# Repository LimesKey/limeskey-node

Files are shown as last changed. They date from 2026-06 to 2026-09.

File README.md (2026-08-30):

# parsnip-node
A battery-powered, portable Meshtastic/Meshcore node built around a Seeed XIAO ESP32-C6, an Ebyte E22P-915M30S LoRa front end, and a u-blox NEO-M9N GNSS receiver. Designed in KiCad, it targets 915 MHz operation in Canada under ISED RSS-247.

## Overview

The goal is a self-contained LoRa node that pairs one of the longest range, best value LoRa modules, with an accurate GNSS reciever, running off a single 18650 cell, to connect to other people on the LoRa mesh network community.

<table>
  <tr>
    <td align="center" width="33%">
      Assembled parsnip-node board on the bench
      <br><sub><b>Assembled board</b></sub>
    </td>
    <td align="center" width="33%">
      parsnip-node during outdoor testing, front
      <br><sub><b>Outdoor testing</b></sub>
    </td>
    <td align="center" width="33%">
      parsnip-node during outdoor testing, back
      <br><sub><b>Outdoor testing, back</b></sub>
    </td>
  </tr>
</table>

## Hardware
 
| Function | Part | Notes |
| --- | --- | --- |
| MCU / radio host | Seeed XIAO ESP32-C6 | Used as an SMD/castellated module for easy soldering|
| LoRa | Ebyte E22P-915M30S | SX1262 + external PA, up to 30 dBm |
| GNSS | u-blox NEO-M9N | GPS / GLONASS / Galileo / BeiDou |
| Boost | TI TPS61033 |  |
| Power mux | TI TPS2116 | USB / battery source selection |
| Battery protection | TI BQ29700 | Single-cell protection |
| Reverse polarity | AO3401A P-channel MOSFET | Input protection |
| Cell | 18650 3500mAh Li-ion | Single cell |
 
### Board
 
- 4-layer, 55 x 100 mm
- JLCPCB `JLC04161H-7628` stackup, 1 oz copper
- L1-L2 prepreg 0.2104 mm, Dk 4.4
- RF: 0.36mm trace width for ~50 Ω CPWG on this stackup, ground rails stitched with 0.3 mm / 0.6 mm vias at roughly 1.5 to 2 mm pitch
  
### SX1262 to ESP32-C6 pin map
 
| Signal | GPIO |
| --- | --- |
| NSS | 21 |
| SCK | 19 |
| MISO | 20 |
| MOSI | 18 |
| DIO1 | 1 |
| BUSY | 7 |
| NRST | 16 |
| EN | 17 |
 
The E22P `EN` (module pin 6) is held high for both RX and TX. The T/R switch (pin 7) is driven automatically from the SX1262 DIO2 line, so the firmware sets `setDio2AsRfSwitch(true)`.
 
## Firmware
 
Firmware is a Meshtastic fork tracked as the `firmware` submodule ([LimesKey/firmware](https://github.com/LimesKey/firmware)). Development uses VS Code with the pioarduino extension, which Meshtastic pins for ESP32-C6 / Arduino-ESP32 3.x support. A device variant declares the pin map above and the PA control lines so TX actually keys up. Unfortunately there are some extensive changes to the Meshtastic firmware in order to incorporate a SPI GNSS module, as this is not natively supported by Meshtastic.
 
```bash
git clone --recurse-submodules https://github.com/LimesKey/parsnip-node.git
```

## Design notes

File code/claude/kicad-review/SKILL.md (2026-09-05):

---
name: kicad-review
description: Query and review KiCad netlists (.net), schematics (.kicad_sch), board placement (.kicad_pcb) and datasheets, and draw schematics: knet.py, kpcb.py, ksch.py, kdoc.py. Use for any question touching a KiCad schematic, netlist, ERC, BOM, footprint, pin, net, connectivity, decoupling or power rail ("what does U2 pin 9 connect to"), and for board layout, placement, floorplan, footprint position, courtyard, edge clearance, mounting hole or keepout ("is U8 too close to the antenna"). `kpcb.py FILE ic U13` also RECOMMENDS where a regulator's caps, inductor and feedback divider go, with a diagram: use it for "where do these go", "lay out this buck/LDO", "minimise the switching loop". Never answer connectivity or geometry from memory or by eyeballing a schematic or board image; exports go stale within a session. Use it too for ANY request to draw or show a circuit, even one not on the board yet: ksch.py draws real symbols from a text spec and hand-written SVG is never right.
---

# KiCad netlist review, placement review and schematic drawing

Four stdlib-only tools in this skill's `scripts/`. Nothing to install.

```bash
K=<skill>/scripts/knet.py   P=<skill>/scripts/kpcb.py
D=<skill>/scripts/kdoc.py   S=<skill>/scripts/ksch.py
```

| question | file | tool | reference |
| --- | --- | --- | --- |
| what is wired to what, values, BOM | `.net` | `knet.py` | [knet](references/knet.md) |
| where is it, does it fit, does it clash, where do the passives go | `.kicad_pcb` | `kpcb.py` | [kpcb](references/kpcb.md) |
| does it pass DRC/ERC, real clearance/rule violations | `.kicad_pcb` + roots | `kdrc.py` | [kdrc](references/kdrc.md) |
| what does the part's datasheet say | PDFs | `kdoc.py` | [kdoc](references/kdoc.md) |
| show me the circuit | - | `ksch.py` | [ksch](references/ksch.md) |

`knet check` and `kpcb check` are heuristics on the netlist and placement;
`kdrc.py` runs **KiCad's own** DRC (honouring `parsnip.kicad_dru`) and ERC, the
authoritative rules check. `kpcb.py FILE zones` reports pour-fill coverage.

`kpcb.py` needs `knet.py` beside it (shared parser) but does **not** need the
`.net` - pads carry their own net names and pin functions. Find the `.net` first:
usually beside the board, else `/mnt/project/*.net` or `/mnt/user-data/uploads/*.net`.
If `*.kicad_sch` files sit beside the `.net`, knet parses them as a sidecar
(no_connect flags, text notes, symbol positions).

## Order of operations

1. **Connectivity, values, footprints, part numbers -> `knet.py`.** The netlist is
   the only authoritative record of what is wired to what.
2. **Position, clearance, floorplan -> `kpcb.py`.** The board file is the only
   record of where anything actually is. Never infer geometry from a screenshot.
3. **Design rules, absolute maximums, recommended values -> `kdoc.py grep`.**
4. **Page image -> only when the drawing itself must be read.** `kdoc.py page DOC N`
   prints a path, then `view` it.

Never derive connectivity from a schematic plot: extracted text is spatially
scrambled. The plot only tells you which sheet a symbol lives on.

## Start here - the highest-value call per tool

| you want | one call |
| --- | --- |
| fresh session on a board | `kpcb.py FILE review` - sync + summary + check + span, then names the next calls to make |
| is the board the circuit I drew | `kpcb.py FILE sync` - **run before quoting any placement finding**; two lines when clean |
| where does X connect / is X right | `knet.py FILE around X` - pins, types, nets, position, every part one hop away |
| where is X, is there room | `kpcb.py FILE where REF` or `where 130,60 -r 10` |
| where do these caps/inductor go | `kpcb.py FILE ic U13` - positions, rotations, the rule behind each, and a picture |
| does the board pass real DRC + ERC | `kdrc.py FILE.kicad_pcb` - KiCad's own checks, all 3 roots, folded like `check` |
| is the ground pour filled / covering | `kpcb.py FILE zones` - fill coverage per copper layer |
| what voltage does this divider set | `knet.py FILE divider U5.OVLO` - nominal + worst case from real resistor values |
| unfamiliar board, what is on it | `knet.py FILE summary` then `check` |
| draw a circuit that exists | `knet.py FILE draw U8 -d 2 -o out.svg` |
| draw a circuit that does not exist yet | write a ksch spec, `ksch.py render` - see [ksch](references/ksch.md) |
| what does the datasheet say | `kdoc.py grep 'Y' --count` to pick the page, then grep with context |

More in [references/recipes.md](references/recipes.md), including the self-test to
run after editing any tool.

## Hard rules

- **Re-run the tool every time.** The `.net` and the board are re-exported
  constantly. Never trust a value, ref, net name or coordinate quoted earlier in
  the conversation, in a summary, or in a CLAUDE.md.
- **Never hand-regex a netlist or board file.** It bleeds nodes across net
  boundaries and produces confidently wrong counts.
- **Never hand-write SVG for a circuit.** `ksch.py` draws real symbols.
- **`check` findings are heuristics.** Confirm against the datasheet
  (`kdoc.py grep`) before calling anything a bug.
- **Output is capped on purpose.** Findings fold into `tail [N]: refs` lines and
  each rule stops after `--max`. The counts in the tails stay accurate even when
  not every item is printed: `+90 more OVERLAP line(s) (102 total)` means 102 real
  findings. Widen deliberately with `--only RULE` or `--max`, never by default.
- **Mid-placement, most of the BOM is parked beside the board.** Every kpcb check
  ignores anything outside the outline. `placed 135 of 439` is progress, not an
  error, and a part "not found" by `where` may not exist on the board yet.

Common traps that produce wrong answers - DNP as open circuit, ref-prefix
matching, rails being terminal, `unconnected-*` pseudo-nets, KiCad's `{slash}`
escaping, board y growing downward - are in
[references/gotchas.md](references/gotchas.md). Read it once per session before
any traversal or coordinate work.

Exit codes (both tools): 0 clean, 1 not found, 2 a check found an ERROR, 3 bad file.

Project config: `knet.json` / `kpcb.json` beside the file persist board defaults
and a `suppress` list for confirmed non-bugs. Precedence: defaults < json < CLI.
See the per-tool references.

# Related

Part sourcing (LCSC/DigiKey pricing, stock, verified datasheet URLs) is the
separate `part-search` skill. `part.py bom board.net` reuses this skill's parser.
Capacitor questions mid-review - "higher voltage rating or higher nominal
capacitance", DC-bias derating, effective uF in a footprint, voltage-stress life -
go to that skill's `kcap.py`, not to hand-computed derating curves.

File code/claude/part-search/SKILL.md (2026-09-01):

---
name: part-search
description: Look up and choose electronic components on LCSC, JLCPCB and DigiKey with part.py. Does parametric selection (e.g. a ceramic cap 4.7uF-100uF rated >=25V, cheapest first), finds cheaper drop-in alternates for a part on the board, reports JLCPCB Basic vs Extended and $3/line assembly fees, runs one-shot board sourcing triage, and returns pricing ladders, stock, MOQ and a verified datasheet URL. Use this whenever the user asks about a specific component, an LCSC C-number, an MPN, a distributor price, whether something is in stock, what a part costs at some quantity, what the datasheet link is, asks to compare two parts, asks to pick or find a part meeting electrical constraints, asks whether a part is JLC Basic, or asks to price or source a whole board. Use it instead of web search for anything part-shaped, and never hand-write a scraping script for LCSC - the working endpoints are already recorded here and the obvious ones are blocked.
---

# Distributor part search and selection

`scripts/part.py` is stdlib-only Python 3. No install, no API key needed for LCSC or JLC.

```bash
P=<this-skill>/scripts/part.py
python3 $P selftest
python3 $P pick MLCC --cap 4.7u..100u --volt '>=25' --pkg 0805 --diel X7R,X5R
```

## Pick the command by what is being asked

| the question | command |
| --- | --- |
| "find me a cap 4.7-100 uF, >=25 V, cheapest" | `pick` - see [pick](references/pick.md) |
| "is there something cheaper than C45783" | `alt C45783` |
| "what does C18164413 cost / is it stocked" | `show` |
| "is this part JLC Basic", "what are my assembly fees" | `jlc` - see [endpoints](references/endpoints.md) |
| "datasheet link for X" | `ds` |
| "X vs Y" | `compare` |
| "what does this whole board cost" | `bom` |
| "source this board" / "what's blocking assembly" | `check` - `bom` + `jlc` + missing-code triage in one call |
| bare MPN, no constraints, just find it | `search` |
| "higher voltage rating or more nominal uF?" / DC-bias derating | `kcap.py` - see [kcap](references/kcap.md) |

`search` is keyword-only and ranks badly on parametric queries.
`search '22uF 25V X7R 1206'` returns electrolytics and tantalums in the top hits,
because LCSC has no category filter. **For anything with electrical constraints, use
`pick`, not `search`.**

## Commands

| command | use |
| --- | --- |
| `pick 'MLCC' --cap 4.7u..100u --volt '>=25'` | parametric selection, sorted, filtered |
| `alt C45783` | cheaper/stocked/Basic equivalents of a part already on the board |
| `jlc board.net` | Basic vs Extended per part + total $3/line assembly fees |
| `show C18164413` | ladder, stock, MOQ, multiple, params, category, verified datasheet |
| `ds C42409135` | datasheet URL only, with pass/fail per candidate |
| `compare C1525 C60474` | side-by-side, differing parameters only |
| `search 'TPS61033'` | keyword search. Add `--instock`. |
| `bom board.net --qty 5` | prices a whole KiCad netlist by its LCSC Part property |
| `check board.net --qty 5` | one-shot sourcing triage: `bom` pricing + `jlc` Basic/Extended, one table, one pass over the netlist |
| `selftest` | which providers and the FX rate source work right now |

`show`, `ds`, `compare` and `alt` accept a C-code, a bare MPN, or a pasted LCSC URL.
`show` with several SKUs prints one verbose block per part by default; `--table`
switches to one compact row per part, `--json` for machine-readable output.
Exit codes: 0 ok, 1 nothing found.

## Run selftest first in a new session

LCSC has no public API. `part.py` uses undocumented endpoints that can start
returning 403/404 without notice. `selftest` reports in one line which providers are
alive, so you never debug endpoints by hand or rebuild a scraper.

If a provider shows DEAD, the endpoint moved. **The constants are at the top of
`part.py`. Do not write a replacement script; fix the constant.** The full probed
endpoint table, and the exhaustive list of LCSC filter/sort parameters that were
tested and do not work, are in [references/endpoints.md](references/endpoints.md).
That file exists so nobody re-probes them. Read it before touching the HTTP layer,
not before a normal query.

## Hard rules

- **Two catalogs, never add them together.** `show`, `search`, `compare`, `bom` and
  `pick --source lcsc` report **LCSC retail** prices. `jlc` and `pick --basic` report
  **JLCPCB assembly-catalog** prices. Different numbers for the same part. Always say
  which one you are quoting.
- **A trailing `!` on a price means FX was unreachable** and the native currency is
  shown unconverted. Never add a `!` price to a converted one. Default currency is
  CAD; LCSC arrives in USD, converted at a daily cached rate with the native figure
  in parentheses. `--currency USD` switches everything.
- **`bom` totals exclude shipping, tax, PCB fabrication and assembly.** Say so when
  quoting a per-board cost. Extended line fees are `jlc`'s job, not `bom`'s.
- **Never regex a netlist for `C\d+`** to find LCSC codes - that matches capacitor
  refdes like `C108`. `jlc`/`bom` parse the `LCSC Part` property via kicad-review's
  `knet.py`.
- **Do not infer Basic/Extended from a JLC keyword search** - its relevance ranking
  drops parts that do exist in the library, showing as a false `-`. Use `--basic` or
  the `jlc` command.
- **Check the `resolved:` line** that `pick` prints when a shorthand mapped to a
  differently-named LCSC attribute. If it resolved wrong, use `--w` with the verbatim
  name.
- **Datasheet links are verified, not returned on faith** (HTTP status, content type,
  `%PDF` magic). A BROKEN report is real - do not paste the URL anyway.

## What the tool does that a hand-rolled script will not

- Verified datasheet links, falling through to the next candidate then the product
  page. Manufacturer links with expiring `?ts=` tokens are exactly what this catches.
- Quantity pricing respects MOQ and order multiple, and says when it rounded up.
- Numeric comparison is numeric - value normalisation drops the decimal point, so a
  text match would treat `2.2uF` and `22uF` as identical.
- Disk cache, 24 h TTL, `~/.cache/partsearch`. A warm `pick` is ~1 s against a ~10-30 s
  cold one. `--fresh` when stock matters.
- `bom` honours DNP and `exclude_from_bom`, and separately lists placed parts with no
  LCSC number at all - the ones actually blocking assembly.

Stock is authoritative from the detail endpoint; a 0 in search results is a real 0.
`pick` shows `unit@N` and `ext` (= unit x the actual buy quantity after MOQ rounding).

DigiKey is optional and participates in `search`/`show` only, not `pick` - setup in
[references/endpoints.md](references/endpoints.md).

## Related

`kicad-review` provides `knet.py`, whose netlist parser `bom` and `jlc` import when
both skills are installed. Without it, `bom` falls back to regex and `jlc` refuses
`.net` input rather than risk matching refdes.

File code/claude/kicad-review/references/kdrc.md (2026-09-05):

# kdrc.py - real DRC + ERC via kicad-cli

The authoritative rules check. `kpcb.py check` and `knet.py check` are heuristics
on geometry and the netlist; `kdrc.py` runs KiCad's **own** Design Rules Check
(which applies `parsnip.kicad_dru` automatically) and Electrical Rules Check, and
folds the results into the same finding format as the other tools.

```bash
D=<skill>/scripts/kdrc.py
python3 $D parsnip.kicad_pcb            # DRC + ERC
python3 $D parsnip.kicad_pcb drc        # DRC only
python3 $D parsnip.kicad_pcb erc        # ERC only, every root schematic
```

## What it does

- **DRC** runs on the board with `--refill-zones` so results reflect current
  pours. It never passes `--save-board`: the refill is in memory, the on-disk
  `.kicad_pcb` is not modified.
- **ERC** runs once per **root** schematic. Roots are auto-discovered: every
  `*.kicad_sch` beside the board that no other schematic pulls in as a sub-sheet.
  For parsnip that is `parsnip`, `battery`, `usb_interface`. A bare single-root
  ERC misses two of them, the same blind spot as a bare netlist export.
- Output: findings grouped by rule, capped per rule with a `+N more` tail,
  suppressible via `kdrc.json`, exit 0/2/3 like `kpcb`.

## The one caveat that matters

**Per-root ERC cannot see cross-root nets.** A pin powered or driven through a
global label whose driver is on another root (`I2C_HOST_*`, `USB D+/-`, the
shared rails) reads as `power_pin_not_driven` or `pin_to_pin` here. Those are
three-root false positives. Confirm each against the merged netlist before
believing it:

```bash
python3 <skill>/scripts/knet.py parsnip-merged.net around REF
```

DRC has no such blind spot - it is one board file.

## Flags

| flag | effect |
| --- | --- |
| `--max N` | cap lines per rule (default 25, or `max` in kdrc.json) |
| `--only R1,R2` / `--skip R` | keep or drop rules by name (e.g. `DRC:CLEARANCE`) |
| `--unconnected` | include the DRC `unconnected_items` (unrouted nets; hidden by default because mid-layout there are hundreds) |
| `--parity` | add DRC schematic-parity. Noisy: it uses the single project root, so it will flag all of /Charger/ and /USB Interface/. |
| `--all` | pass `--severity-all` to kicad-cli. Here kicad-cli already ignores the `.kicad_pro` severities, so this rarely changes anything. |
| `--no-suppress` | ignore kdrc.json |
| `--rules` | print the rule legend |
| `--json` | machine-readable findings |

## kdrc.json (beside the board)

Same shape and precedence as `kpcb.json`. A bare `PREFIX:RULE` mutes the whole
rule; `PREFIX:RULE:TOKEN` mutes only findings whose refs or message contain
TOKEN. Rule names are the kicad-cli `type`, upper-cased, prefixed `DRC:`/`ERC:`.

```json
{"max": 25,
 "suppress": ["ERC:LIB_SYMBOL_MISMATCH", "ERC:SINGLE_GLOBAL_LABEL",
              "ERC:ISOLATED_PIN_LABEL", "ERC:FOUR_WAY_JUNCTION"]}
```

Pre-muted classes and why: `LIB_SYMBOL_MISMATCH` = the 16 deliberately edited
symbols (CLAUDE.md); `SINGLE_GLOBAL_LABEL` / `ISOLATED_PIN_LABEL` = global labels
that join across the three roots and so look single-use per root;
`FOUR_WAY_JUNCTION` = drawing style. `pin_to_pin`, `power_pin_not_driven` and
`footprint_filter` are left visible on purpose - triage them, then add the
confirmed-benign ones here.

## Notes

- ERC item positions are sheet-local coordinates, not board mm; the ref is the
  locator. DRC item positions are board mm and are kept in the message.
- kdrc shells `kicad-cli` (KiCad 8-10). If it is not on PATH, kdrc exits 3.
- Mid-layout, DRC `unconnected_items` (unrouted) dominate. Route first, then care
  about them; until then `--unconnected` is opt-in.

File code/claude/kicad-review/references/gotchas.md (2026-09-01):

# Facts that are easy to get wrong

Read this once per session before any traversal or coordinate work.

## Netlist

- **The `.net` is re-exported constantly.** Re-run the tool. Do not trust a value,
  ref or net name quoted earlier in the conversation or in a summary.
- **DNP parts are open circuits by default.** A DNP 0 R in series means the path
  does not exist on the built board; `walk`/`path`/`draw` stop there. `--as-drawn`
  restores schematic-as-drawn traversal; DNP parts still render, dashed.
- **Ref prefix matching must use the full alphabetic prefix.** `JP` is not `J`.
- **Rails are terminal in traversal.** A path through GND or +3V3 is not a path.
  Treat nets over ~8 nodes as rails.
- **Floating pins rarely show as "absent from all nets".** KiCad emits pseudo-nets
  named `unconnected-(REF-PIN-PadN)`. A **named** single-node net is usually a real
  bug (a label going nowhere); `unconnected-*` is an intentional NC or a forgotten
  pin - the sidecar NC annotation tells you which.
- **A part is pass-through if it has exactly two connected pins**, rails included.
  Series resistors bridge two nets: trace both ends.
- **KiCad escapes text**: `{slash}` is `/`, `~{FLT}` is an overbar. Drawings decode
  both; netlist queries use the raw escaped name.
- **Label *shape* is cosmetic; only the *name* connects.**

## Board

- **Mid-placement, most of the BOM is parked in a pile beside the board.** Every
  kpcb check ignores anything whose centre is outside the outline, or the pile would
  drown the findings. `placed 135 of 439` in a header is progress, not an error. A
  part "not found" by `where` may simply not exist on the board yet.
- **`.kicad_pcb` y grows downward** and rotation is counter-clockwise on screen, so
  a footprint's child geometry transforms as `x + lx*cos - ...`, not the textbook
  rotation. `where` already prints board coordinates; do not re-derive them from
  `(at ...)` by hand.
- **A `.kicad_pcb` pad carries its own net name and pin function**, so kpcb needs no
  `.net` export. That also means the board can be out of date with the schematic: if
  kpcb and knet disagree about a net, the board has not been re-synced. Run
  `kpcb.py FILE sync` before quoting any placement finding.
- **Ref designators move during layout.** Do not cache them across sessions.

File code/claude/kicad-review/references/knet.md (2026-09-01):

# knet.py - netlist connectivity, values, ERC, BOM

`knet.py FILE <cmd>` - file first, then subcommand.

| command | use |
| --- | --- |
| `summary` | comps, sheets, rails, DNP list, largest nets. Run first on an unfamiliar board. |
| `around REF...` | **highest value per call.** Pins, types, nets, position, every part one hop away. Use instead of `comp` + several `pin` calls. |
| `check` | 16 rule-based findings, grouped ERROR/WARN/INFO. Exit 2 if any ERROR. Three or more findings sharing a message fold into one line, `tail [N]: refs` - `[49]` means 49 separate findings, not one. |
| `check --since old.net` | only findings NEW vs an older export, plus a fixed/unchanged tally. |
| `draw REF\|NET [-d N] [-o x.svg] [--spec]` | KiCad-style schematic from the netlist; `--spec` gives the editable ksch source. |
| `notes` | schematic text notes by sheet - designer intent that exists nowhere in the netlist. |
| `rails` | each power rail: what feeds it, total decoupling, loads. |
| `divider REF.PIN\|NET` | resistor-divider trip voltage from netlist resistor values, worst case from tolerance if stated. See below. |
| `diff old.net` | what changed vs an earlier export (rename-safe: compares neighbour sets). |
| `comp REF...` | pin table with net, node count, supply rail. |
| `net PATTERN` | exact name, then sheet-local name, then regex. |
| `pin U2.9` | net at a pin plus everything else on it. |
| `find PATTERN` | searches refs, values, footprints, properties, pin functions, net names. |
| `walk REF[.PIN] -d N` | expand outward through 2-pin passives. |
| `path A B` | shortest electrical path between two parts. |
| `bom [--sheet PATH]` | grouped, DNP separated, flags parts with no LCSC number. `--sheet /Root/Rails/` scopes to one hierarchical sheet and everything nested under it. |
| `unconnected` | floating pins, `[NC flag]` vs `[NO NC flag]` with the sidecar, plus single-node nets. |
| `sheets` | components per hierarchical sheet. |

## Reading `around`

One line per pin, then its peers indented under it. The pin-type column is omitted
when the symbol types every pin `unspecified` (easyeda2kicad does), so a missing
type means unknown, never `passive`. A net already shown on an earlier pin of the
same part prints bare, or `(peers listed at pin N)` - that is two pins on one net,
not a different net.

## `divider`

`REF.PIN` accepts the pin's declared NAME (`U5.OVLO`, or the raw KiCad-escaped
`U14.EN{slash}UVLO`) as well as its number. Handles a plain 2-resistor divider
automatically. For TI's 3-resistor UVLO/OVLO string
(`IN->R1->EN/UVLO->R2->OVLO->R3->GND`, every TPS2594x/hot-swap part) it auto-detects
the shape and reports VIN_UV/VIN_OV once given `--vth <threshold from the
datasheet>`; add `--vth-tol <%>`, since the IC's own threshold accuracy usually
dominates the resistor tolerance. Use it for any FB/OVLO/UVLO/ADC-sense divider
instead of tracing it by hand across several `pin`/`net` calls.

## Flags

`--through R,L,FB,F,FL,JP` (pass-through prefixes; add `C`/`D` to trace through caps
or diodes), `--fanout N` (nets above N nodes are rails, default 8), `--as-drawn`
(traverse DNP parts too; **default treats DNP as open circuits**),
`--rail '+5V=5,VCC_RF=3.3'`, `--peer-max N`, `-o FILE`, `--spec`, `--theme`,
`--json`, `--only`/`--skip RULE,RULE`, `--rules` for the rule legend,
`--no-suppress` (for `check`), `--sheet PATH` (for `bom`), `--vth V` /
`--vth-tol PCT` (for a 3-resistor `divider`).

`walk` caps a rail's load list at 10 with a `+N more (rail net, N total)` tail once
a net is a named rail or above `--fanout`. The count in the tail stays accurate even
when not every load is printed.

## Project config

`knet.json` next to the netlist persists board defaults:

```json
{"rails": {"+BATT": 8.4}, "fanout": 8, "suppress": ["RFSTUB:GPS_ANT", "OCNOPULL:U9"]}
```

Precedence: defaults < knet.json < CLI.

`suppress` mutes `check` findings already confirmed not to be bugs, so they stop
costing tokens on every future review instead of restating "don't re-flag this"
each session. An entry is `"RULE"` (mute the whole rule) or `"RULE:TOKEN"` (mute
only findings naming that ref or net - a confirmed false positive on one net must
not hide a real one elsewhere). `check` reports how many it muted; verify the count
looks right, and use `--no-suppress` after a big rewire to see everything again.

## check rules

`FLOATPWR NCDRIVEN SOLO CONTEND DOMAIN DECOUPLE OCNOPULL I2CPULL PASSONLY RFSTUB
DNPPATH CAPRATING NOVALUE GNDISLAND CLAMPRATING PARPIN`. `--rules` for one-line
descriptions. With the sidecar, FLOATPWR downgrades to WARN when the schematic
carries an explicit NC flag.

- **`DOMAIN`** is the useful one: it infers each net's pulled-to voltage from series
  resistors and ferrites to named rails and compares against each IC's supply rail,
  catching pull-ups to 5 V on 3.3 V logic.
- **`PARPIN`** catches a paralleled pad left floating: two or more pins on the same
  part sharing the same declared pin NAME (e.g. multiple BAT pins on a charger IC)
  where one is wired to a real net and a sibling is not. Matches on pin name rather
  than pin type, so it still fires when the symbol types the dangling pin `passive`
  rather than `power_in` - the case that let a real floating BAT pin slip past
  FLOATPWR.
- **`CLAMPRATING`** parses a TVS's standoff voltage from a recognised part-number
  series (SMF/SMAJ/SMBJ/SMCJ/SM6T/SM8S/P6KE/1.5KE/P4KE) and flags it against the
  named rail it sits on between rail and GND - narrow by design (only those series,
  no margin math beyond "not below") to avoid a confidently wrong number. The rail
  figure is name-derived or `--rail`/knet.json, not the regulator's true analog
  output, so a finding here can understate the real gap; it will not overstate it.
- **`GNDISLAND`** catches a different shape of bug than FLOATPWR: pins named like
  ground (GND, AGND, VSS, ...) that ARE wired to each other but never reach the
  board's real GND net - a merge that silently didn't happen. `is_gnd()` recognises
  these by pin name even on an auto-generated net (`Net-(U7-GND-Pad1)`), so DECOUPLE
  no longer misfires on them as "missing a bypass cap".

**These are heuristics. Confirm against the datasheet before calling anything a
bug.** Worked example: `U7.5 (FB)` on a TPS61033 sat on the same net as `VIN` -
looks like a broken feedback loop, but the datasheet says that is the documented
fixed-5.0 V configuration. The correct move was `kdoc.py grep 'FB' -d tps` first.

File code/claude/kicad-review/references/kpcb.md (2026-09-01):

# kpcb.py - placement review

Placement review from the `.kicad_pcb` alone. No routing, no DRC, no 3D bodies -
everything here is checkable the moment a footprint is dropped.

| command | use |
| --- | --- |
| `summary` | outline size, stackup, zones, how much of each sheet is placed, biggest parts. Run first. |
| `check` | 10 rule-based findings, grouped ERROR/WARN/INFO. Exit 2 if any ERROR. |
| `where REF...` | **highest value per call.** Position, rotation, courtyard, edge distance, class, nets, and every neighbour within `-r`. Use instead of eyeballing coordinates. |
| `where X,Y -r N` | same, around a bare coordinate - "is there room here". |
| `map [--side f\|b] [--cols N]` | ASCII occupancy map, one letter per schematic sheet. Shows the floorplan and the free space in ~50 lines. |
| `sheet [PATH]` | per-sheet placed/left counts, bounding box, spread, and parts that drifted from their block. |
| `unplaced` | what is still parked off the outline, ref-ranged by sheet, biggest first. |
| `ic REF` | **where the passives should go**, not just what is wrong. See below. `ic` alone lists the parts worth asking about. |
| `span` | nets ranked by how far apart their placed pads sit. The one routing-quality number that exists before routing does. |
| `sync [board.net]` | **run this first.** Board vs netlist: same parts, footprints, values, DNP flags and net on every pad. Finds a `.net` beside the board automatically. |
| `review [board.net]` | one call for a fresh session: sync, summary, check, longest nets, then the specific next calls worth making. |

## Flags

`-r N` (neighbour radius, 5), `--max N` (cap per rule / per neighbour list, 12),
`--cols N` / `--side f|b` (for `map`), `--only`/`--skip RULE,RULE`, `--rules`,
`--json`, `--no-suppress`, and one threshold per rule: `--edge 0.5` `--hole 1.5`
`--conn 10` `--rf 8` `--therm 8` `--bypass 3` `--clear 0` `--fb 4` `--gap 0.25`
`--tol 1` `--span 0` (all mm; `--span 0` means half the board diagonal), plus
`--fanout 8`. For `ic`: `--anchor REF`, `--cin REF,REF`, `--cout REF,REF`,
`--ncin 3`, `--ncout 3`, `--assoc 6`.

## Project config

`kpcb.json` next to the board, same shape and precedence as `knet.json`:

```json
{"edge": 0.3, "bypass": 4.0, "suppress": ["OVERLAP:BT1", "UNPLACED"]}
```

Use `suppress` for placements already confirmed deliberate (thermistors under a
cell, a module antenna overhanging the edge) so they stop costing tokens on every
review.

## `sync` - is the board even the circuit you drew

`kpcb.py board.kicad_pcb sync` (the `.net` beside the board is found on its own).
**Nothing else here means anything if this fails.** A board that was never
re-synced after a schematic change carries pad net names that look perfectly valid,
so neither the board file nor any check on it can tell you it is stale - only the
netlist can. Rules: `SYNCPART SYNCFP SYNCVAL SYNCDNP SYNCNET`.

Clean output is two lines (`IN SYNC`), so it is cheap to run every time. A `SYNCNET`
error means re-run KiCad's *Update PCB from Schematic* before reading any other
finding. `SYNCVAL`/`SYNCDNP` alone are annotation drift: worth fixing, but the
connectivity is still right and placement findings still hold.

`unconnected-*` pseudo-nets get a `_1` suffix on the board and not in the netlist;
that is normalised away rather than reported as 439 differences.

## `review` - the whole placement picture in one call

Runs sync, `summary`, `check` and the top of `span`, then prints a **next** block
naming the exact calls worth making on *this* board - `ic` on the unplaced
regulators, `where` on whichever refs appear in the most ERROR findings, `map` if
much is still unplaced. That last block is the point: it is the reasoning a session
would otherwise have to do itself from a summary it has not read yet. If the board
is out of sync it says STOP and explains that everything below is about a different
circuit.

## check rules

`OVERLAP EDGECLR HOLECLR CONNACC RFNOISE THERMAL BYPASS NETSPAN NOCRTYD UNPLACED`.
`--rules` for the legend.

- **`OVERLAP`** compares courtyard **bounding boxes**, not their true outlines, so a
  rotated or L-shaped part reports a slightly larger box than it occupies -
  conservative, never permissive. Parts on opposite sides only collide where a
  drilled barrel actually lands in the other's area; a back-side battery holder
  sitting over front-side 0402s is not a finding.
- **`EDGECLR`** is an ERROR when the courtyard crosses the outline, a WARN when it
  is merely inside `--edge`. An edge-mount part (SMA, U.FL, USB-C, `EdgeMount` in
  the footprint name) crossing the edge downgrades to INFO - that is what it is for.
- **`HOLECLR`** keepout radius is the hole's own pad/drill radius plus `--hole`. It
  also catches a mounting hole placed outside the board entirely.
- **`CONNACC`** has two halves: a connector further than `--conn` from any edge, and
  a connector whose cable-exit corridor (its courtyard swept straight out to the
  nearest edge) is blocked by another part. The corridor is axis-aligned only - a
  diagonal exit is not modelled, and neither is component height.
- **`RFNOISE`** needs a switching node. Those are found by pin NAME (`SW`, `LX`,
  `PH`, ...) plus, as a fallback for a switcher whose pin is unnamed, the nets of a
  power inductor (>=1uH **and** >=6 mm2 of courtyard, which is what separates a buck
  inductor from a 470nH 0603 antenna match). Named power rails are excluded, or
  every load on +3V3 would look noisy.
- **`THERMAL`** pairs heat sources (power inductors, switching/charger/eFuse/LDO
  parts) against heat-sensitive ones (crystals, oscillators, battery cells, the GPS
  module). Thermistors are deliberately **not** sensitive - sitting next to
  something hot is their job. Cross-side pairs are reported and labelled: heat
  couples through the board.
- **`BYPASS`** measures each supply pin to the nearest **placed** cap on the same
  net. It stays quiet when no cap on that net is placed yet. Matched on pin NAME,
  never on `pintype`: easyeda2kicad types nearly every pin `passive`, so a
  type-based test would silently check nothing - the same trap `PARPIN` documents
  in knet.
- **`NETSPAN`** is the only rule that looks at wiring: a **fully placed** non-rail
  net whose pads sit further apart than `--span` (default half the board diagonal).
  Fully placed only, because a net still waiting on parts will move. Rails are
  excluded by node count **and** by name. `span` is the detailed view of the same
  data, ranked and capped.
- **`UNPLACED`** prints **one folded line per sheet**, never one per part.
- Two things that used to fire on a half-placed board and no longer do: a mounting
  hole sitting in the parked pile is INFO, not an ERROR about being off the board
  (an error still, if it is out there on its own); and an RF module whose antenna
  end overhangs the outline is INFO with a note to check the keepout, because that
  is how a WROOM or an E22 is meant to be placed.

**These are geometric heuristics.** They know nothing about component height, the
enclosure, keep-out zones you have not drawn, or your assembler's rules. Confirm
anything that matters against KiCad's own DRC and the mechanical drawing.

## `ic REF` - where the passives go

The only command here that answers "where should this go" instead of "what is
wrong". One call per regulator, ~35 lines, no reasoning required from the caller.
Run `ic` with no ref first to see which parts it can advise on.

Nothing is templated per part number: pins are classified by NAME (`VIN` `PGND`
`SW` `FB` `BOOT` `VCC/BIAS` `OUT`, with a blank pin sitting on GND counted as a
ground pin), and every position comes out of the real pad coordinates in the board
file. So a part it has never seen works, and a part whose pins are unnamed degrades
to "nothing positionable found" rather than to a confident wrong answer.

| role | where it is put | why |
| --- | --- | --- |
| input caps | straddling the **tightest VIN/PGND pad pair**, on the outside face of the package, smallest value innermost, extra caps stacked outward | that pad pair carries the high-di/dt loop; a cap across it *is* the small loop |
| inductor | hard against the SW pad(s), body pointing away from the package. Two switch nodes (a 4-switch buck-boost like the BQ25798) -> it bridges them instead | SW-pad-to-inductor is the other edge of the same loop, and the SW node is the antenna |
| output caps | a bank across the output node at the inductor's far pad, largest first | load current flows through them; a line of caps end to end would put the last one 25 mm downstream |
| feedback divider | out the far side of the package from SW, FB pad facing the IC | FB is the high-impedance node; it must not run past the SW pad or under the inductor |
| boot / bias caps | against the pins they serve | small loops of their own |
| a linear reg or load switch | no inductor, so the output cap straddles OUT/GND the same way the input cap straddles IN/GND | same rule, no switching node |
| a plain IC (no VIN pin) | supply pins found via the same name table `BYPASS` uses, caps straddling supply/GND | bypass placement is the loop rule at a smaller scale |

Rotations are snapped to 90 degrees. A pin pair on a diagonal would otherwise ask
for a 165.3-degree part, and the few degrees of loop cost nothing.

**`--anchor` is what makes it usable mid-placement.** The big parts land first, so
the inductor is usually down while the regulator is still in the parked pile. Given
that, "L4 is 90 mm from its slot" is true and useless - the inductor is not what
should move. So when the IC is unplaced and one of its passives is not, `ic` hangs
the whole layout off that part and reports **where the IC itself goes**.
`--anchor REF` picks a different one, `--anchor none` turns it off. Translation
only: if the anchor also needs turning, it says so and asks you to rotate the IC in
KiCad and re-run, because rotating it moves every pad.

The `now` column compares against what is already placed: `OK` (within `--tol`),
`4.8 mm / 90 deg off`, or `unplaced`. It also reports parts standing in a suggested
slot, feedback parts within `--fb` of a switching node, and the current input-loop
length against the suggested one.

**The honest limit is which caps belong to which regulator.** On a rail like `VSYS`
(20+ caps here) nothing in a `.kicad_pcb` says which cap the schematic drew next to
which pin. `ic` ranks by schematic sheet and by refdes proximity to the IC's own
private-net parts, prefers one cap of each distinct value so "smallest innermost"
means something, takes `--ncin`/`--ncout` of them, and **says in the output that it
guessed**. Two regulators on one rail can be offered the same cap. Check it against
the schematic and pass `--cin`/`--cout` once - that is the one number worth a
second call.

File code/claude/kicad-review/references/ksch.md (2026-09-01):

# ksch.py - drawing circuits

**Never hand-write SVG for a circuit, and never build one in the visualizer.**
Write a short spec, pipe it to `ksch.py`, `present_files` the `.svg`. A spec is ~20
short lines where hand-drawn SVG is hundreds, and the result looks like KiCad
instead of like boxes with text in them.

| situation | do this |
| --- | --- |
| the circuit is on the board | `knet.py FILE draw U8 -d 2 -o out.svg` - laid out from the netlist |
| ...and needs tidying | `knet.py FILE draw U8 --spec > x.ksch`, edit, `ksch.py render x.ksch -o out.svg` |
| the circuit is proposed / from a datasheet | write the spec by hand (below) |

## Spec language

One statement per line, `#` comments. Grid unit = 2.54 mm = 100 mil, **+y is down**.
Coordinates are integers. **Two-pin parts are 2 units long and the coordinate you
give is pin 1**, so `r R1 4,2 v` puts pin 1 at (4,2) and pin 2 at (4,4).

```
title  <text>
ic   REF x,y NAME [w=N] [h=N] [p=N] [flat] [dnp] L:1=EN,2=IN R:6=OUT T:5=VCC B:8=GND
conn REF x,y NAME R:1=VBUS,2=GND               connector / one-sided box
r|c|cp|l|fb|d|ds|dz|led|tvs|sw|fuse|xtal|bat|jp|tp|ant  REF x,y [ORIENT] [value] [dnp]
nmos|pmos|npn|pnp  REF x,y [l] [value]
wire  A.1 B.2 [12,4 ...]             orthogonal route; extra x,y are waypoints
net   NAME [@x=N|@y=N] A.1 B.2 ...   named net; @x/@y gives it a trunk column/row
gnd   A.2 [earth]                    pwr  +3V3 A.1
label NAME A.1     hlabel NAME A.1 [in|out]     glabel NAME A.1
nc    U1.7         note x,y <text>              group x,y w,h <text>
```

- `ic` anchor is the **top-left of the body**; pins run down each side at 2-unit
  pitch in the order listed, and `L:1=EN,,3=RST` leaves a blank slot to keep
  alignment. Height and width are automatic unless you set `h=`/`w=`.
- ORIENT: `v` (default, pin 1 top) `h` (pin 1 left) `vr` (pin 1 bottom) `hr` (pin 1
  right). Transistors: gate/base left by default, `l` mirrors, anchor is the gate or
  base pin, drain/collector down-side of the channel; p-channel and PNP are drawn
  source/emitter up, the way they are actually used.
- Address pins by number or name: `U8.6`, `U8.OUT`, `Q1.g`, `D1.k`, `R1.2`.
- Junction dots, routing and text placement are automatic. A wire always leaves a
  pin the way the pin faces, so it never dives back through its own body.

## Worked example

One bash call, then `present_files`:

```bash
python3 $S render -o /mnt/user-data/outputs/efuse.svg - <<'EOF'
title U8 GNSS eFuse
ic U8 12,2 TPS259474L L:1=EN/UVLO,2=OVLO R:6=OUT T:5=IN B:8=GND
r R40 4,3 v 100k
r R41 4,9 v 150k
c C40 7,3 v 1uF
pwr +3V3 U8.5
pwr +3V3 R40.1
gnd U8.8
gnd R41.2
gnd C40.2
wire R40.2 R41.1
wire R40.2 U8.1
wire C40.1 7,1 U8.5
label 3V3_GNSS U8.6
nc U8.2
EOF
```

## Getting it right first time

- `ksch.py syms` prints every symbol with its pins and anchor; read it once per
  session if you need a part you have not drawn before. `ksch.py help` prints the
  full language.
- **`--net board.net` is the accuracy feature.** It fills IC pin names and values
  from the netlist, so `ic U8 10,4 @` alone draws the whole part correctly, and it
  verifies every drawn connection against the real board: a wire the board does not
  have, a pin number the part does not have, or a label sitting on the wrong net all
  come back as errors. Use it for any diagram of a circuit that exists.
- Errors name the line and say what was expected. Fix and re-run; do not fall back
  to hand-written SVG.
- The tool also warns about overlapping bodies, wires crossing a body, and pins
  drawn but left unwired.
- Flags: `--theme kicad|mono|dark`, `--px N` (22), `--us` (zigzag resistors),
  `--grid`, `--frame`, `--quiet`. Exit 3 = spec error, 2 = verify found an error.
- Layout habits that avoid rework: 5-6 units between columns, 3 between rows, inputs
  left, outputs right, supplies up, grounds down. Put a `pwr`/`gnd` symbol on every
  rail pin instead of running long wires, and use a `label` instead of dragging a
  wire across the sheet.

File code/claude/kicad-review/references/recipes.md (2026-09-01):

# Recipes

**"Review this board's layout"** - one call: `kpcb.py FILE review`. It ends by
naming the next calls to make, so there is nothing to work out first.

**"Did the board get updated from the schematic?"** `kpcb.py FILE sync`. Two lines
when clean. Run it before quoting any placement finding.

**"Review this placement / where should X go?"** `kpcb.py FILE summary`, then
`check`, then `map` to see the free space, then `where REF` on anything the check
named. `sheet` tells you which blocks are still scattered. Say plainly that these
are geometric heuristics.

**"Is there room for X here?"** `kpcb.py FILE where 130,60 -r 10`. One call.

**"Where do I put the caps around U13 / how do I lay out this buck?"**
`kpcb.py FILE ic U13`. One call gives positions, rotations, the reason for each and
a picture. Do not reason it out from pad coordinates by hand, and do not answer it
from the datasheet's layout figure alone - the figure does not know where this
board's inductor already is.

**"Which nets are stretched across the board?"** `kpcb.py FILE span`. Answers the
routing question that is answerable before routing exists.

**"Review this board."** `summary`, `check`, `around` each flagged IC, `divider` on
any FB/OVLO/UVLO net that check or around surfaces, then `kdoc.py grep` the
datasheet rule for anything that looks wrong. Say plainly which findings are
unconfirmed heuristics.

**"Where does X connect / is X right?"** `around X`. One call.

**"What voltage does this divider set / is this OVLO threshold right?"**
`divider REF.PIN` (the IC pin, e.g. `U5.OVLO`) or `divider NET` directly - one call
gives nominal and worst-case trip voltage from the actual resistor values and
tolerances, instead of `pin`/`net`/`comp` calls plus doing the math by hand.

**"Draw / show me / how do I wire ..."** On the board:
`knet.py FILE draw X -d 2 -o out.svg`. Not on the board yet: hand-write a ksch spec,
adding `--net FILE` if part of it exists. Then `present_files`.

**"What changed?"** `diff old.net` for wiring, `check --since old.net` for findings.

**"What does the datasheet say about Y?"** `kdoc.py grep 'Y' --count` for the page,
then grep with context, or `page` + `view` for figures.

# Self-test after editing a tool

```bash
python3 $K references/selftest.net check          # 4 error, 6 warn, 1 info
python3 $K references/selftest.net walk /DANGLE   # stops at DNP R2
python3 $K references/selftest.net draw U1 -d 2 -o /tmp/t.svg
python3 $K references/selftest.net divider /VSENSE  # 1.6667 V nominal, 1.6445-1.6890 V worst case
python3 $S render -o /tmp/t2.svg references/selftest.ksch   # no ERROR lines
python3 $P references/selftest.kicad_pcb check    # 4 error, 7 warn, 2 info; exit 2
python3 $P references/selftest.kicad_pcb summary  # 40 x 30 mm, placed 16 of 20
python3 $P references/selftest.kicad_pcb map      # 40x30 grid, no '*' outside a part
python3 $P references/selftest.kicad_pcb span     # 1 net (NB, 0.5 mm); rails excluded
python3 $P references/selftest.kicad_pcb sheet    # /Test/ 16 placed, /Test/Spare/ 4 left
python3 $P references/selftest.kicad_pcb sync references/selftest.net
                                      # 23 error, 7 warn; exit 2. The two fixtures
                                      # are deliberately different circuits, so this
                                      # is the negative test: all five SYNC rules fire
                                      # at once. `sync` on a real board+net that match
                                      # prints IN SYNC in two lines.
python3 $P references/selftest.kicad_pcb ic       # "no regulator-shaped part found"
```

The fixture has no regulator, so `ic` is exercised against the real board instead:
`kpcb.py board.kicad_pcb ic` must list the switchers, and `ic <a buck>` must name an
input cap, an inductor and a feedback part and print a diagram whose IC body is
visible inside the frame. A blank-looking frame means the anchor shift was applied
to the slots but not to the IC's own geometry.

`selftest.kicad_pcb` is a 40x30 mm fixture carrying one deliberate fault per rule,
including both `EDGECLR` severities (R4 crosses, R5 is merely close), both `CONNACC`
halves (J1 buried, J3's exit blocked by C2) and both `OVERLAP` cases (R1/R2 same
side, TP1's drill under U1 from the back). If a rule stops firing on it, that rule is
dead - kpcb's thresholds are loose enough that a clean board reports nothing, which
looks identical to a broken check.

**After editing SKILL.md or any reference file**, re-run the self-test above and
confirm the counts still match. They are the only thing that distinguishes a working
rule from a silently dead one.

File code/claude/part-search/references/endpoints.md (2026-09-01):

# Endpoints, and the things that were already tried

Read this before touching `part.py`'s HTTP layer. Do not re-probe what is here.

## Endpoint status as recorded (probed 2026-08-18)

| endpoint | status |
| --- | --- |
| `wmsc.lcsc.com/ftps/wm/product/detail` | works, detail by C-code, full parameters |
| `easyeda.com/api/eda/product/search` (POST, form-encoded) | works, keyword search, `pageSize` up to 200 |
| `jlcpcb.com/api/overseas-pcb-order/v1/shoppingCart/smtGood/selectSmtComponentList` (POST, JSON) | works, no auth, 200 rows/call **with parsed attributes** |
| `wmsc.lcsc.com/wmsc/product/detail` | dead, 404 JSON |
| `wmsc.lcsc.com/ftps/wm/search/global` | blocked, Akamai Access Denied |
| `wmsc.lcsc.com/ftps/wm/{search/product,product/search,product/list,catalog/list}` | dead, "static resource unavailable" |
| `cart.jlcpcb.com/.../selectSmtComponentList` | superseded by the `jlcpcb.com/api/...` path above |

The constants are at the top of `part.py`. When `selftest` shows DEAD, fix the
constant. Never write a replacement scraper.

## LCSC cannot filter or sort server-side. Do not go looking again.

Probed exhaustively against the easyeda search endpoint: `sortField`, `sortOrder`,
`orderBy`, `catalogId`, `paramNameValueMap`, `attributes`, `paramList`, `filters`,
`paramValueList`, `selectedParams`, `paramMap`, `attributeFilter`, `params`,
`searchParam`, `stockFlag`. Every one either changed nothing or returned `total=0`.
Its search rows carry **no parameters at all** - only mpn, number, manufacturer,
package, stock, price, url. `needAggs=true` returns facet lists but they cannot be
sent back as filters.

This is why `pick` works the way it does: LCSC candidates must be fetched by
`product/detail` one at a time to learn their parameters. That is cached and parallel,
so it is fast, but it is why there is a `--pool` cap.

## JLCPCB Basic vs Extended

LCSC has no concept of "Basic" - it is a JLC assembly-library field. So:

- `--basic` pools straight from JLC's base library (server-side filter, authoritative,
  ~1 call per keyword, and much faster than filtering LCSC results).
- Without `--basic`, `pick` annotates only the rows it finally displays, one lookup per
  C-code. The `jlc` column shows `BASIC`, `ext` or `-`.
- **Do not infer Basic/Extended from a JLC keyword search**: its relevance ranking
  drops parts that do exist in the library, which shows up as a false `-`.

```bash
part.py jlc /mnt/project/meshtastic.net       # whole board, with refdes
part.py jlc C45783 C1525 C2650956
```

For "source this whole board" or "what's blocking assembly", use `check board.net`
instead of running `bom` then `jlc` separately - one netlist parse, one table with both
LCSC price and JLC Basic/Extended per line, plus the components with no LCSC code at
all (the ones actually blocking assembly, not just costing more).

`jlc` on a `.net` file parses the `LCSC Part` property via kicad-review's `knet.py`.
It must not regex for `C\d+` on a netlist - that matches capacitor refdes like `C108`.

## DigiKey setup

Optional. LCSC and JLC work with no configuration. For DigiKey, get free credentials at
developer.digikey.com (create an app, Production, Product Information V4), then:

```bash
export DIGIKEY_CLIENT_ID=...
export DIGIKEY_CLIENT_SECRET=...
```

or write `~/.config/partsearch/config.json` as
`{"digikey_client_id": "...", "digikey_client_secret": "..."}`.

Defaults are `--site CA --currency CAD`. The OAuth2 token is cached with its expiry.
DigiKey participates in `search`/`show` only, not in `pick`.

The DigiKey response normaliser (`_dk_norm`) has not been exercised against a live v4
response. If `selftest` shows auth OK but search DEAD, the field mapping there is the
place to look, not the request code.

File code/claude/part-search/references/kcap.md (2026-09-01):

# kcap.py - MLCC effective-density and voltage-stress-life comparator

Answers "higher voltage rating or higher nominal capacitance?" objectively -
minimising capacitor volume while keeping *effective* uF (after DC-bias derating,
density-driven dielectric thinning, temperature and aging) and wear-out life in spec.
Fully offline by default (fitted formulas); imports this skill's own `part.py` client
automatically when present for LCSC C-number resolution and a live density-ceiling
refinement, but never requires it.

```bash
python3 $skill/scripts/kcap.py compare '10u/25V/X5R/0805' '10u/25V/X7R/1206' --vop 8.4 --temp 45
python3 $skill/scripts/kcap.py compare C19666 C1791 --vop 5.0        # LCSC C-numbers work too
python3 $skill/scripts/kcap.py solve MLCC --need 8uF --vop 8.4 --temp 45   # smallest/cheapest that clears it
```

A spec string is slash-separated and order-independent: `CAP/VOLT/DIEL/PKG`, e.g.
`10u/25V/X5R/0805` or `22nF/50V/C0G/0603`.

**`--vop` is required** - the actual operating voltage the part will see. Never assume
Vrated. Full flag reference: `python3 $skill/scripts/kcap.py --help`.

## Model and its limits

`eff_C = C_nom * bias * densitySeverity * tempPenalty * agingPenalty`, reported as
retained %, effective uF, uF/mm^3, uF/mm^2, % of density ceiling, and a relative
voltage-stress life verdict.

Case L/W is confirmed against manufacturer dimension tables; H is the middle of
KEMET's documented per-case thickness-code range (it varies with capacitance and layer
count within one case code - override with `--dim-a`/`--dim-b` `L,W,H` for a specific
real SKU when it matters).

Voltage-stress life covers TDDB/insulation-resistance wear-out only, **not** flex
cracking, thermal cycling or moisture, which dominate real field failures.
`L_ref`/`T_ref`/`Ea` are an assumed illustrative reference point, not a
datasheet-certified figure; override with `--lref-hours`/`--tref`/`--ea` if a
manufacturer publishes real endurance numbers.

MLCC aging is referenced to 1000 h, not t=1 h.

## Verified on parsnip

- X7R beat X5R on effective uF at every bulk position checked.
- Density traps: 10uF/25V in 0603, and 10uF/50V in 0805, both lose 35-45% to bias at a
  typical ~50% Vrated operating point - use 0805/1210 instead.
- A smaller case usually still wins on uF/mm^3 despite steeper derating, unless run
  near rated voltage.
- At 2.5x or more Vrated/Vop, voltage-stress life is never the binding constraint
  (2.5x margin gives ~15.6x relative life, matching `n=3`).

For a capacitor question that comes up mid netlist review, use this instead of
hand-computing derating from a datasheet curve.

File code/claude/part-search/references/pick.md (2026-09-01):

# pick - parametric selection

```bash
part.py pick MLCC --cap 4.7u..100u --volt '>=25' --pkg 0805 --diel X7R,X5R --qty 100
part.py pick MLCC --cap 10u --volt '>=25' --pkg 0805 --basic      # no $3 line fee
part.py pick 'schottky diode' --vr '>=40' --ifwd '>=1' --pkg SOD-123
part.py pick 'ferrite bead' --w 'Impedance@Frequency=~600' --irms '>=2'
```

## Constraint syntax

Every `--flag` and every `--w NAME=SPEC` takes the same spec grammar:

| spec | meaning |
| --- | --- |
| `22uF` | equal (numeric, so `22uF` never matches `2.2uF`) |
| `4.7u..100u` | inclusive range |
| `>=25` `<=50` `>1k` `<10` | comparison |
| `X7R,X5R` | any-of; numeric-aware, so `25` matches `25V` |
| `~ceramic` | case-insensitive substring |
| `!X5R` | negated |

Values parse as engineering notation: `4u7`, `100nF`, `4R7`, `10k`, `±20%`, `25V`
all work, and `10V~35V` takes the first figure.

## Attribute shorthands

`--cap --res --ind --volt --pkg --diel --tol --current --power --freq --temp --type
--dcr --esr --vr --vf --ifwd --ir --vds --rdson --isat --irms`

These fuzzy-resolve onto whatever LCSC actually calls the parameter, deterministically
(exact alias, then prefix, then containment; ties break shortest-then-alphabetical, so
resolution never depends on parameter ordering). `pick` prints a `resolved:` line
whenever a shorthand mapped to a differently-named attribute:

```
resolved: ifwd -> Current - Rectified;  vr -> Voltage - DC Reverse (Vr) (Max)
```

**Check that line.** If a shorthand resolved to the wrong attribute, use `--w` with
the verbatim LCSC name instead: `--w 'Voltage - DC Reverse (Vr)=>=40'`.

## --fields is the cheap discovery pass

When you do not know what a category's attributes are called, run the same query with
`--fields`. It lists the attribute names and their commonest values across the
candidate pool and skips filtering entirely. One call, small output. Do this before
guessing at flag names for an unfamiliar part type.

```
part.py pick 'schottky diode' --pkg SOD-123 --fields
  Current - Rectified        1A, 3A, 5A, 2A, 10A
  Voltage - DC Reverse (Vr)  100V, 50V, 40V
  Voltage - Forward(Vf@If)   450mV@1A, 850mV@3A
```

## Why pick fans out into several queries

LCSC ranks by keyword relevance only. A single query for a *range* would never surface
the mid-range values, and a single query with a `>=25V` filter fills the candidate pool
with cheap 6.3/10/16 V parts that then all fail the filter, returning nothing. So `pick`
expands a range over E6 preferred values (`--e12` to widen) and over the standard
voltage series, and issues one query per combination, capped by `--maxq` (default 14).
The `pick:` header line shows the queries it actually ran.

If a result set comes back empty, `pick` prints which constraint rejected how many
candidates, e.g. `every candidate failed on: volt(131), diel(20)`. That tells you which
one to loosen.

## Flags

`--sort price|stock|cap|volt` (default price), `--qty N` (default 100, MOQ/multiple
applied), `-n N` rows (default 8), `--basic`, `--source lcsc|jlc|both` (default lcsc),
`--anystock`, `--fields`, `--e12`, `--pool N` LCSC parts to detail (default 240),
`--maxq N` sub-queries, `--jobs N` threads, `--nojlc`, `--json`, `--fresh`.

`--pool` exists because LCSC cannot filter server-side: candidates must be fetched by
`product/detail` one at a time to learn their parameters. That is cached and parallel,
so it is fast, but it is bounded. See [endpoints.md](endpoints.md).

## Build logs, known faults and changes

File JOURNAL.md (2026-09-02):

## Starting the journal - 4 hours (2026-08-07)

I thought I should probably get into some more Hack Club stuff, and add more documentation for what I'm doing so I don't forget. I'm in the process of revamping the circuit protection. For the amount of money these modules and ICs cost (~$50 CAD), I think it's wise to throw at least $5 in circuit protection components at it. Of course the best circuit protection is just being careful and taking the proper precautions, but I'm a little silly.

I've already protected the RF frontends of the LoRa and GNSS modules, with ESD diodes and current limiting, so I'm moving on to the power inputs. I'm looking at implementing the `TI TPS25947` family of eFuses, specifically the [TPS259470LRPWR](https://www.ti.com/product/TPS25947/part-details/TPS259470LRPWR), which Claude suggested. This eFuse has both an overvoltage protection feature and an overcurrent protection feature. In my GNSS module's datasheet, the NEO-M9N has a maximum power supply voltage of 3.6 V. I can then set the eFuse's OVLO (overvoltage lockout) to cut off power when the input voltage exceeds 3.55 V, just below the NEO's maximum. However, there is one issue with this. In order for the eFuse to recover and continue operation after a fault state, the 3V3 input power rail must fall below 3.25 V, which would never happen in regular use. But that would just mean I have to power off the device and turn it on again, which isn't that bad considering it protected my expensive module from frying.

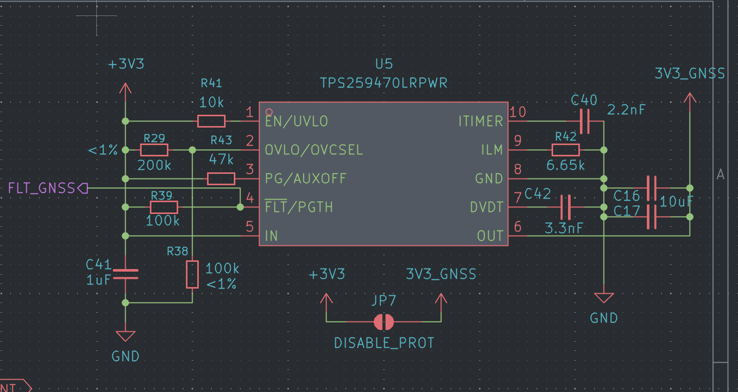
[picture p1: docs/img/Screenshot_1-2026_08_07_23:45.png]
KiCad Schematic TPS259470


Considering maybe adding a cheap 50-cent TVS diode to the TPS259470LRPWR input, as the datasheet says it may be helpful. I'll have to see.

## Finalizing circuit protection - 2 hours (2026-08-08)

* Switched from the `TPS259470LRPWR` to the `TPS259474LRPWR` for slightly better OVLO tolerances (5.5% to 1.7%), allowing the trip voltage to be more precise.
* Added a rechargeable battery to V_BCKP on U2.
* Decided on using the `TPS259474ARPWR` for the future buck converter output.

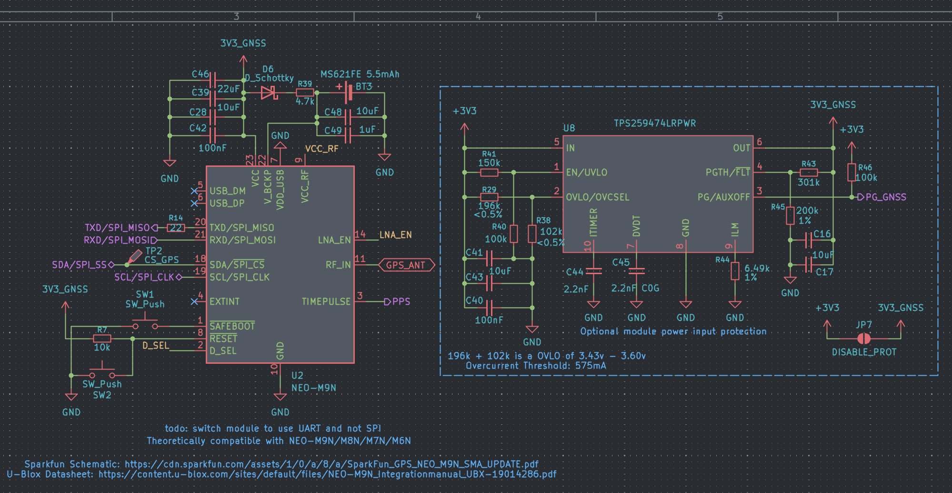
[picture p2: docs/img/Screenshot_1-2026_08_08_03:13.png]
KiCad Schematic GNSS


## Research BMS and charge controller choices - 2 hours (2026-08-09)

I think I've settled on using the `MAX17320Gxx`. I was thinking of initially going with the `BQ40Z50`, but with that one you are forced to use some of TI's software and buy their testing equipment in order to program it. The MAX17320 is only a little more and has a whole host of nice-to-have features like cycle count and intelligent algorithms to calculate percentage. It is however quite expensive at $8 CAD per IC, but I think it's worth the safety and ease of use aspects. I watched [this YouTuber](https://www.youtube.com/watch?v=UUr-CJudg38) on how he designed his BMS, it was quite insightful.

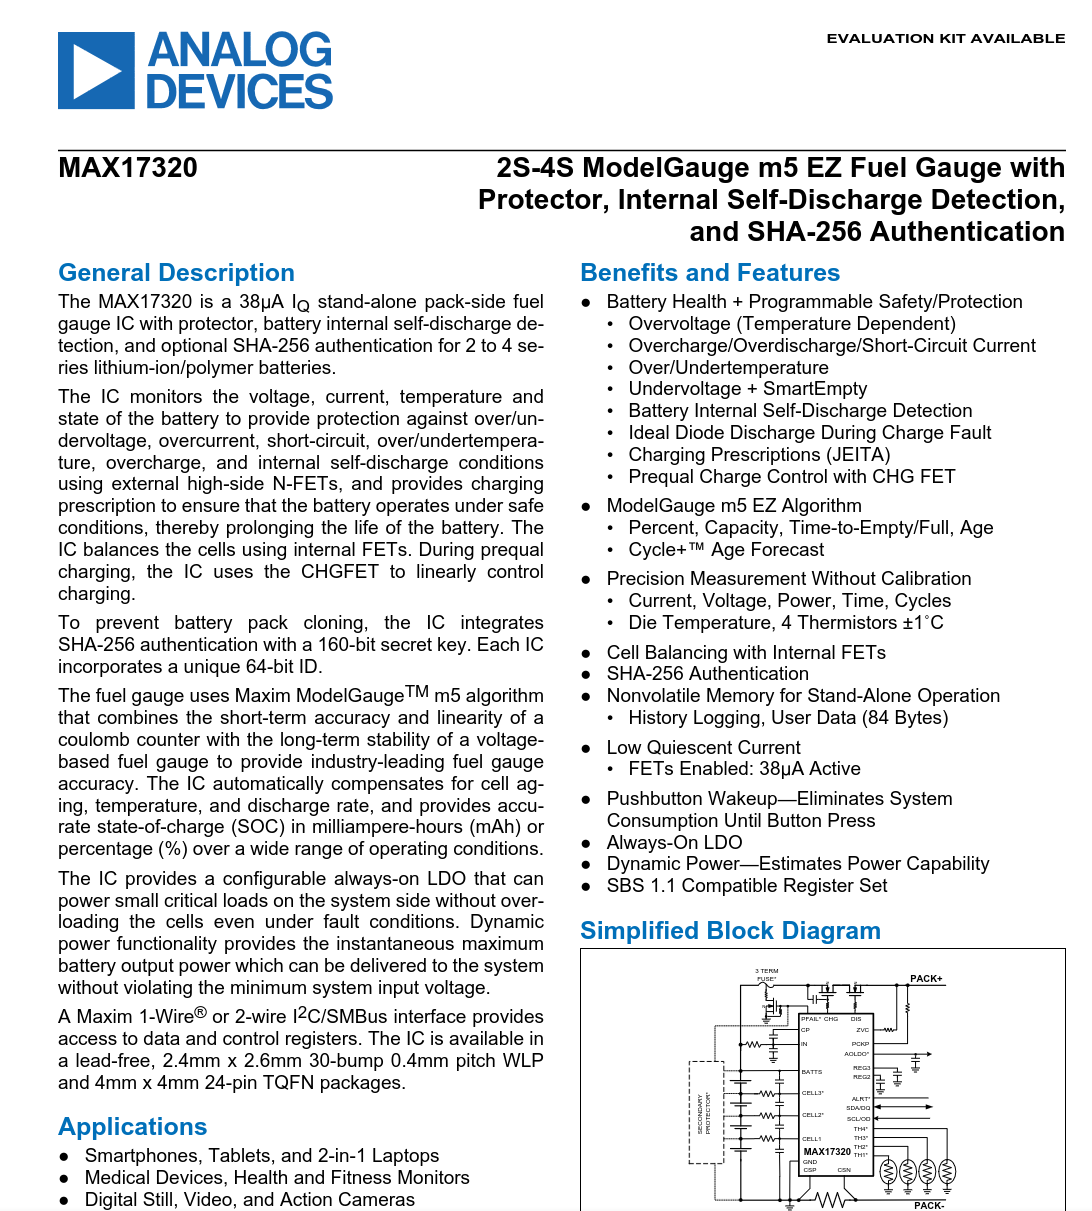
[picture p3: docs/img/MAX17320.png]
MAX17320 schematic image


### Charge Controller Selection

As for the charge controller, I went with the [BQ25798](https://www.ti.com/product/BQ25798). It's relatively cheap at $3 CAD each, it's modern and a recent design, and highly efficient. It supports a wide range of input voltages (USB-C PD fast-charging!) and can even communicate with the microcontroller to set custom charge limits to preserve battery health. However, it's a little noisy with its four switching MOSFETs, so it's going to take some consideration in layout so as not to interrupt any data lines and RF components/traces.

My goal was to get a slightly more premium BMS that had some of the nice features you'd see in mobile phones.

## Wiring up the BMS - 3 hours (2026-08-10)

| my design | reference design |
| :---: | :---: |
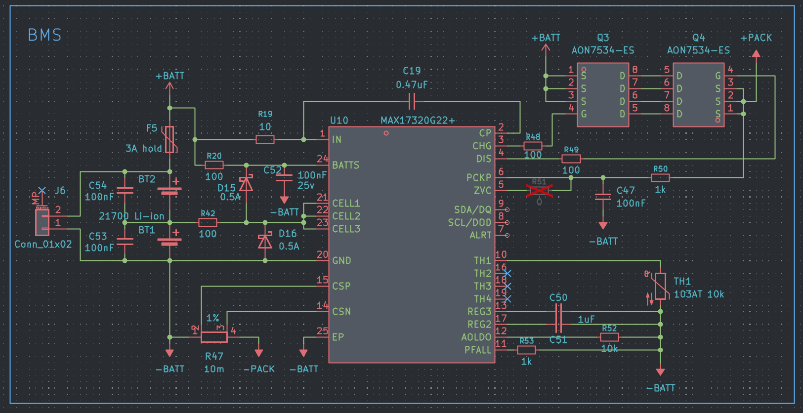
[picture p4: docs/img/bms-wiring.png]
Custom Schematic
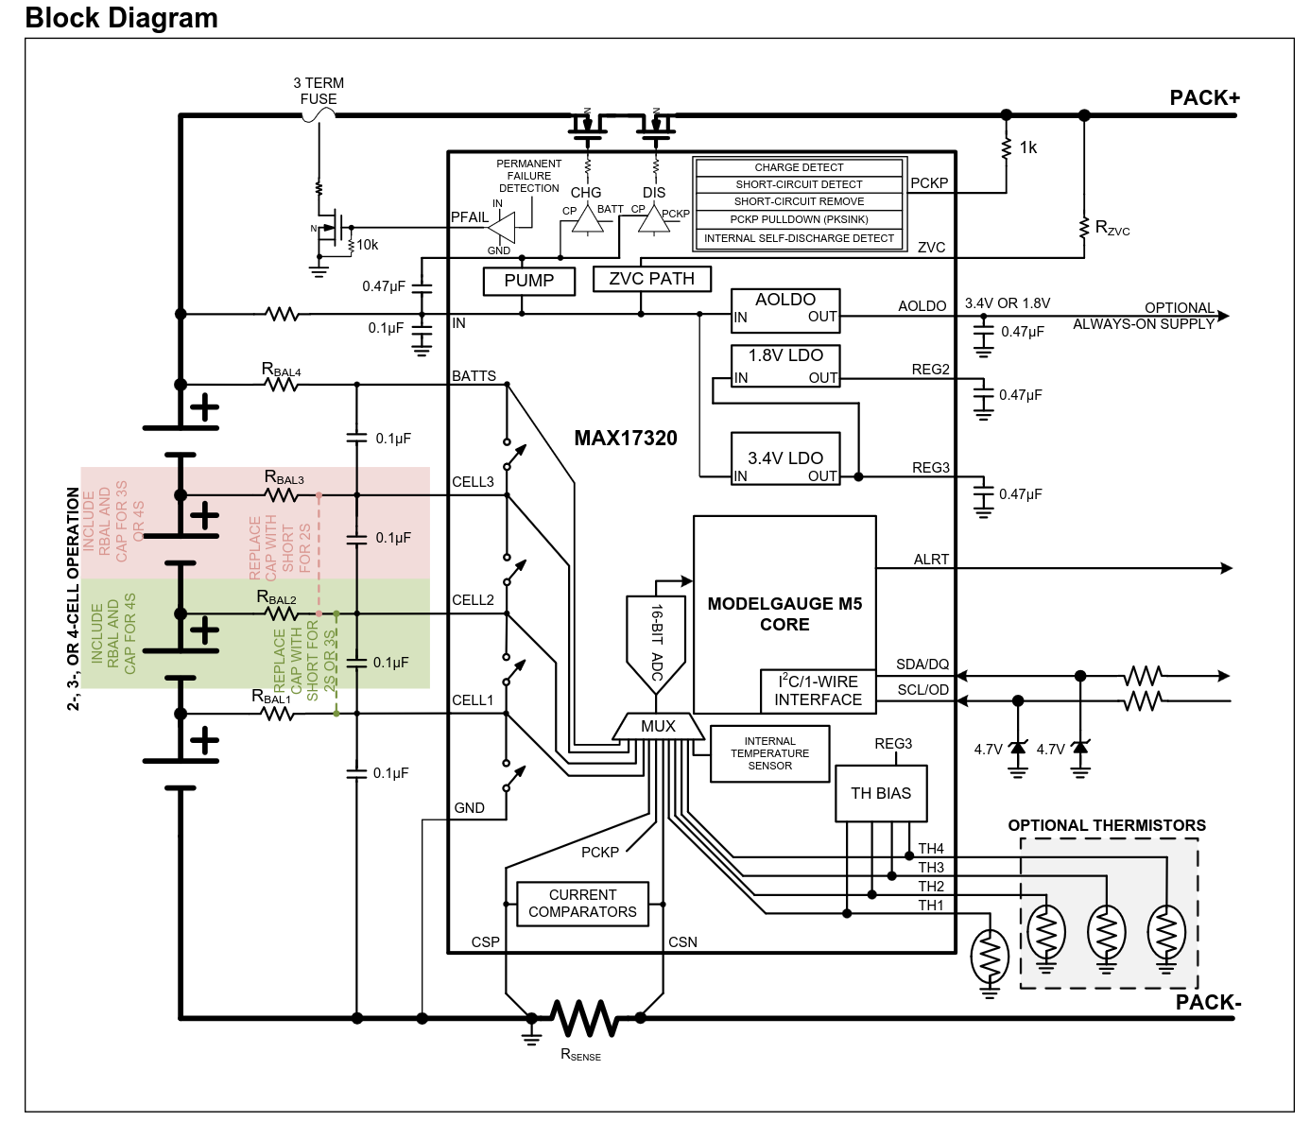
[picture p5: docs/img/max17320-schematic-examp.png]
Reference Schematic
|  |  |

I'm sure there are still some issues or things to double check, but it's a good start. I studied the example block diagram schematic from the datasheet, and a few other schematics I could find when googling "MAX17320G22+ kicad schematic". Claude said the `AON7534` N-channel MOSFET would be best, so I trusted it. I'm trying to think about how I'll have the thermistor placed, because I'm using two 21700 battery holders next to each other. Perhaps I could expose some copper and use one of those SMD NTC thermistors? The batteries would then be sitting very close to the thermistor, and perhaps I could add some type of thermally conductive but not electrically conductive material or foam. I don't like the idea of taping the thermistor to the batteries...

## Confirming BMS wiring, adding testpoints and voltage/power ratings to components - 3 hours (2026-08-13)

Spent some time today double-checking the wiring on the BMS and learning more about it from the datasheet. I'm much more confident in my wiring now, and I added some DNP components in case I need to swap anything or make changes to it afterwards, plus testpoints as well. Most of the capacitors I was planning on using are well below the voltage rating they should be for the BMS, so I made sure to explicitly mention capacitor voltage ratings in the part field in KiCad.

Next steps would be to make the `MAX17320G22+` symbol a little prettier and organize my wiring, and to wire the charge controller. It's a little hard to read in its current state. So many components on such a small symbol. Maybe I'll ask in the KiCad Discord for suggestions on how to make the BMS schematic a little clearer.

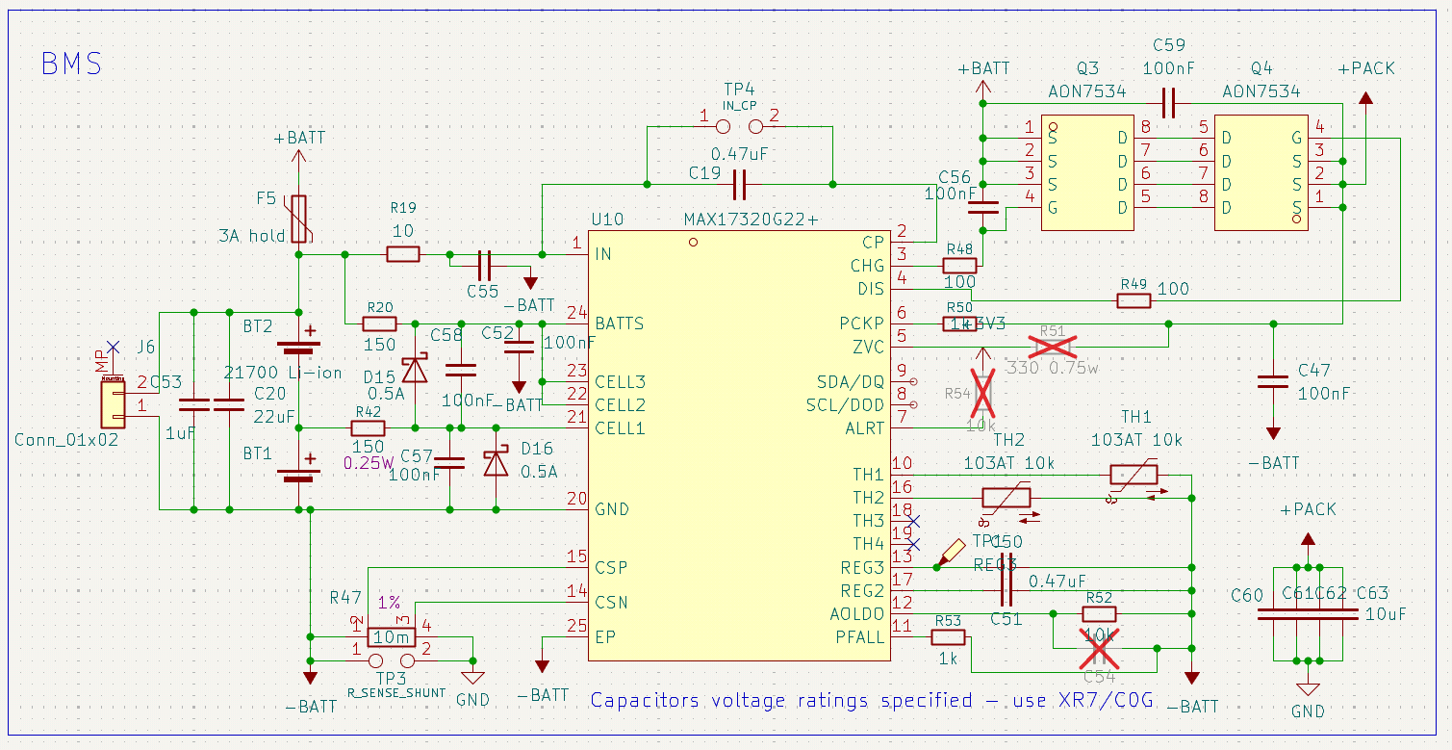
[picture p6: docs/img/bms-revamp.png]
BMS MAX17320 changes


## Wiring up the charge controller & selecting buck converter and PD IC - 4 hours (2026-08-14)

Following the reference application schematic for the [BQ25798](https://www.ti.com/product/BQ25798) and calculated the inductor current for my application. Reading over the data, it's actually a pretty impressive piece of silicon for how many features it has in such a small package. It uses narrow voltage DC (NVDC), so it'll take power directly from your USB-C circuitry, regulate it within a certain range similar to your battery, and then you can power your buck converter and downstream devices from its `SYS` output at up to 6 A. No external power muxing needed, and it's really efficient. Battery charge current can be set fixed, or dynamically through its I2C bus. The downside is the high frequency switching (750 kHz - 1.5 MHz), but I think if I physically keep it distanced far enough away from the RF components, and choose a good inductor, I should be okay.

One thing I tried to keep in mind for the charge controller and BMS circuitry: even though I'm only planning on having two series batteries, I should try to make most of the components compatible with the maximum 4S that both ICs support. This means having all the components rated for `>25V`, so choosing capacitors that are rated for 50 V. In turn this would mean having to add more capacitors than I normally would, in order to satisfy capacitor DC bias derating at higher voltages.

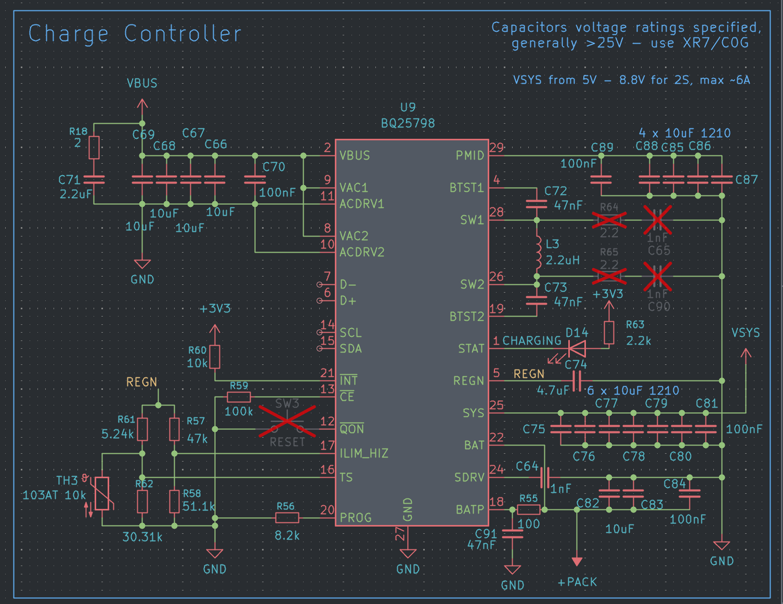
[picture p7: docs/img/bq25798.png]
wired BQ25798 schematic

*I do need to clean this up and make it look less muddled...*

For the USB-PD, I wanted to choose something cheap, easy and small. I have no need for extra features or for it to support a wide range of USB chargers. I went with the [HUSB238](https://en.hynetek.com/2421.html), specifically the `HUSB238_002DD`. It's about $0.70 CAD each on LCSC, and supports a fixed 9 V USB trigger. The more common option would be to use the `CH224K`, but it had a large package and looked "old", although it's cheaper.

Lastly, I need a 5 V rail to run off the outputted `SYS` from the charge controller, so approximately a `5V - 8.8V` input. Claude helped me choose the `LM61460-Q1`, specifically the [LM61460AASQRJRRQ1](https://www.ti.com/product/LM61460-Q1/part-details/LM61460AASQRJRRQ1). It's a little steep at $2 CAD on [LCSC](https://www.lcsc.com/product-detail/C1855832.html), but using TI components is nice, and this IC is ideal for powering sensitive high-frequency components (it has "Low EMI" in the title). One of the ways it achieves this low EMI is by letting you customize its switching frequency, thereby sacrificing efficiency for switching at a frequency that doesn't interfere with frequencies elsewhere on the board.

> The switching frequency can be set or synchronized between 200 kHz and 2.2 MHz to avoid noise sensitive frequency bands.

## Reworking power rails, adding antenna detection, and organization - 6 hours (2026-08-18)

* Added the [LM61460-Q1](https://www.ti.com/product/LM61460-Q1/part-details/LM61460AASQRJRRQ1) as my 3V3 switching buck converter, which is the same as for the 5V rail.
 
* Added an eFuse to the output of my 5V buck for additonal protection

* Added LoRa antenna detection to prevent high power transmits from damaging the E22P RF frontend.

* Renamed schematic sheets for clarity and to be updated for the name change from `limeskey-node` to `parsnip-node`
  
* Double checked capacitor voltage ratings are correct for the net

For the antenna detection, I didn't think it was possible to implement without something like an expensive VNA. But apparently, since most LoRa antennas are DC-shorted, you can put a small amount of current on the antenna trace and check and see if it's still there with a FET. If the antenna is installed correctly, there should be no DC voltage on the antenna net, but if it wasn't, it would show 3V3 and the LoRA module would automatically stop transmitting.

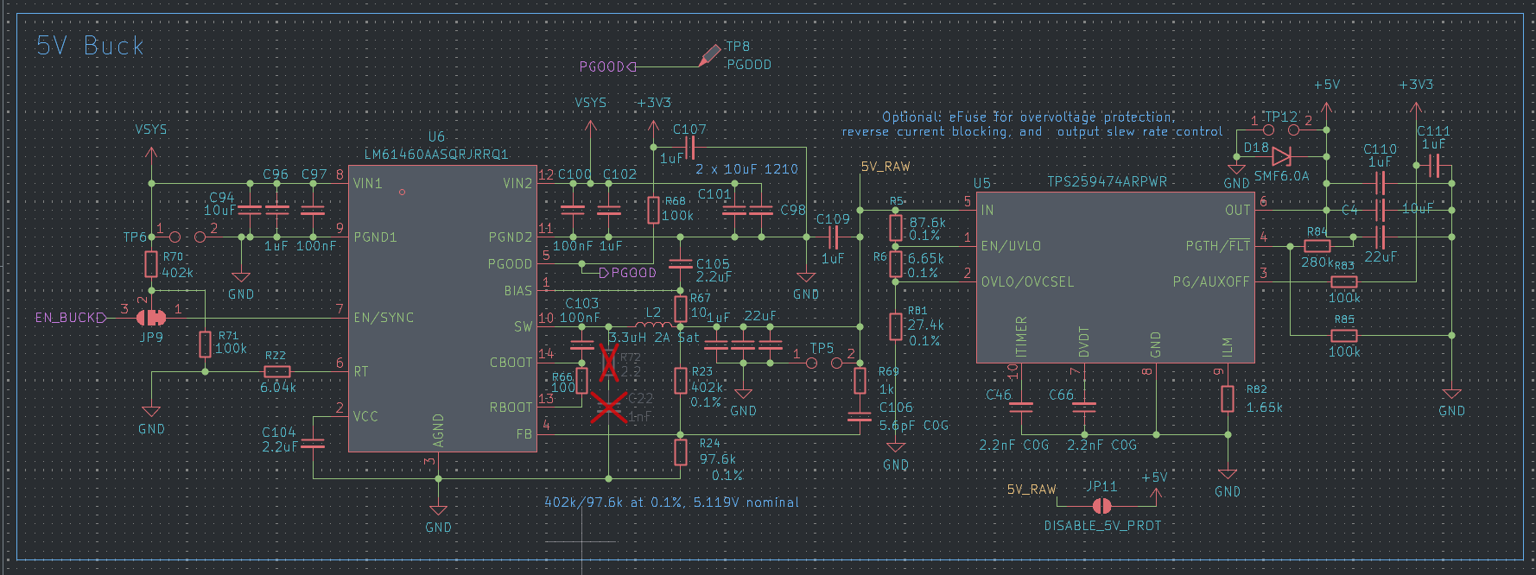
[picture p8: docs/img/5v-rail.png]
5v rail


## USB Interface - USB-OTG at 60W! - 6 hours (2026-08-21)

### USB-OTG
I learnt what USB-OTG was and it turns out my charge controller already supports it, and for two dollars more, I could upgrade my current USB-PD IC to something that also supports USB-OTG. USB-OTG allows USB device to charge another device, acting like a power supply, with the same voltages and currents a regular wall-adapter USB-C brick would do. 

The `BQ25798` can do USB-OTG at 3.32A maximum, and at up to 22V; I'll likely set it to do 20V at 3A. My 2S 21700 batteries can do approximately 10A contiously at 8V, so something around 80W total, but it's best not to push them that far. And 60W, what the maximum is for the BQ25798, is plenty. 

### USB Power Delivery
As for USB-PD, I went from the $0.50 USD `HUSB238` to the $2.50 USD `TPS25751`, specifically for the USB-OTG feature. It also turns out this new PD IC has some nice circuit protection features, like reverse current protection, undervoltage and overvoltage protection, protection against some non-compliant USB devices for the CC pins, but most importantly for me, it has liquid detection. It can detect when water gets into the USB-C port and either slow down charging, or shut off completely. You do need four FETs in order to use this feature, but they aren't very expensive or large.

Additionally I added some optional protection components to the USB-C port, a surge protection device [TVS2200DRVR](https://www.ti.com/product/TVS2200/part-details/TVS2200DRVR), a TVS device [TPD4E05U06](https://www.ti.com/product/TPD4E05U06/part-details/TPD4E05U06DQAR), and an ESD protection device [TPD8S300A](https://www.ti.com/product/TPD8S300A). These were a little expensive (a few dollars), and a little large, but they're really nice to have. I want my board to withstand anthing basically lol.

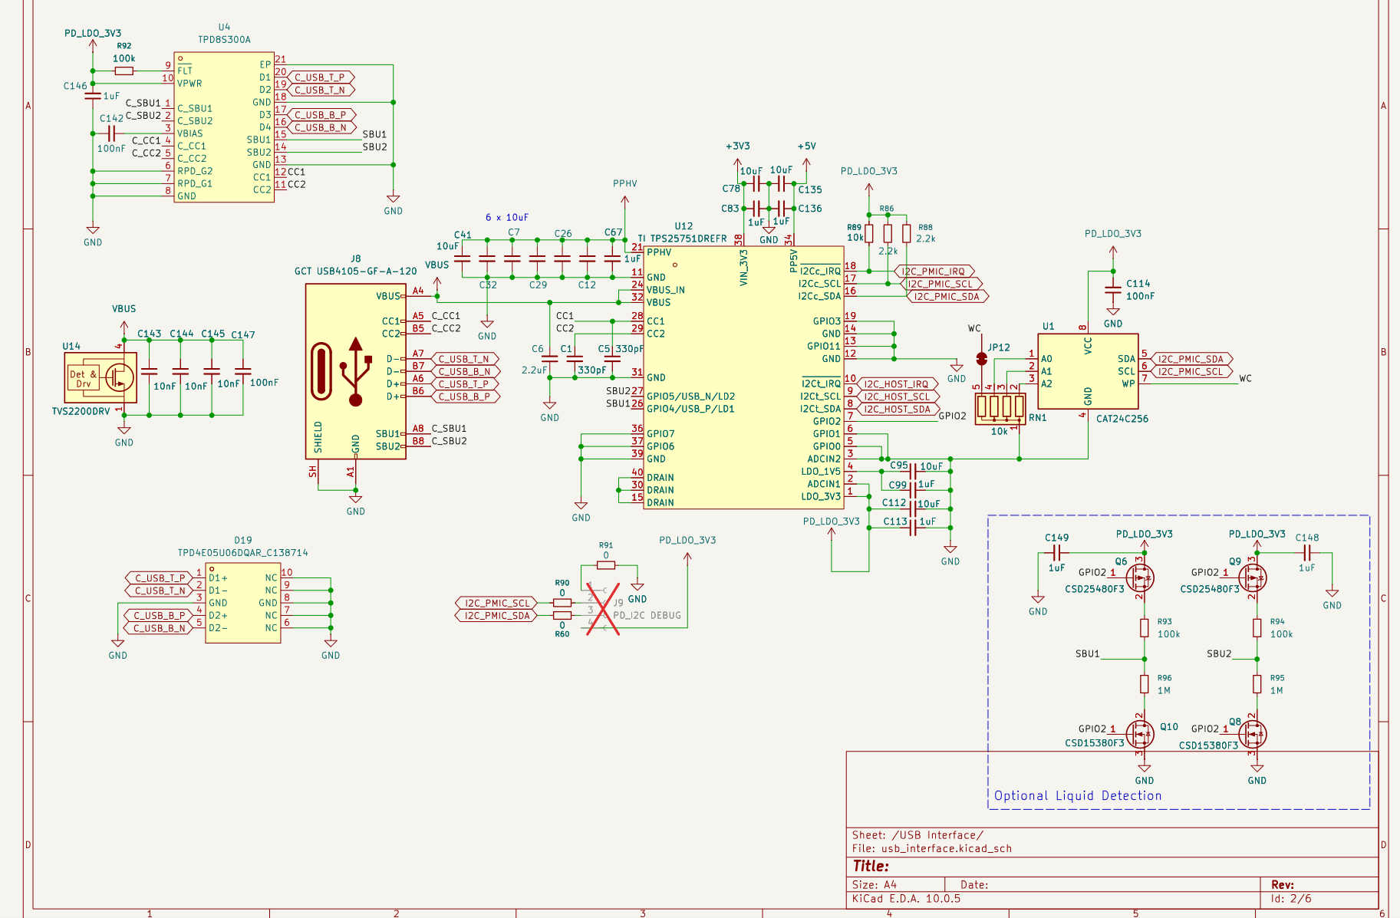
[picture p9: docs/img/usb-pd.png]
USB Interface


Next steps would probably be to double check I wired everything right, then move onto wiring the ESP32-S3 which hopefully won't be very difficult.

## E-Ink Display & Schematic Cleanup - 4 hours (2026-08-24)

### Cleanup
Today I worked on making the schematic a bit easier to read and understand, as I'm having a few people review it. Additionally, I assigned communication labels to a few unused pins on my ESP32 and tidied up the connector section in the root schematic. I am thinking it would be helpful if I were to expand the size of some symbols so it's easier to see all the components in between the IC pins. I have plenty of schematic room so why not make everything a little larger and more spread out? It's what I commonly see in more professional schematics, such as my laptop's motherboard schematic.

### E-Ink
I am toying with the idea of adding a 2.9" E-Ink/E-Paper display ([AliExpress](https://www.aliexpress.com/item/1005004644515880.html)) on the back of the PCB, against where the two 21700 batteries go. I'm thinking it could be attached to long M.2 standoffs ([AliExpress](https://www.aliexpress.com/item/1005008713639234.html)), and screwed into my board's mounting holes. It would be nice then to show information about where the user is currently located and how many LoRa nodes the device currently sees. It seems like non-tech people that I show my prototype/v1 device to, they are offput by the idea of having to use a phone. Perhaps they feel like it defeats the purpose of my device. To me, it doesn't impact the device much at all, since I'm only simply using the display and touchscreen of the phone and that's all. The phone doesn't have to have any sort of GNSS/Wifi/Cellular Internet for it to work, but non-techy people don't really understand that.

However, if I were to add a display, it would be intuitive for the user to also interact with the display. I would almost have to add a button of some sorts. I was considering adding a [capacitive sensor](https://hackaday.io/project/202684-io-touch-every-io-pin-is-a-capacitive-sensor) to my PCB, it looks pretty simple, however it requires a lot of space, space which I don't really have. Need to think more...

Oh, also, I changed from a `GPL-3.0` license to the `CC BY-NC-SA 4.0` license, it better aligns with my views.

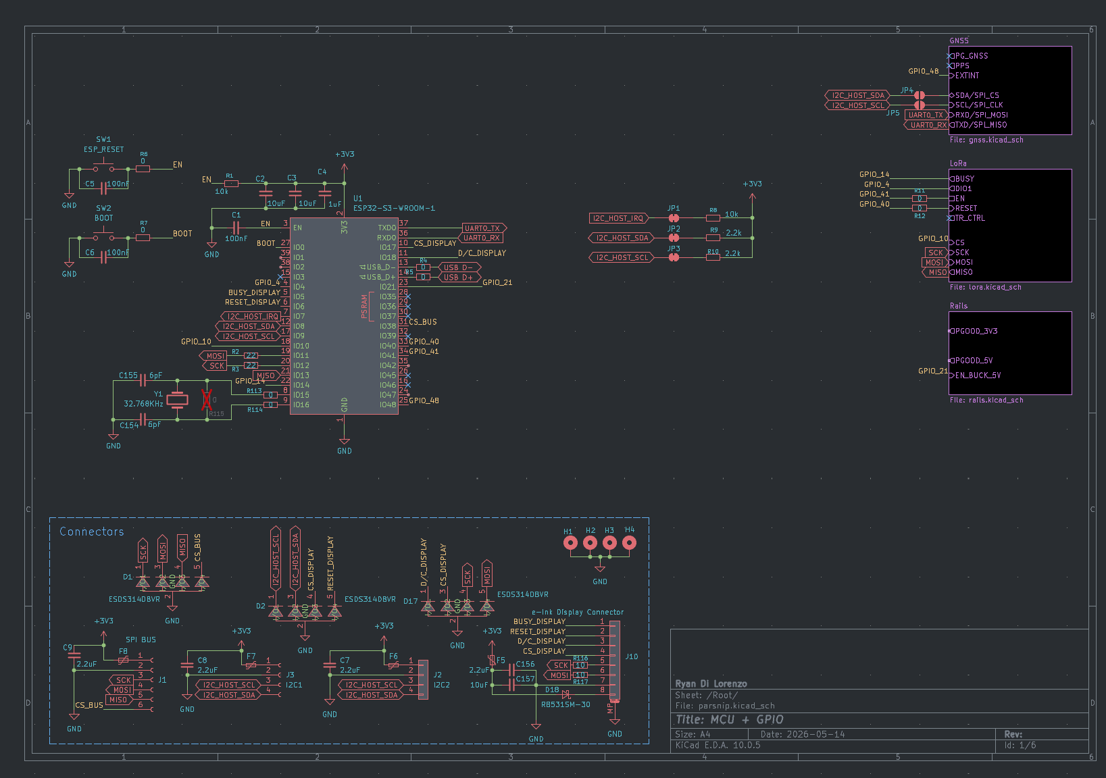
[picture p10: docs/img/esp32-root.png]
ESP32 Wiring, root schematic


## Reducing Buck Converter EMI - 6 hours (2026-08-26)

As it stands, I have two of the same low-EMI buck converter ICs for my 5V and 3.3V rail. Both of them switch at the same frequency, which should be fine, right? Wrong, both buck converters have drift and may not statup at the exact same time; and even if they were in sync/phase, you wouldn't want them to be anyways. Ideally, you'd want your buck converters to be switching at alternate times, one switches after another. Fortunately, there is a sync feature built right into the buck converters which can do exactly this. However you'd need an external clock.., well maybe two, one 0 degrees phase shifted, and another 180 degrees phase shifted.

Well, you could use a [4MHz oscillator](https://www.lcsc.com/product-detail/C2901612.html), and a [flip-flop](https://www.ti.com/product/SN74LVC1G74), sounds like a plan. Until you realize the oscillator draws 10 mA!!!! I don't have anything on the board except the main buck converter itself that could provide 3V3 @ 10mA. And of course, you can't power the oscillator from the output of the very buck converter it's trying to switch on, right? Actually apparently you can. The sync pin is very much optional, and when it's absent, the buck converter relies on it's own oscillator. So basically the only downside is poor EMI for 1 second at startup, which is nothing.

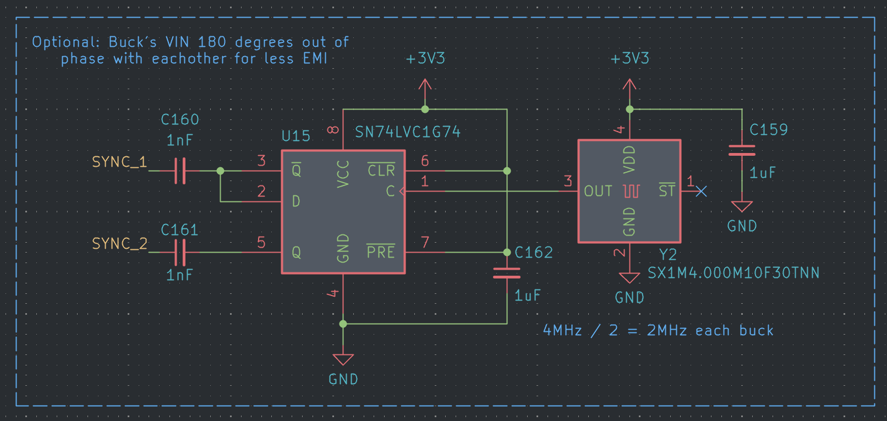
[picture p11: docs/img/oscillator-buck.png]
Buck oscillator circuit


Also in this journal:
* Adjustments to eFuse limits again
* Reduce 5V buck from 5.1v to 5.02v for added safety
* Add footprints & voltage ratngs to a lot of capacitors
* Fix flipped FET for liquid detection
* Add a magnometer

## Starting PCB Layout - 4 Hours (2026-08-29)

Worked today on the PCB, finally moving on from the schematic. Hopefully I can get it fully wired within the next few days. I am starting with grouping together ICs with their components as per the schematic, and thinking about where all the major components and items should go. Connectors on the bottom, battery on the backside top, the BMS & battery circuitry middle-left, and the buck converters middle-right.

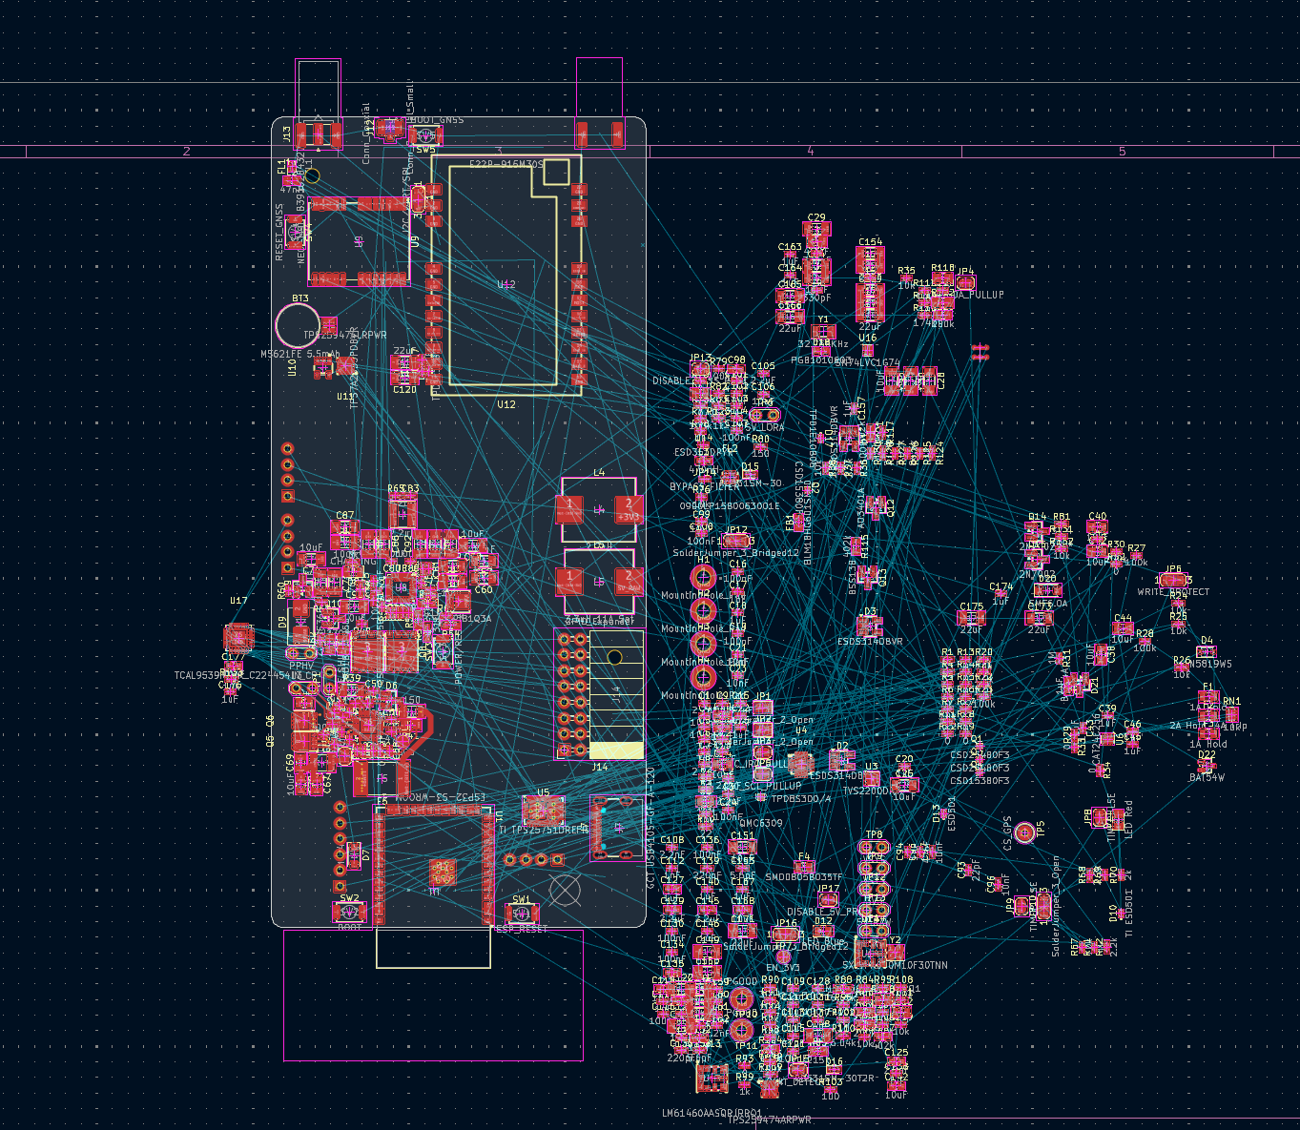
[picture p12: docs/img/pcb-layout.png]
PCB View


## Layout done - working on routing - 4 hours (2026-09-01)

Went to a local makerspace, Hacklab, to work on the PCB some more. Now that I'm on my laptop, I didn't have the 3D Models transfer over, since I was using easyeda2kicad and that put the models inside a local directory on my computer - not in the repo. I re-downloaded all the 3D Models and moved them into `lib/3d-models` and then changed the 3D model location for all missing components. Now when someone opens my PCB and checks the 3D View, all the components should show up nicely. A couple parts had incorrect footprints for the part, and I was able to fix this after seeing the 3D Model was obviously different from the footprint. That's one reason I like 3D Models so much.

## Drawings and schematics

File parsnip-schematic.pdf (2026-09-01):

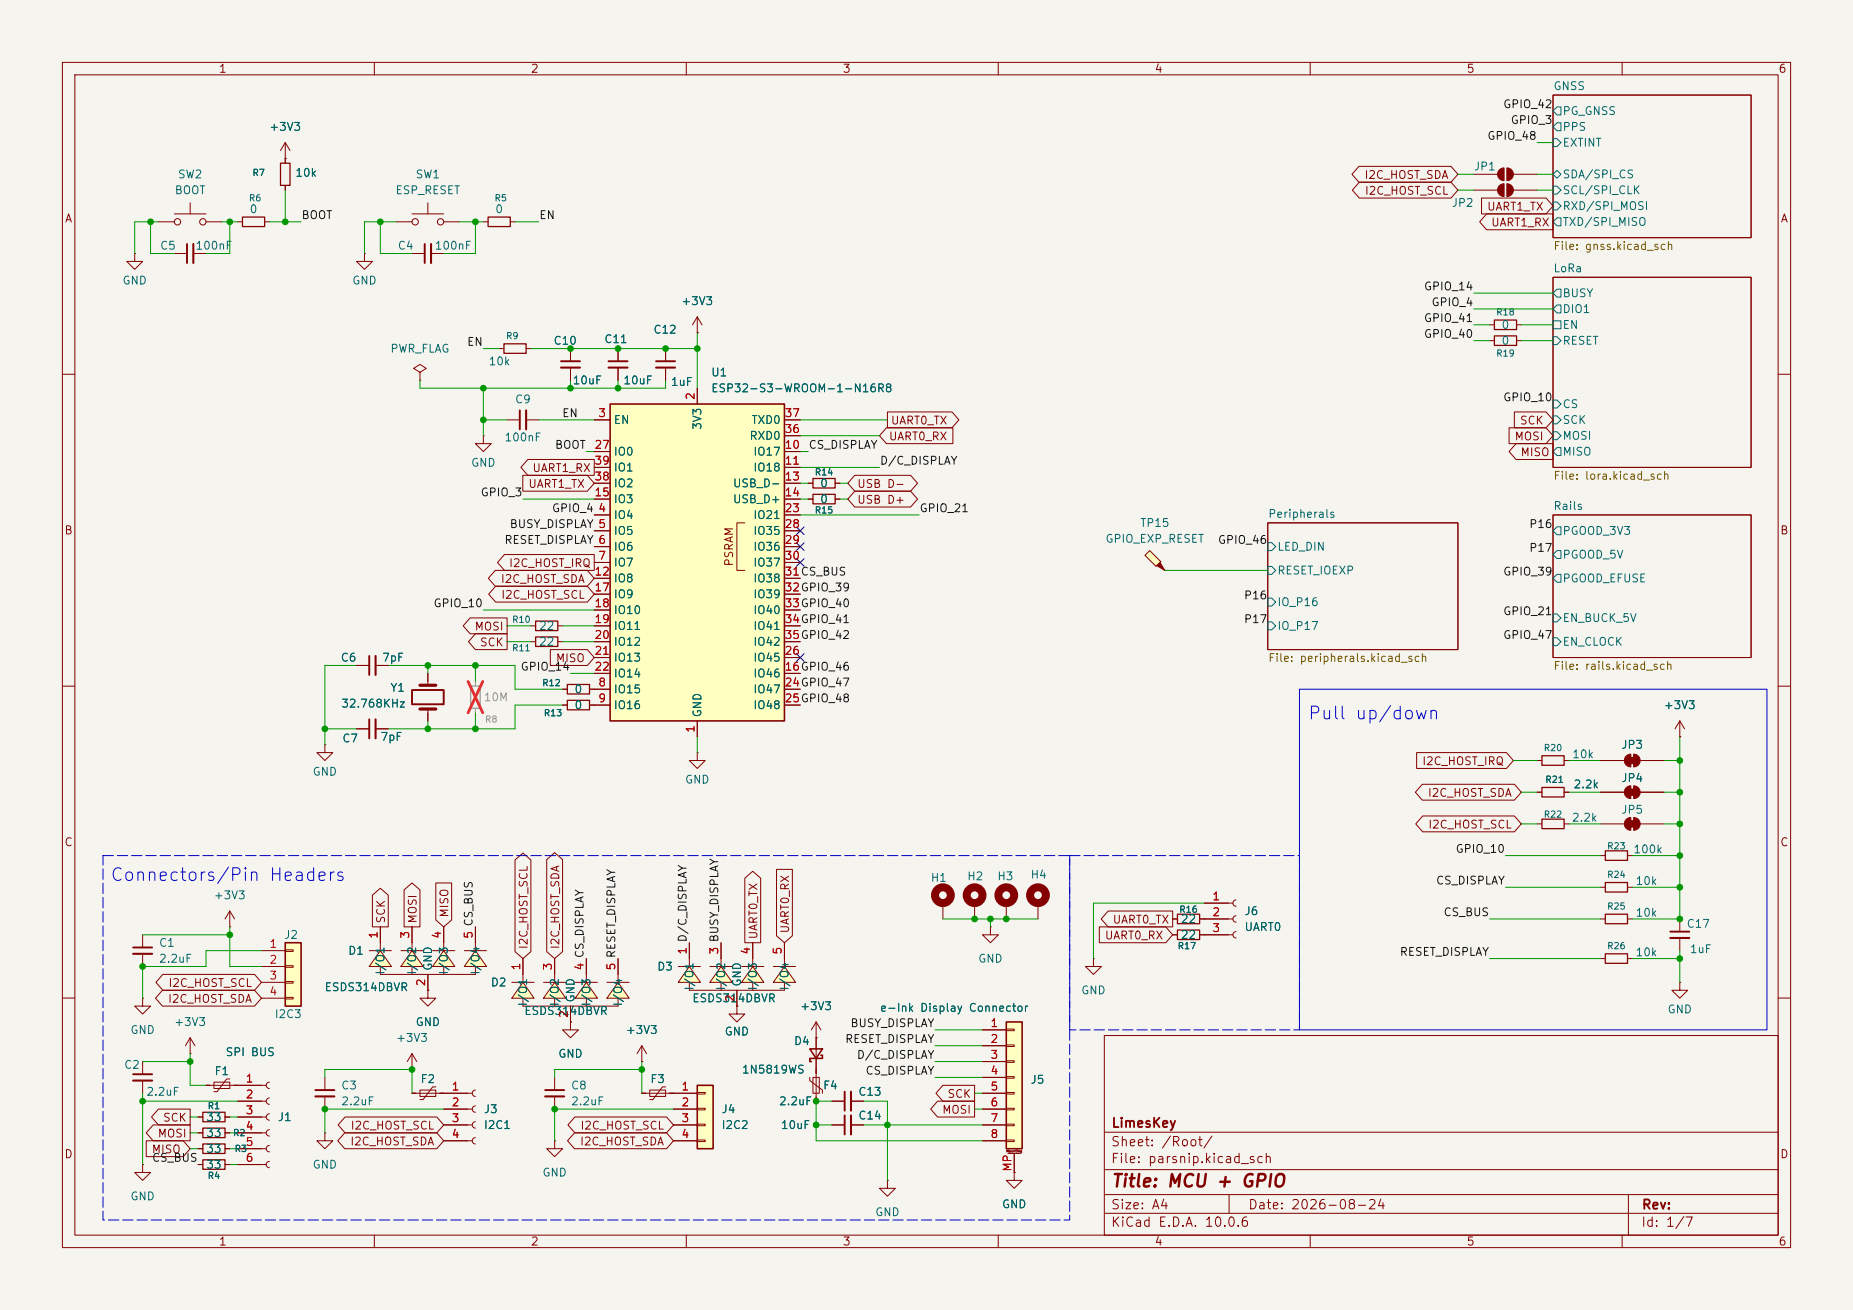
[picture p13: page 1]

LoRa
ENMISO MOSI RESET SCK

Size: A4 | Rev:
KiCad E.D.A. 10.0.6 | Id: 1/7

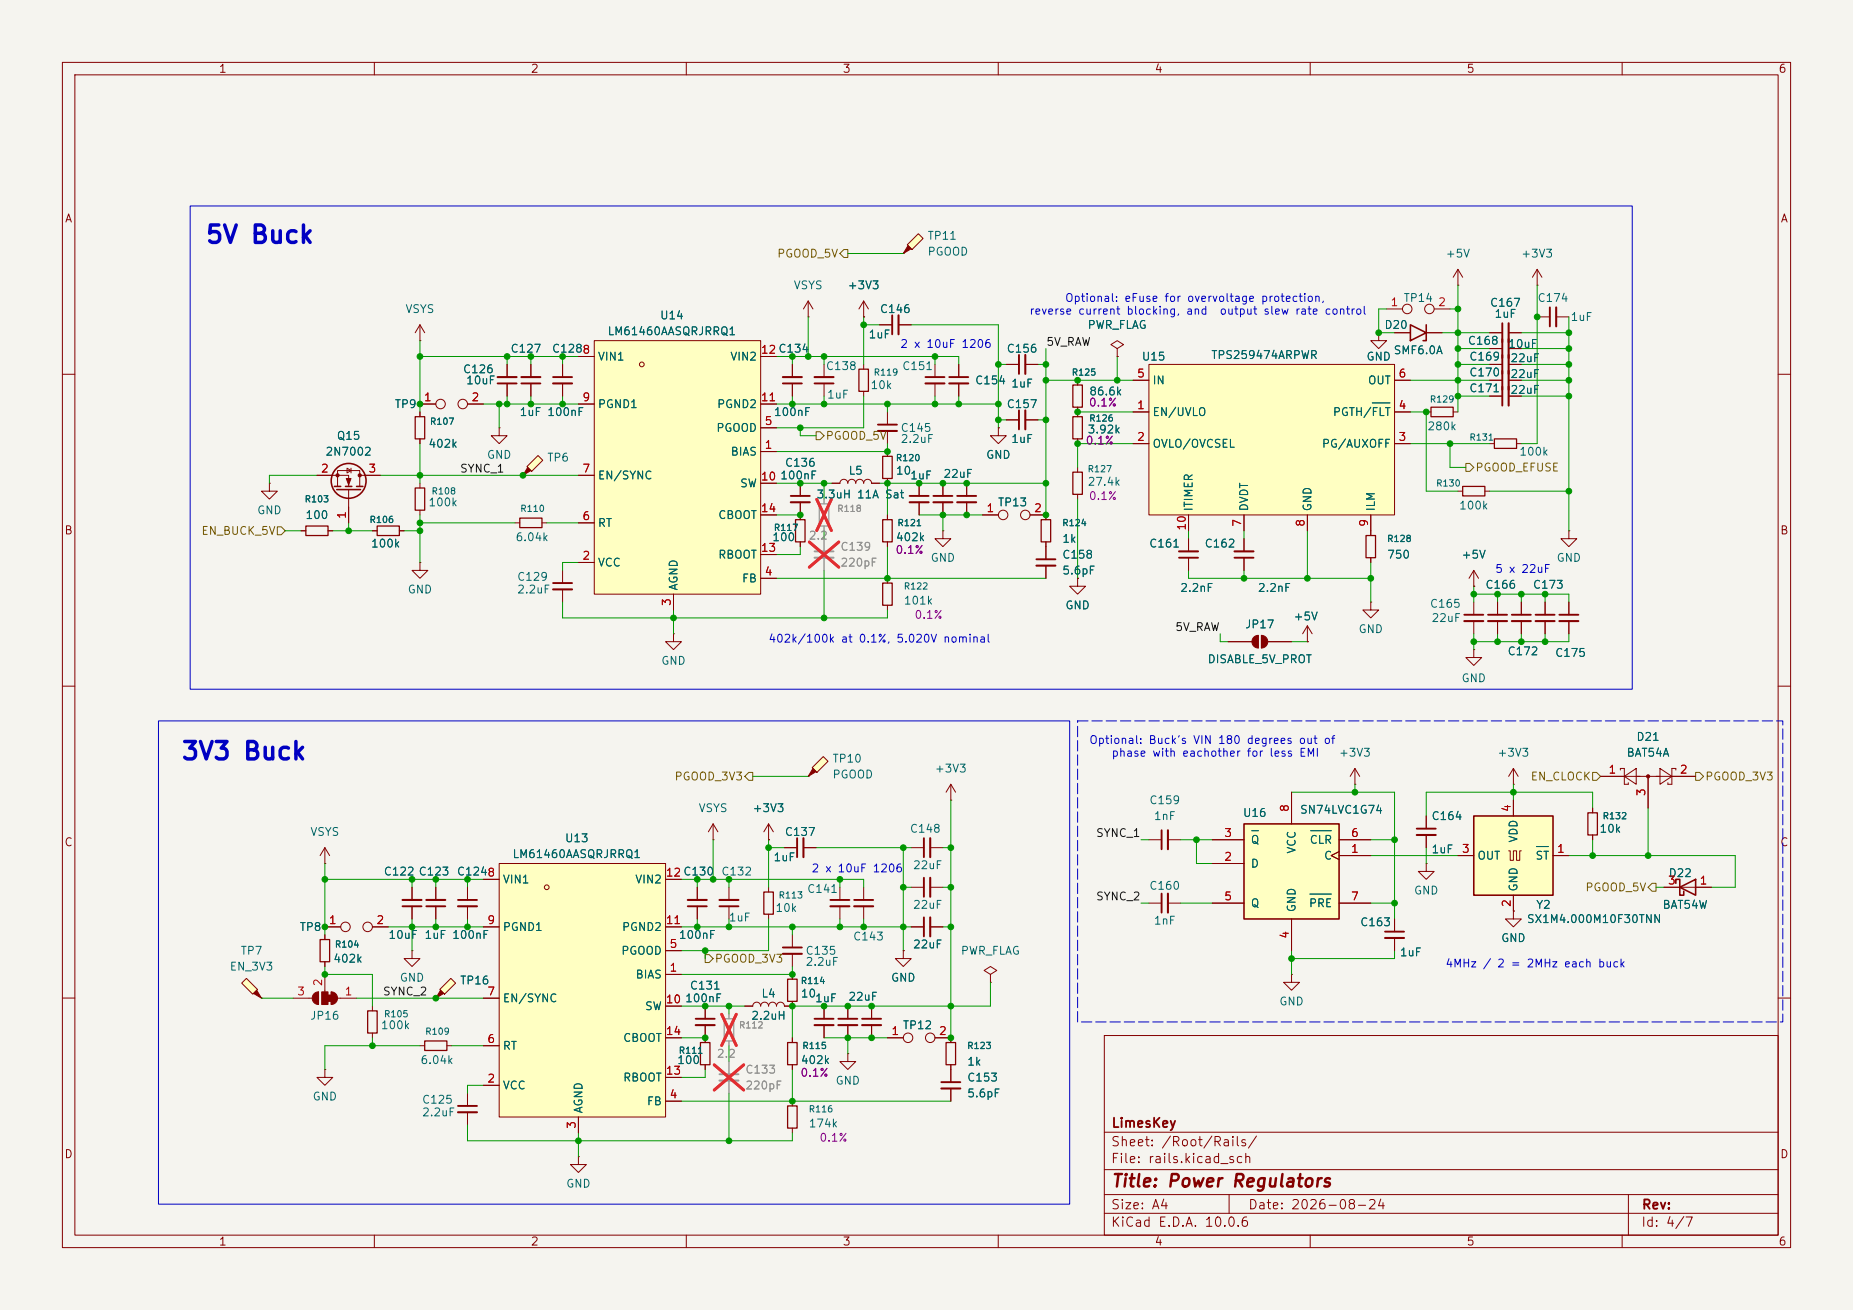
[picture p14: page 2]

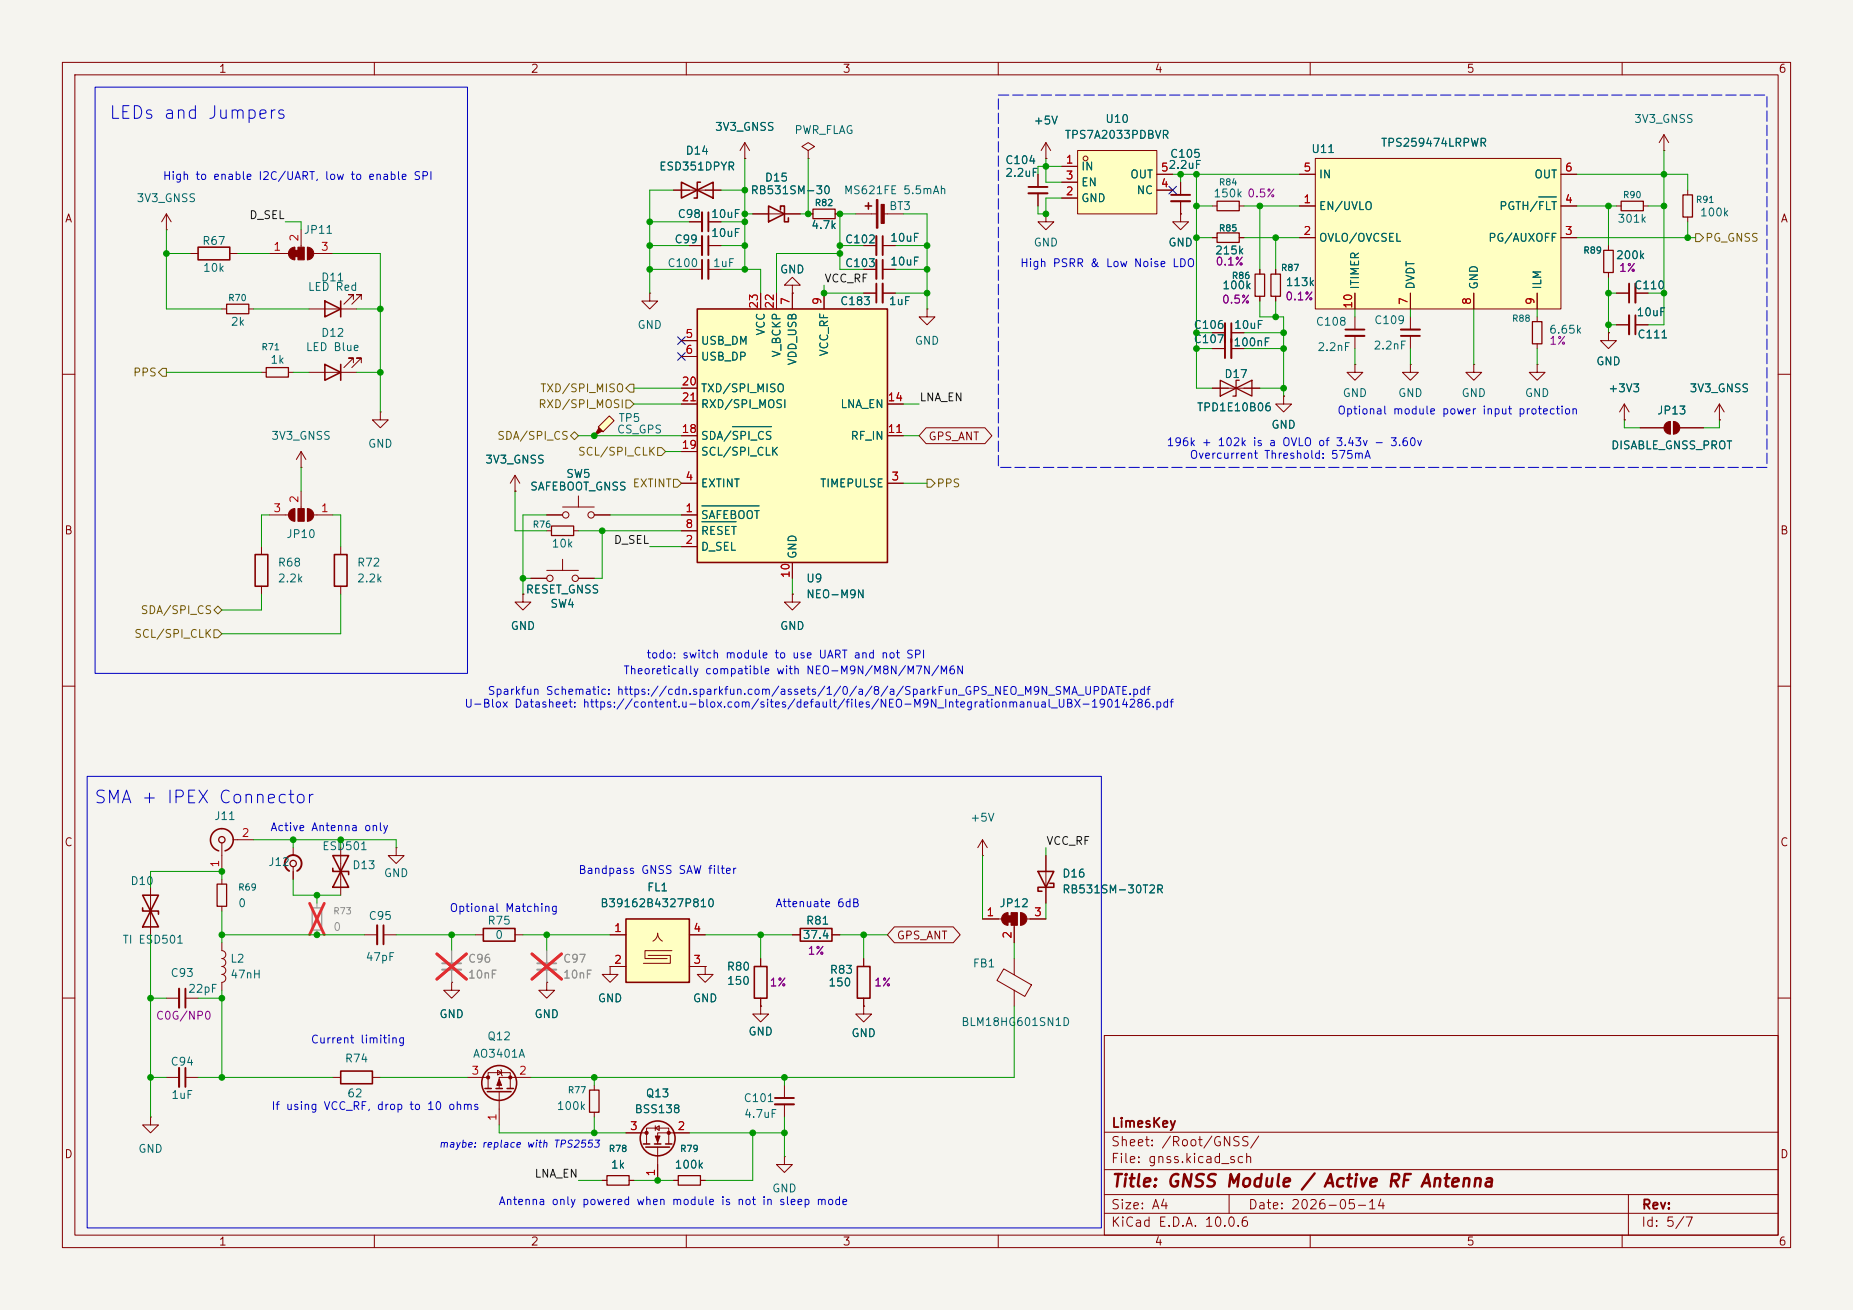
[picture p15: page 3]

196k + 102k is a OVLO of 3.43v - 3.60v High to enable I2C/UART, low to enable SPI LEDs and Jumpers

GND
High PSRR & Low Noise LDO

Optional module power input protection

Overcurrent Threshold: 575mA SMA + IPEX Connector

todo: switch module to use UART and not SPI Bandpass GNSS SAW filter

Sparkfun Schematic: https://cdn.sparkfun.com/assets/1/0/a/8/a/SparkFun_GPS_NEO_M9N_SMA_UPDATE.pdf U-Blox Datasheet: https://content.u-blox.com/sites/default/files/NEO-M9N_Integrationmanual_UBX-19014286.pdf

If using VCC_RF, drop to 10 ohms Current limiting

LimesKey
Sheet: /Root/GNSS/
File: gnss.kicad_sch
Title: GNSS Module / Active RF Antenna

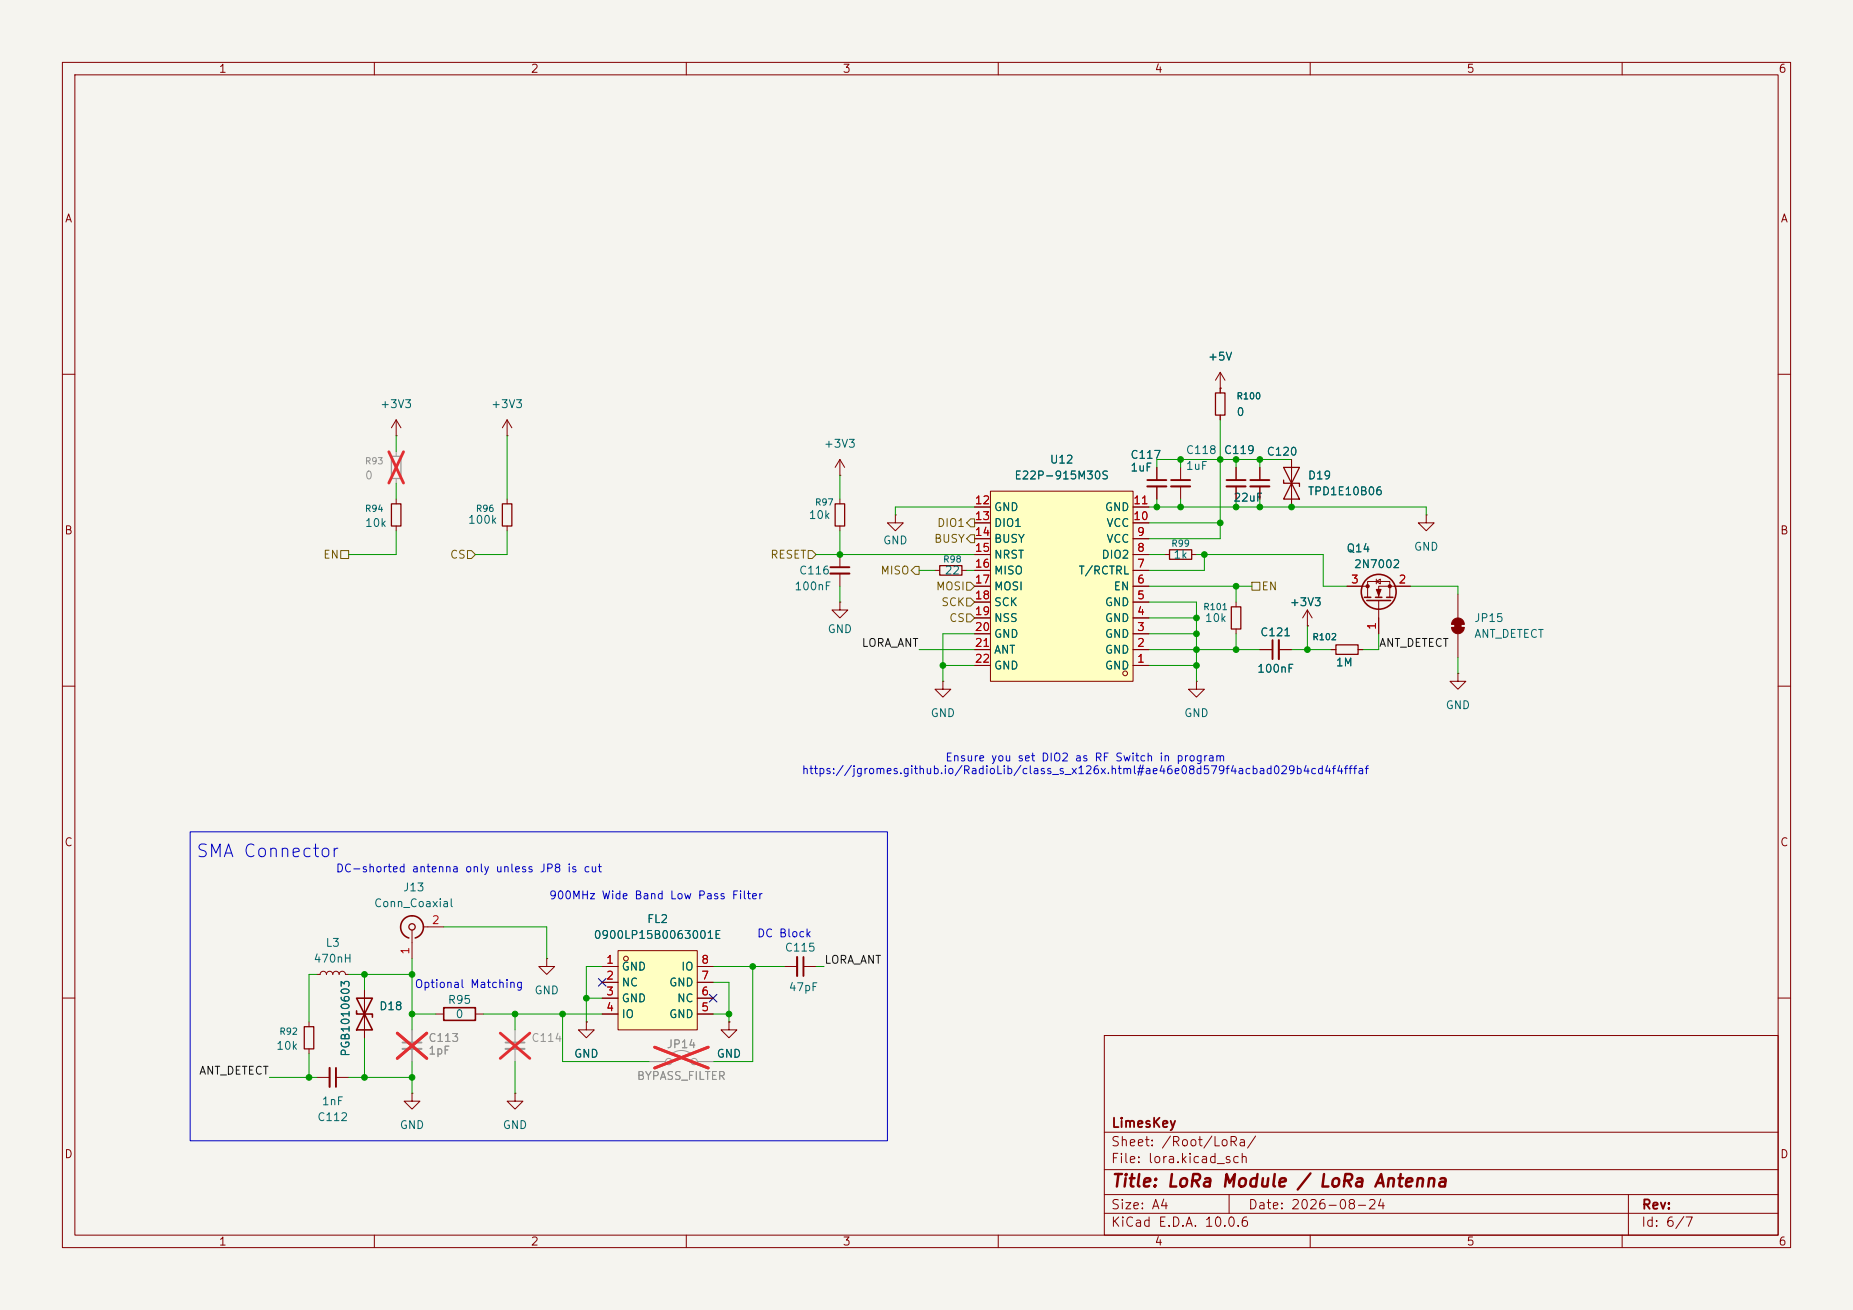
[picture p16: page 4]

https://jgromes.github.io/RadioLib/class_s_x126x.html#ae46e08d579f4acbad029b4cd4f4fffaf

Sheet: /Root/LoRa/
File: lora.kicad_sch
Title: LoRa Module / LoRa Antenna

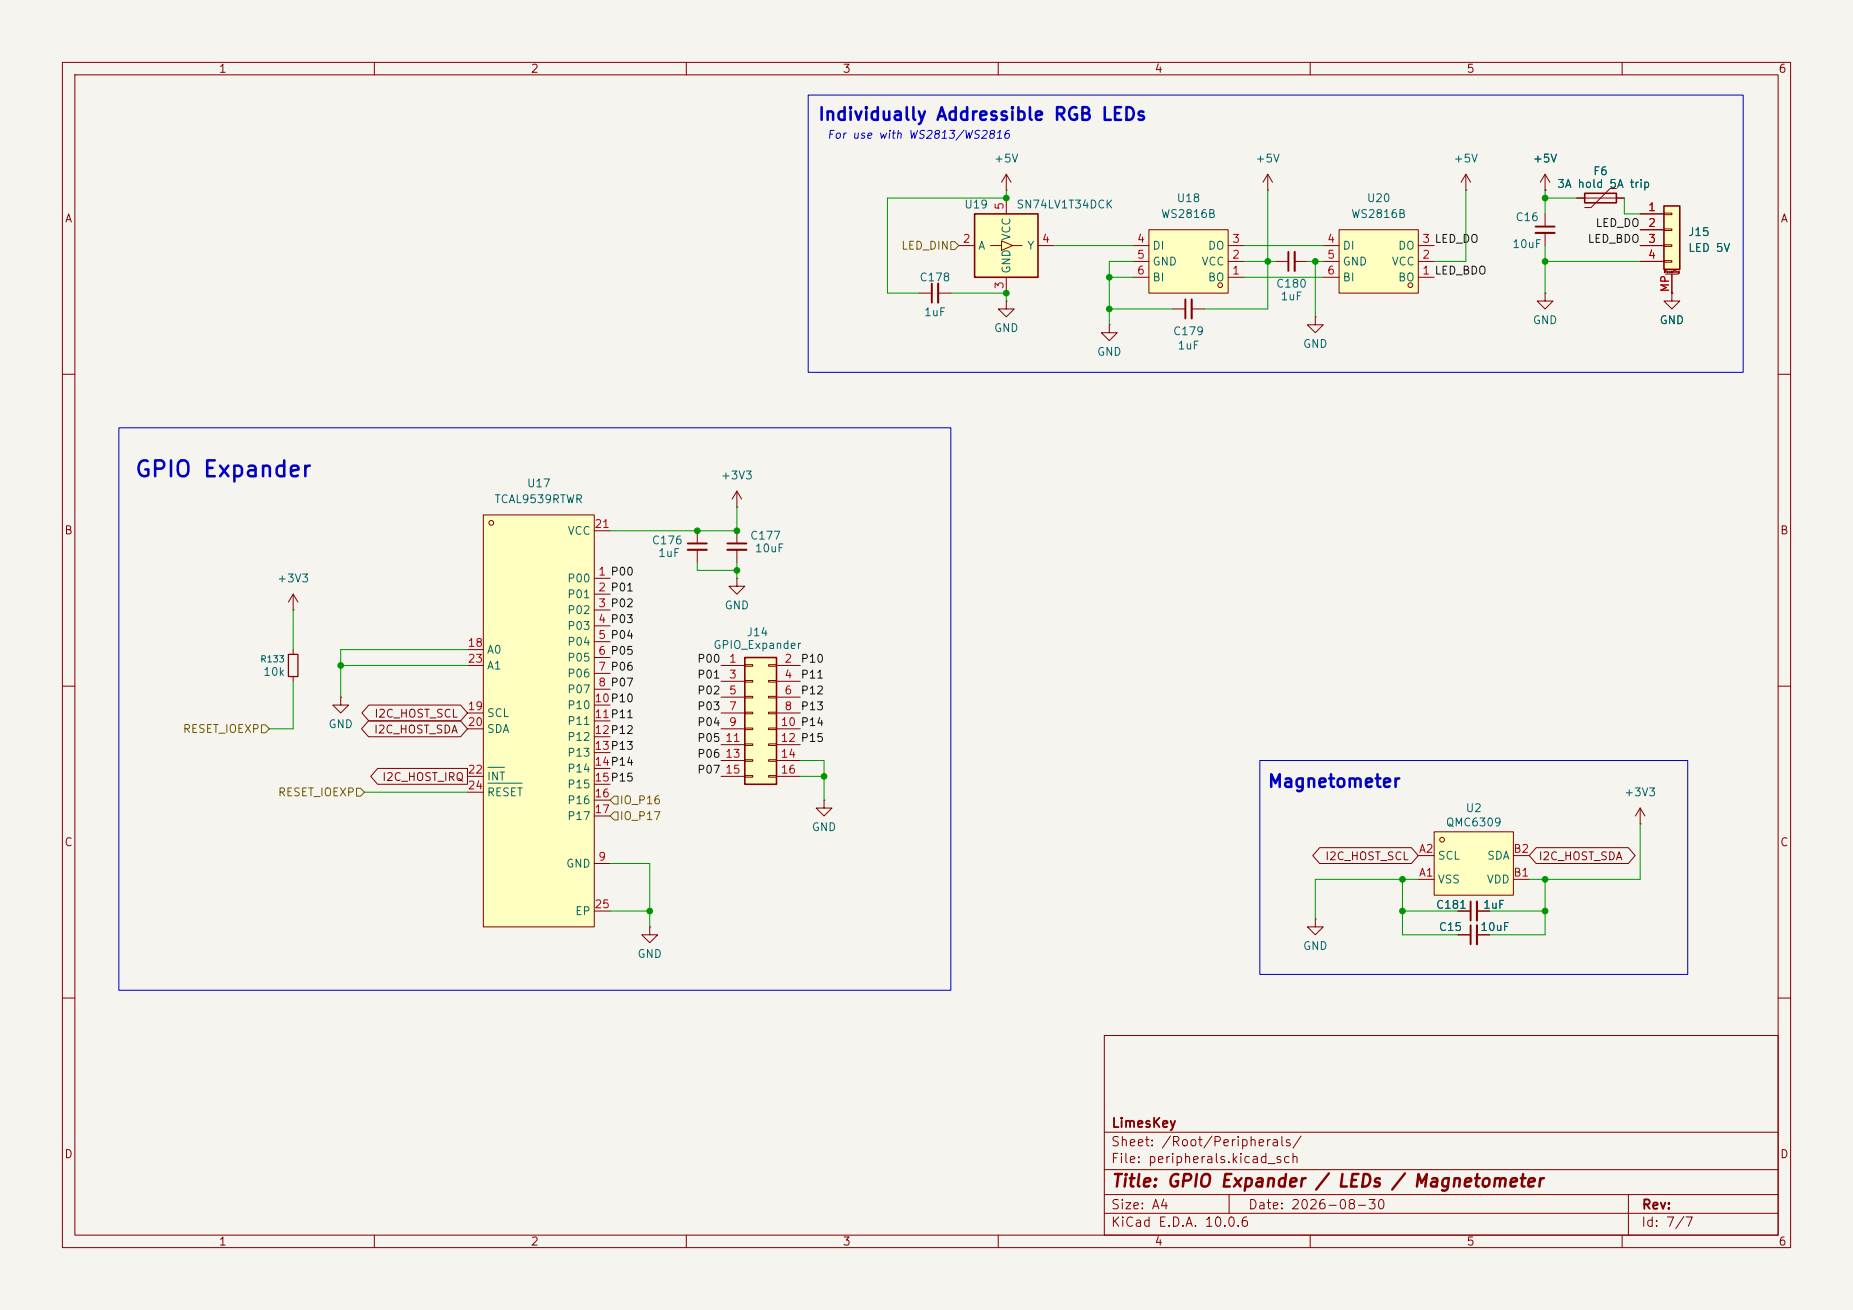
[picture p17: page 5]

Individually Addressible RGB LEDs

LimesKey
Sheet: /Root/Peripherals/
File: peripherals.kicad_sch
Title: GPIO Expander / LEDs / Magnetometer

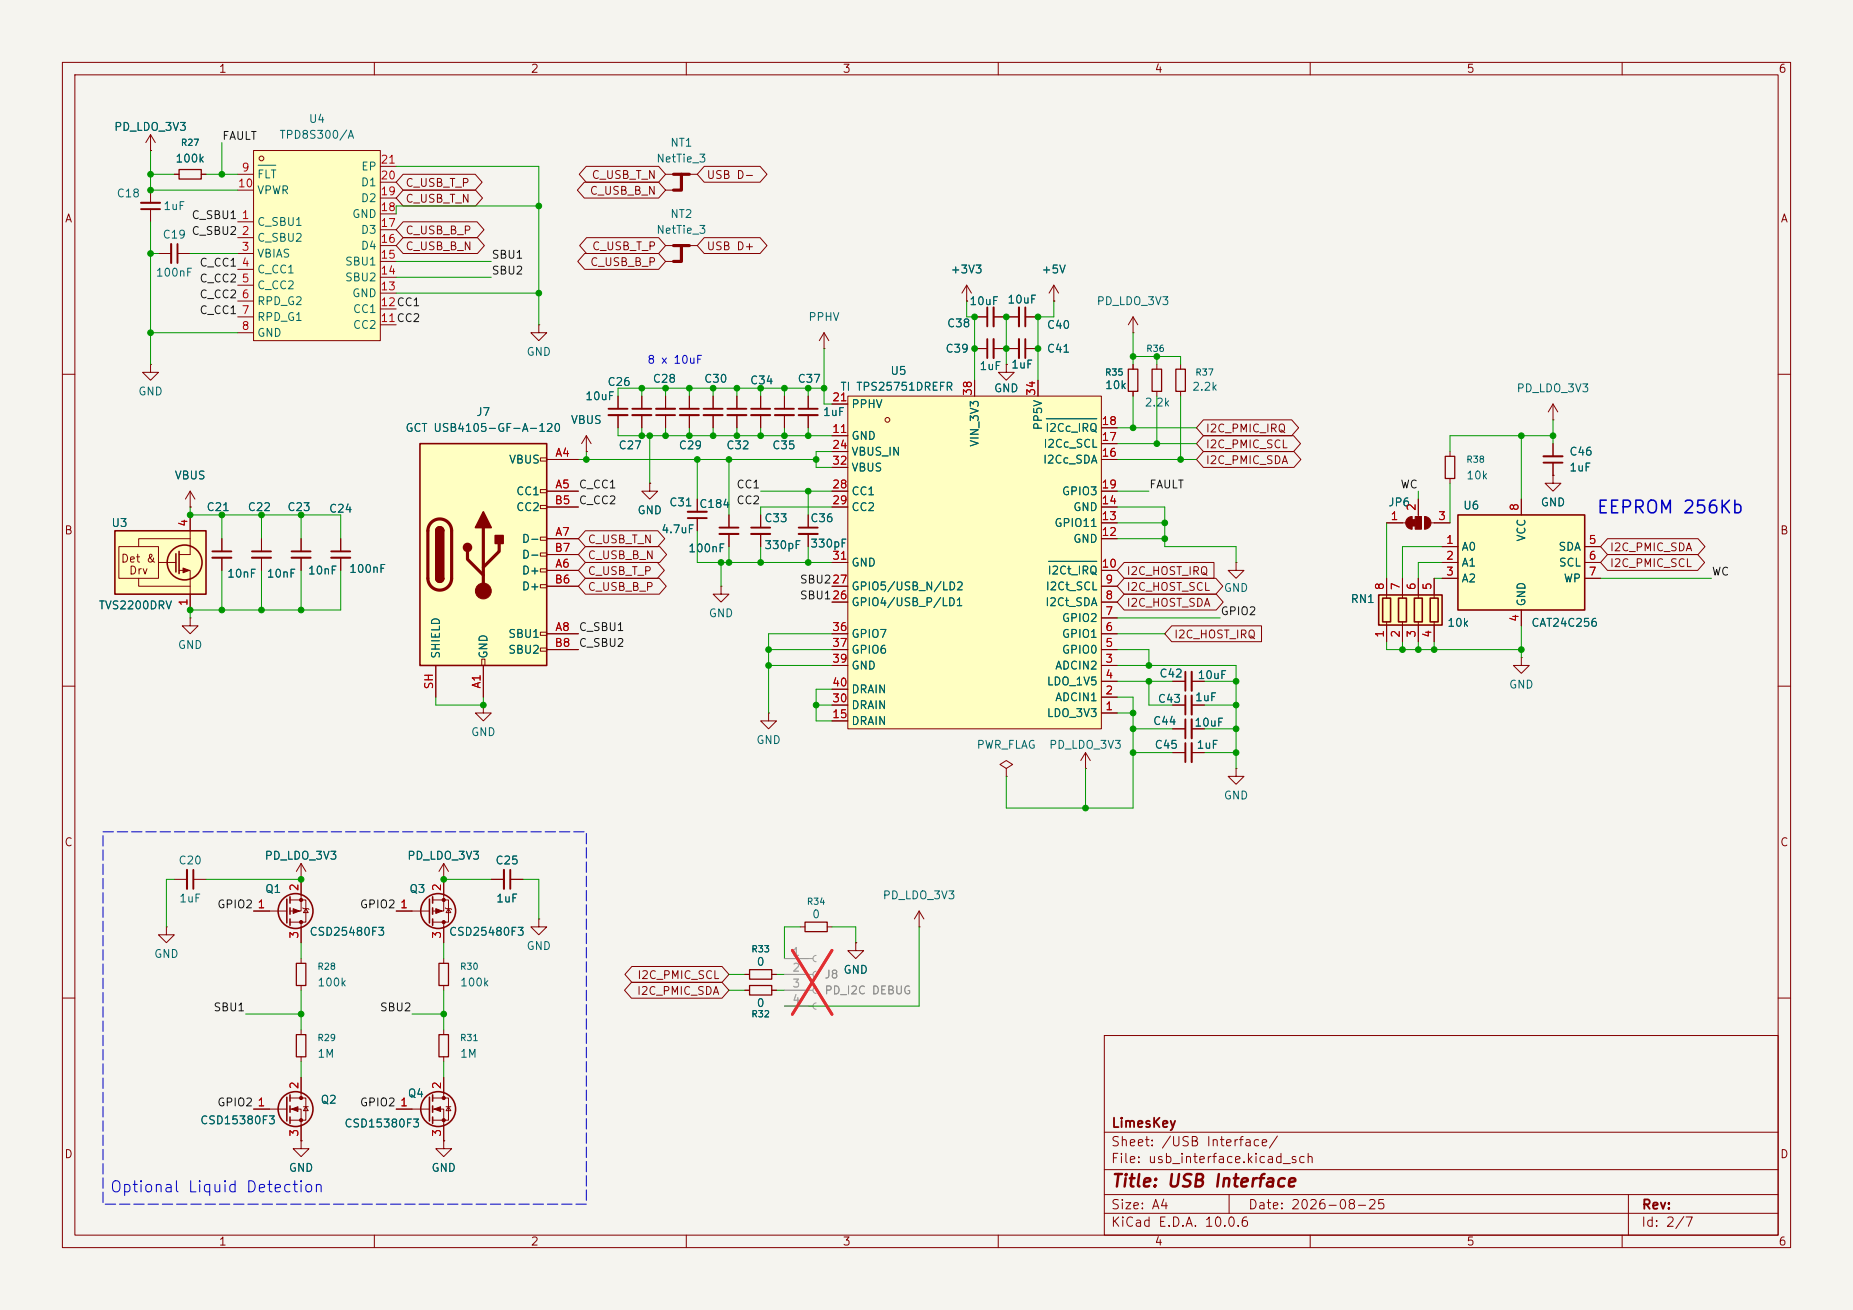
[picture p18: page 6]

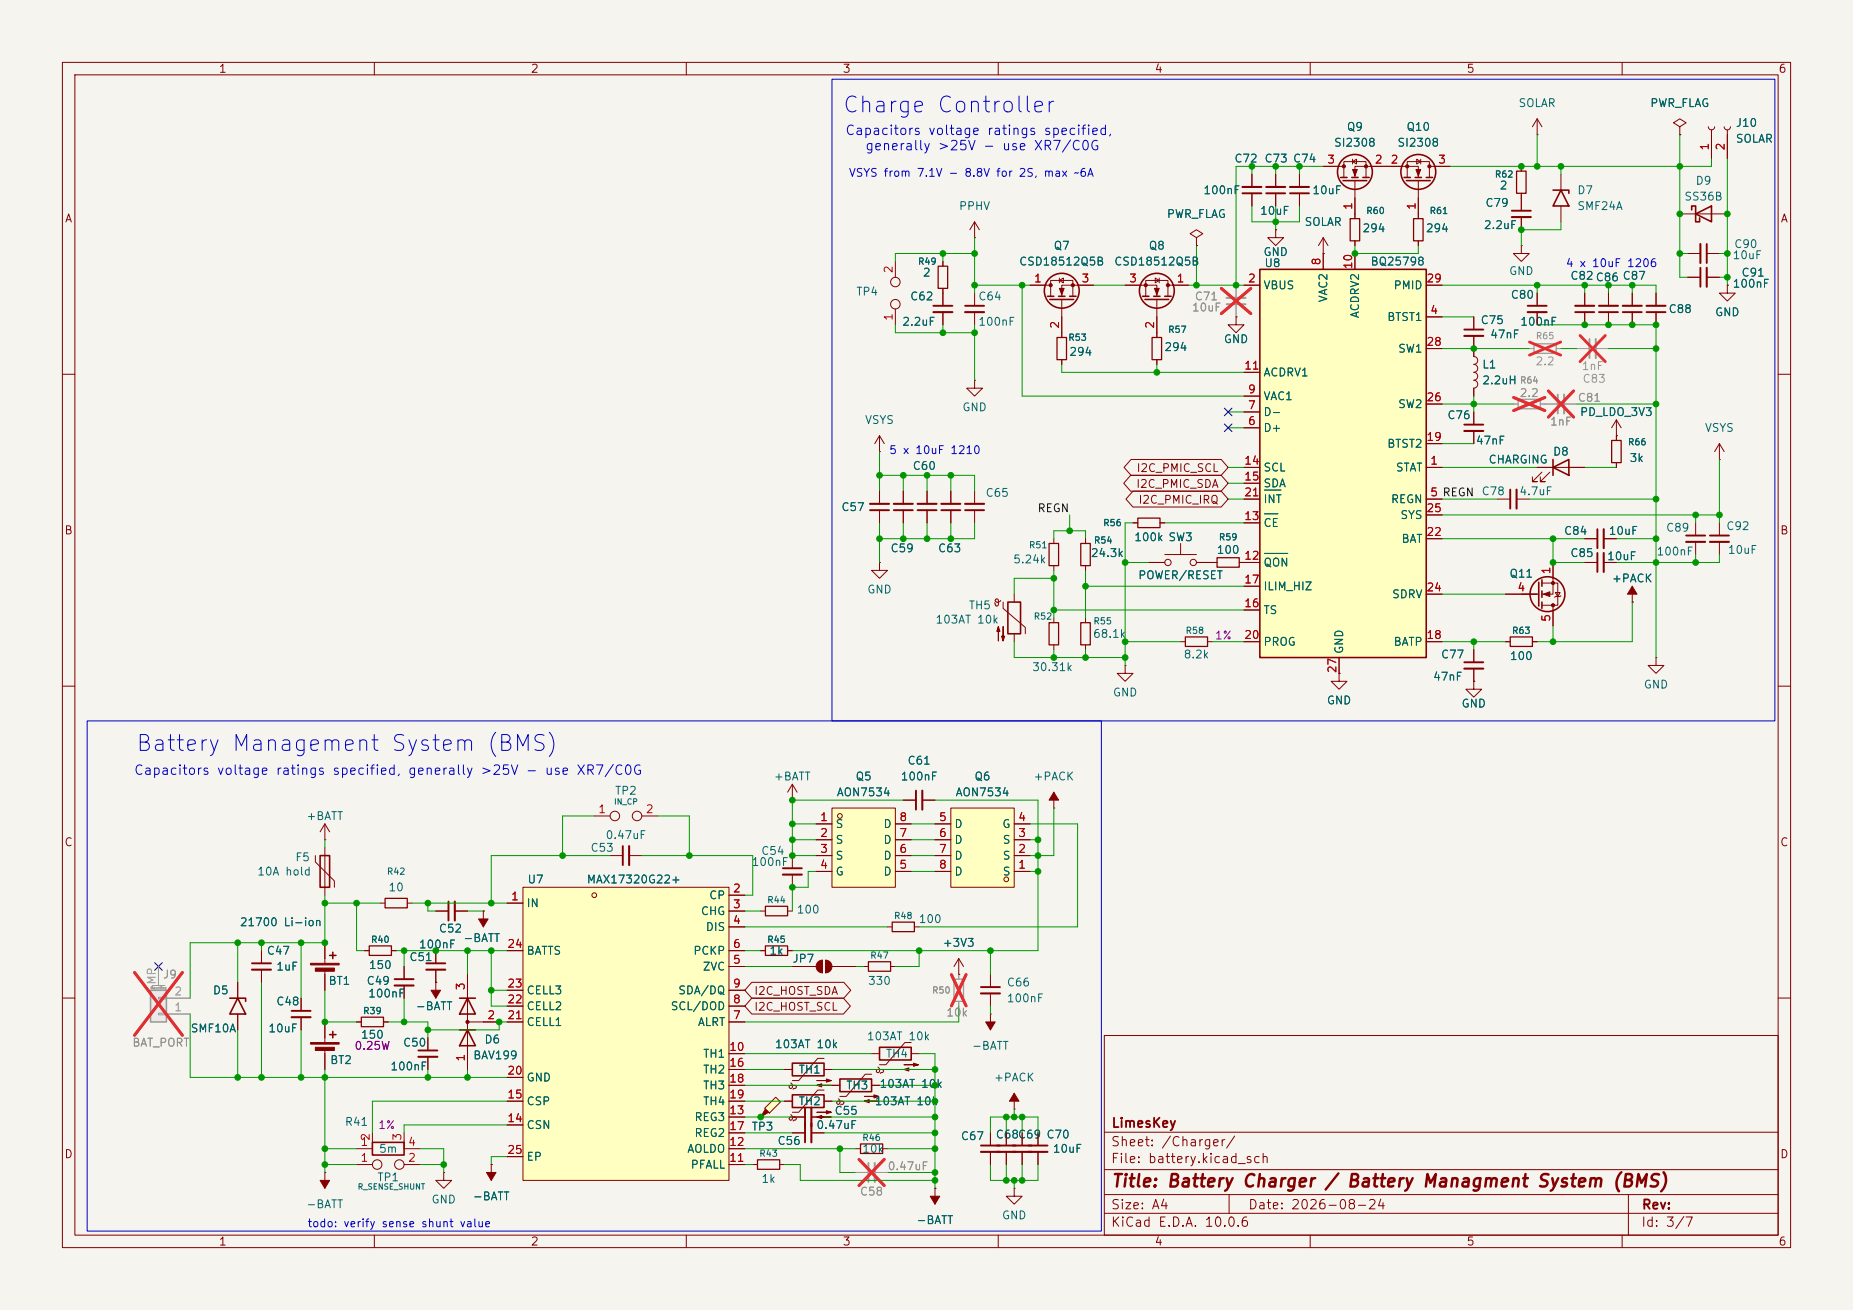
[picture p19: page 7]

Capacitors voltage ratings specified,
generally >25V - use XR7/C0G
PPHVC64

VSYS from 7.1V - 8.8V for 2S, max ~6A

REGN Battery Management System (BMS)

Capacitors voltage ratings specified, generally >25V - use XR7/C0G

TH1 10 PFALL 11 AOLDO 12 REG3 13 CSN 14 CSP 15

LimesKey
Sheet: /Charger/
File: battery.kicad_sch
Title: Battery Charger / Battery Managment System (BMS)

todo: verify sense shunt value

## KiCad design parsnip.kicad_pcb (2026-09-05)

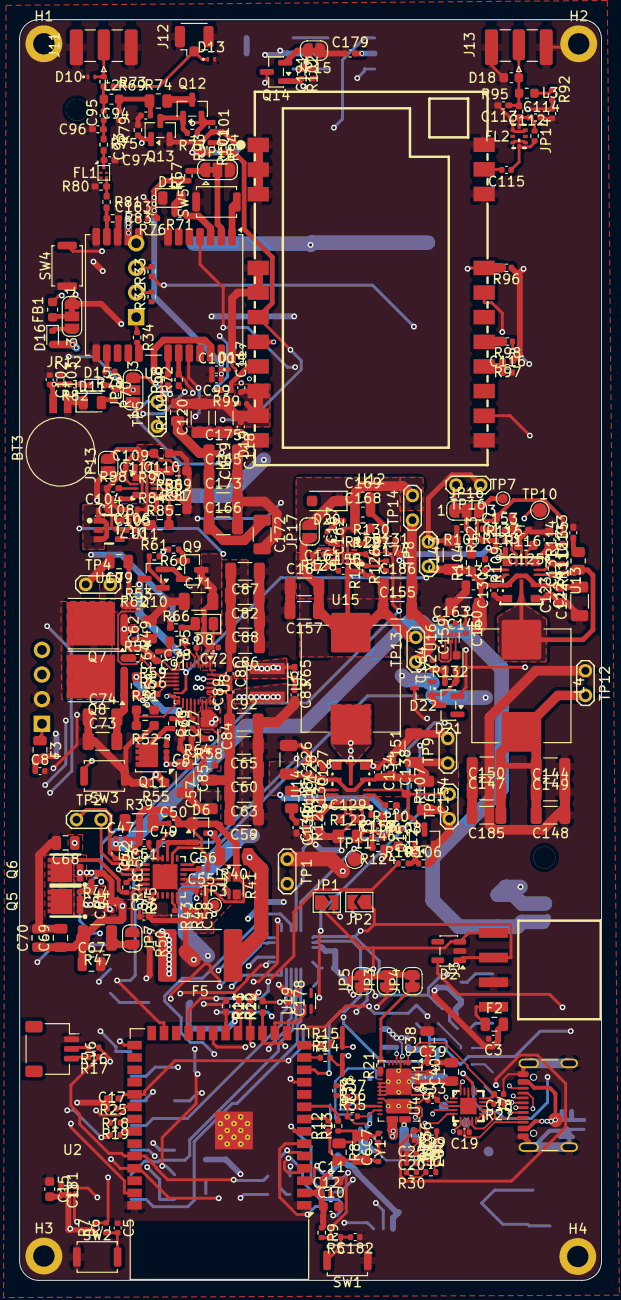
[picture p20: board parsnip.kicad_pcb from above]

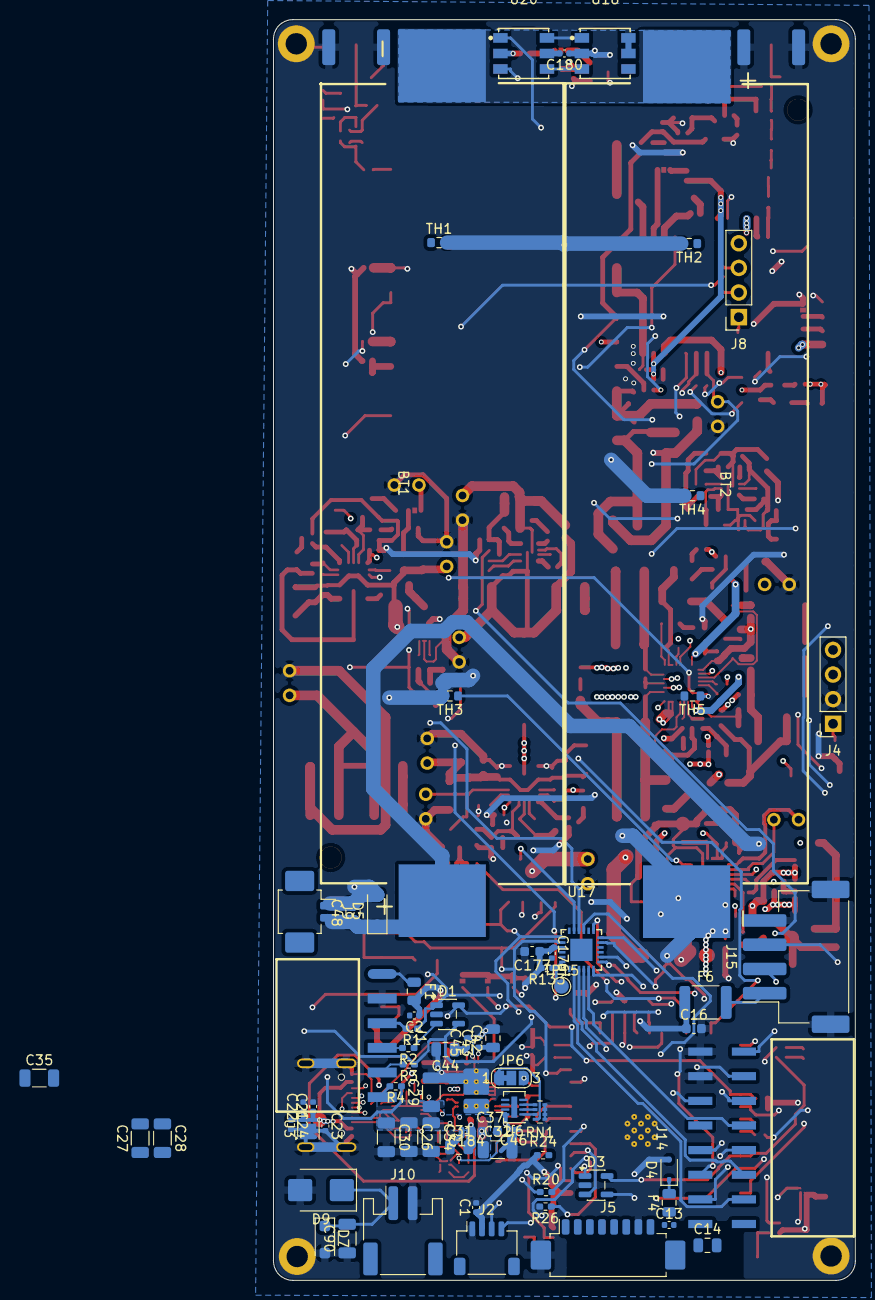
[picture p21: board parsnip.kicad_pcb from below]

Board: 4 copper layers, 60.0 x 130.0 mm, 450 parts (71 on the bottom side), 261 nets.

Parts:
BT1, BT2: 21700 Li-ion; BAT-SMD_L82.5.5-W25-BH-21700-B1BJ001
BT3: MS621FE 5.5mAh; BatteryHolder_Seiko_MS621F
C1, C2, C3, C8, C13, C104, C105: 2.2uF; C_0402_1005Metric
C5, C19, C24, C49, C50, C51, C54, C61, C64, C66, C72, C80, C89, C91, C116, C121, C124, C128, C130, C131, C134, C136, C184: 100nF; C_0402_1005Metric
C6, C7: 7pF; C_0402_1005Metric
C10, C11, C15, C16, C110, C168, C169, C177: 10uF; C_0603_1608Metric
C12, C17, C18, C20, C25, C39, C41, C43, C45, C46, C47, C52, C94, C100, C117, C118, C137, C146, C156, C163, C164, C167, C174, C176, C178, C179, C180, C181, C182, C183: 1uF; C_0402_1005Metric
C14, C38, C40, C42, C44, C48, C67, C68, C69, C70: 10uF; C_0805_2012Metric
C21, C22, C23: 10nF; C_0402_1005Metric
C26, C27, C28, C29, C30, C32, C34, C35, C57, C59, C60, C63, C65, C71, C73, C74, C82, C84, C85, C86, C87, C88, C90, C92, C122, C126, C141, C143, C151, C154: 10uF; C_1206_3216Metric
C31: 4.7uF; C_0805_2012Metric
C33, C36: 330pF; C_0402_1005Metric
C37, C123, C127, C132, C138: 1uF; C_0603_1608Metric
C53, C55, C56, C58: 0.47uF; C_0402_1005Metric
C62, C79: 2.2uF; C_0805_2012Metric
C75, C76, C77: 47nF; C_0402_1005Metric
C78: 4.7uF; C_0603_1608Metric
C81, C83: 1nF; C_0402_1005Metric_Pad0.74x0.62mm_HandSolder
C93: 22pF; C_0402_1005Metric
C95, C115: 47pF; C_0402_1005Metric
C96, C97: 10nF; C_0402_1005Metric_Pad0.74x0.62mm_HandSolder
C99, C102, C103, C106, C111: 10uF; C_0402_1005Metric
C101: 4.7uF; C_0402_1005Metric
C108, C109, C161, C162: 2.2nF; C_0402_1005Metric
C112, C159, C160: 1nF; C_0402_1005Metric
C113, C114: 1pF; C_0402_1005Metric_Pad0.74x0.62mm_HandSolder
C119, C120, C144, C147, C148, C149, C150, C155, C157, C165, C166, C172, C173, C175, C185, C186, C187: 22uF; C_1206_3216Metric
C125, C129, C135, C145: 2.2uF; C_0603_1608Metric
C133, C139: 220pF; C_0402_1005Metric_Pad0.74x0.62mm_HandSolder
C153, C158: 5.6pF; C_0402_1005Metric_Pad0.74x0.62mm_HandSolder
D1, D2, D3: ESDS314DBVR; SOT-23-5
D4: 1N5819WS; D_SOD-323
D5: SMF10A; D_SOD-123
D6: BAV199; SOT-23
D7: SMF24A; D_SOD-123F
D8: CHARGING; LED_0805_2012Metric
D9: SS36B; D_SMB
D10: TI ESD501; Texas_DPY0002A_0.6x1mm_P0.65mm
D11: LED Red; LED_0805_2012Metric
D12: LED Blue; LED_0805_2012Metric
D13: ESD501; Texas_DPY0002A_0.6x1mm_P0.65mm
D14: ESD351DPYR; Texas_DPY0002A_0.6x1mm_P0.65mm
D15: RB531SM-30; D_SOD-523
D16: RB531SM-30T2R; D_SOD-523
D17, D19: TPD1E10B06; Texas_DPY0002A_0.6x1mm_P0.65mm
D18: PGB1010603; C_0603_1608Metric
D20: SMF6.0A; D_SOD-123F
D21: BAT54A; SOT-23
D22: BAT54W; SOT-323_SC-70
F1, F3: 1A Hold; Fuse_0805_2012Metric
F2: 2A Hold, 4A Trip; Fuse_0805_2012Metric
F4: SMD0805B035TF; Fuse_0805_2012Metric
F5: 10A hold; Fuse_2920_7451Metric
F6: 3A hold 5A trip; Fuse_1812_4532Metric
FB1: BLM18HG601SN1D; L_0603_1608Metric
FL1: B39162B4327P810; Filter_1411-5_1.4x1.1mm
FL2: 0900LP15B0063001E; FILTER-SMD_0805-8P-L2.0-W1.2-TL
H1, H2, H3, H4: MountingHole_Pad; MountingHole_2.2mm_M2_DIN965_Pad
J1: SPI BUS; HDR-SMD_6P-P2.54-H-F-W11.7
J2: I2C3; JST_SH_SM04B-SRSS-TB_1x04-1MP_P1.00mm_Horizontal
J3: I2C1; CONN-SMD_4P-P2.54_HX-PM2.54-1X4PWT
J4: I2C2; PinSocket_1x04_P2.54mm_Vertical
J5: e-Ink Display Connector; Molex_PicoBlade_53261-0871_1x08-1MP_P1.25mm_Horizontal
J6: UART0; JST_SH_SM03B-SRSS-TB_1x03-1MP_P1.00mm_Horizontal
J7: GCT USB4105-GF-A-120; USB_C_Receptacle_GCT_USB4105-xx-A_16P_TopMnt_Horizontal
J8: PD_I2C DEBUG; PinSocket_1x04_P2.54mm_Vertical
J9: BAT_PORT; Molex_PicoBlade_53261-0271_1x02-1MP_P1.25mm_Horizontal
J10: SOLAR; JST_PH_S2B-PH-SM4-TB_1x02-1MP_P2.00mm_Horizontal
J11, J13: Conn_Coaxial; SMA_Samtec_SMA-J-P-H-ST-EM1_EdgeMount
J12: Conn_Coaxial_Small; U.FL_Hirose_U.FL-R-SMT-1_Vertical
J14: GPIO_Expander; HDR-SMD_16P-P2.54_HXPM2.54-2X8PWT
J15: LED 5V; JST_XH_S4B-XH-SM4-TB_1x04-1MP_P2.50mm_Horizontal
JP1, JP2: SolderJumper_2_Open; SolderJumper-2_P1.3mm_Open_TrianglePad1.0x1.5mm
JP3: I2C_IRQ_PULLUP; SolderJumper-2_P1.3mm_Bridged_RoundedPad1.0x1.5mm
JP4: I2C_SDA_PULLUP; SolderJumper-2_P1.3mm_Bridged_RoundedPad1.0x1.5mm
JP5: I2C_SCL_PULLUP; SolderJumper-2_P1.3mm_Bridged_RoundedPad1.0x1.5mm
JP6: WRITE_PROTECT; SolderJumper-3_P1.3mm_Bridged12_RoundedPad1.0x1.5mm_NumberL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
JP7: ZVC; SolderJumper-2_P1.3mm_Open_RoundedPad1.0x1.5mm
JP10: SolderJumper_3_Open; SolderJumper-3_P1.3mm_Open_RoundedPad1.0x1.5mm_NumberLabels
JP11: I2C/UART/SPI; SolderJumper-3_P1.3mm_Bridged12_RoundedPad1.0x1.5mm
JP12, JP16: SolderJumper_3_Bridged12; SolderJumper-3_P1.3mm_Bridged12_RoundedPad1.0x1.5mm_NumberL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
JP13: DISABLE_GNSS_PROT; SolderJumper-2_P1.3mm_Open_RoundedPad1.0x1.5mm
JP14: BYPASS_FILTER; R_0402_1005Metric
JP15: ANT_DETECT; SolderJumper-2_P1.3mm_Bridged_RoundedPad1.0x1.5mm
JP17: DISABLE_5V_PROT; SolderJumper-2_P1.3mm_Open_RoundedPad1.0x1.5mm
L1: 2.2uH; L_Vishay_IFSC-1515AH_4x4x1.8mm
L2: 47nH; L_0603_1608Metric
L3: 470nH; L_0603_1608Metric
L4: 2.2uH; L_Sunlord_MWSA1003S
L5: 3.3uH 11A Sat; L_APV_APH1040
NT1, NT2: NetTie_3; NetTie-3_SMD_Pad0.5mm
Q1, Q3: CSD25480F3; Texas_PicoStar_DFN-3_0.69x0.60mm
Q2, Q4: CSD15380F3; Texas_PicoStar_DFN-3_0.69x0.60mm
Q5, Q6: AON7534; PQFN-8_L3.1-W3.1-P0.65-LS3.3-BL
Q7, Q8: CSD18512Q5B; VSONP-8-1EP_5x6_P1.27mm
Q9, Q10: SI2308; SOT-23
Q11: CSD17581Q3A; VSON-8_3.3x3.3mm_P0.65mm_NexFET
Q12: AO3401A; SOT-23
Q13: BSS138; SOT-23
Q14, Q15: 2N7002; SOT-23
R1, R2, R3, R4: 33; R_0402_1005Metric_Pad0.72x0.64mm_HandSolder
R5, R6, R12, R13, R14, R15, R18, R19, R32, R33, R34, R69, R73, R93: 0; R_0402_1005Metric
R7, R9, R35, R38, R46, R50, R67, R76, R92, R94, R97, R101, R113, R119, R132: 10k; R_0402_1005Metric
R8: 10M; R_0805_2012Metric
R10, R11: 22; R_0402_1005Metric_Pad0.72x0.64mm_HandSolder
R16, R17, R98: 22; R_0402_1005Metric
R20, R24, R25, R26, R133: 10k; R_0402_1005Metric_Pad0.72x0.64mm_HandSolder
R21, R22, R68, R72: 2.2k; R_0402_1005Metric_Pad0.72x0.64mm_HandSolder
R23: 100k; R_0402_1005Metric_Pad0.72x0.64mm_HandSolder
R27, R28, R30, R56, R77, R79, R86, R91, R96, R105, R106, R108, R130, R131: 100k; R_0402_1005Metric
R29, R31, R102: 1M; R_0402_1005Metric
R36, R37: 2.2k; R_0402_1005Metric
R39, R40: 150; R_1206_3216Metric
R41: 5m; R_Shunt_0805_2012Metric_Kelvin
R42, R114, R120: 10; R_0402_1005Metric
R43, R45, R71, R78, R99: 1k; R_0402_1005Metric
R44, R48, R59, R63, R103: 100; R_0402_1005Metric
R47: 330; R_1210_3225Metric
R49, R62: 2; R_0402_1005Metric
R51: 5.24k; R_0603_1608Metric_Pad0.98x0.95mm_HandSolder
R52: 30.31k; R_0603_1608Metric_Pad0.98x0.95mm_HandSolder
R53, R57, R60, R61: 294; R_0402_1005Metric
R54: 24.3k; R_0603_1608Metric_Pad0.98x0.95mm_HandSolder
R55: 68.1k; R_0603_1608Metric_Pad0.98x0.95mm_HandSolder
R58: 8.2k; R_0402_1005Metric_Pad0.72x0.64mm_HandSolder
R64, R65: 2.2; R_0402_1005Metric_Pad0.72x0.64mm_HandSolder
R66: 3k; R_0402_1005Metric_Pad0.72x0.64mm_HandSolder
R70: 2k; R_0402_1005Metric
R74: 62; R_0805_2012Metric
R75, R95: 0; R_0402_1005Metric_Pad0.72x0.64mm_HandSolder
R80, R83: 150; R_0402_1005Metric_Pad0.72x0.64mm_HandSolder
R81: 37.4; R_0402_1005Metric_Pad0.72x0.64mm_HandSolder
R82: 4.7k; R_0402_1005Metric
R84: 150k; R_0402_1005Metric
R85: 215k; R_0603_1608Metric_Pad0.98x0.95mm_HandSolder
R87: 113k; R_0603_1608Metric_Pad0.98x0.95mm_HandSolder
R88: 6.65k; R_0402_1005Metric_Pad0.72x0.64mm_HandSolder
R89: 200k; R_0603_1608Metric_Pad0.98x0.95mm_HandSolder
R90: 301k; R_0402_1005Metric
R100: 0; R_0805_2012Metric
R104, R107, R115, R121: 402k; R_0603_1608Metric
R109, R110: 6.04k; R_0402_1005Metric_Pad0.72x0.64mm_HandSolder
R111, R117: 100; R_0402_1005Metric_Pad0.72x0.64mm_HandSolder
R112, R118: 2.2; R_0805_2012Metric
R116: 174k; R_0402_1005Metric_Pad0.72x0.64mm_HandSolder
R122: 101k; R_0805_2012Metric_Pad1.20x1.40mm_HandSolder
R123, R124: 1k; R_0402_1005Metric_Pad0.72x0.64mm_HandSolder
R125: 86.6k; R_0402_1005Metric
R126: 3.92k; R_0402_1005Metric
R127: 27.4k; R_0402_1005Metric
R128: 750; R_0402_1005Metric_Pad0.72x0.64mm_HandSolder
R129: 280k; R_0603_1608Metric
RN1: 10k; R_Array_Concave_4x0402
SW1: ESP_RESET; SW_Push_SPST_NO_Alps_SKRK
SW2: BOOT; SW_Push_SPST_NO_Alps_SKRK
SW3: POWER/RESET; SW_Push_SPST_NO_Alps_SKRK
SW4: RESET_GNSS; SW_Push_SPST_NO_Alps_SKRK
SW5: SAFEBOOT_GNSS; SW_Push_SPST_NO_Alps_SKRK
TH1, TH2, TH3, TH4, TH5: 103AT 10k; R_0603_1608Metric
TP1: R_SENSE_SHUNT; TestPoint_2Pads_Pitch2.54mm_Drill0.8mm
TP2: IN_CP; TestPoint_2Pads_Pitch2.54mm_Drill0.8mm
TP3: REG3; TestPoint_Pad_D1.0mm
TP4: PPHV; TestPoint_2Pads_Pitch2.54mm_Drill0.8mm
TP5: CS_GPS; TestPoint_2Pads_Pitch2.54mm_Drill0.8mm
TP6: SYNC_1; TestPoint_2Pads_Pitch2.54mm_Drill0.8mm
TP7: EN_3V3; TestPoint_Pad_D1.0mm
TP8, TP9: VSYS; TestPoint_2Pads_Pitch2.54mm_Drill0.8mm
TP10, TP11: PGOOD; TestPoint_Pad_D1.5mm
TP12: 3V3; TestPoint_2Pads_Pitch2.54mm_Drill0.8mm
TP13: 5V_RAW; TestPoint_2Pads_Pitch2.54mm_Drill0.8mm
TP14: 5V; TestPoint_2Pads_Pitch2.54mm_Drill0.8mm
TP15: GPIO_EXP_RESET; TestPoint_Pad_D1.5mm
TP16: SYNC_2; TestPoint_2Pads_Pitch2.54mm_Drill0.8mm
U1: ESP32-S3-WROOM-1-N16R8; ESP32-S3-WROOM-1
U2: QMC6309; X1-WLB0808-4_L0.8-W0.8-P0.40-TL
U3: TVS2200DRV; WSON-6-1EP_2x2mm_P0.65mm_EP1x1.6mm
U4: TPD8S300/A; WQFN-20_L3.0-W3.0-P0.40-TL-EP1.7
U5: TI TPS25751DREFR; Texas_REF0038A_WQFN-38-2EP_6x4mm_P0.4
U6: CAT24C256; DFN-8-1EP_2x3mm_P0.5mm_EP0.61x2.2mm
U7: MAX17320G22+; QFN-24_L4.0-W4.0-P0.50-BL-EP2.6
U8: BQ25798; Texas_RQM0029A_VQFN-29_4x4mm_P0.4mm
U9: NEO-M9N; ublox_NEO
U10: TPS7A2033PDBVR; SOT-23-5_L2.9-W1.6-P0.95-LS2.8-BR
U11: TPS259474LRPWR; VQFN-10_L2.0-W2.0-P0.45-TL
U12: E22P-915M30S; COMM-SMD_22P-P2.54-L38.5-W24.0_E22-400M33S
U13, U14: LM61460AASQRJRRQ1; VQFN-14-HR_L4.0-W3.5-TL_LM61460AASQRJRRQ1
U15: TPS259474ARPWR; VQFN-10_L2.0-W2.0-P0.45-TL
U16: SN74LVC1G74; X2SON-8_1.4x1mm_P0.35mm
U17: TCAL9539RTWR; TQFN-24_L4.0-W4.0-P0.50-BL-EP2.3
U18, U20: WS2816B; LED-SMD_6P-L5.0-W5.0-TL
U19: SN74LV1T34DCK; SOT-353_SC-70-5
Y1: 32.768KHz; Crystal_SMD_3215-2Pin_3.2x1.5mm
Y2: SX1M4.000M10F30TNN; Oscillator_SMD_SiT_PQFN-4Pin_2.0x1.6mm

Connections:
3V3_GNSS: C99.1, C100.2, C110.2, C111.1, D14.1 (A1), D15.2 (A), JP10.2 (C), JP13.2 (B), R67.1, R70.1, R76.1, R90.2, R91.1, U9.23 (VCC), U11.6 (OUT)
+3V3: C1.1, C2.1, C3.1, C8.1, C10.1, C11.1, C12.1, C15.2, C17.1, C38.1, C39.1, C121.2, C137.1, C144.1, C146.1, C147.1, C148.2, C149.2, C150.2, C163.1, C164.1, C174.1, C176.1, C177.1, C181.2, C185.1, D4.2 (A), F1.2, F2.2, F3.2, J2.2, JP3.2 (B), JP4.2 (B), JP5.2 (B), JP13.1 (A), L4.2, R7.1, R9.1, R23.2, R24.2, R25.2, R50.2, R93.1, R96.1, R97.1, R102.1, R113.1, R114.2, R115.2, R119.1, R123.1, R131.2, R132.1, R133.2, TP12.2, U1.2 (3V3), U2.B1 (VDD), U5.38 (VIN_3V3), U16.6 (~CLR), U16.7 (~PRE), U16.8 (VCC), U17.21 (VCC), Y2.4 (VDD)
+5V: C16.1, C40.1, C41.1, C104.1, C165.1, C166.1, C167.1, C168.1, C169.1, C172.1, C173.1, C175.1, C178.1, C179.2, C180.1, D20.1 (A1), F6.1, JP12.1 (A), JP17.2 (B), R100.1, R129.2, TP14.2, U5.34 (PP5V), U10.1 (IN), U10.3 (EN), U15.6 (OUT), U18.2 (VCC), U19.5 (VCC), U20.2 (VCC)
+BATT: C54.1, C61.1, F5.2, Q5.1 (S), Q5.2 (S), Q5.3 (S)
+PACK: C61.2, C66.1, C67.1, C68.1, C69.1, C70.1, Q6.1 (S), Q6.2 (S), Q6.3 (S), Q11.5 (D), R45.2, R47.2, R63.2
-BATT: BT2.2 (-), C47.2, C48.2, C50.2, C51.2, C52.2, C55.2, C56.2, C58.2, C66.2, D5.2 (A2), D6.1 (A), J9.1, R41.1, R43.2, R46.2, TH1.2, TH2.2, TH3.2, TH4.2, TP1.1, U7.20 (GND), U7.25 (EP)
/Charger/PMID: C80.1, C82.2, C86.2, C87.2, C88.2, U8.29 (PMID)
/Charger/REGN: C78.1, R51.2, R54.2, U8.5 (REGN)
/Root/BOOT: R6.2, R7.2, U1.27 (IO0)
/Root/BUSY_DISPLAY: D3.3 (I/O2), J5.1, U1.5 (IO5)
/Root/CS_BUS: D1.5 (I/O4), R4.1, R25.1, U1.31 (IO38)
/Root/CS_DISPLAY: D2.4 (I/O3), J5.4, R24.1, U1.10 (IO17)
/Root/D/C_DISPLAY: D3.1 (I/O1), J5.3, U1.11 (IO18)
/Root/EN: R5.2, R9.2, U1.3 (EN)
/Root/GNSS/D_SEL: JP11.2 (C), U9.2 (D_SEL)
/Root/GNSS/LNA_EN: R78.2, U9.14 (LNA_EN)
/Root/GNSS/SCL/SPI_CLK: JP2.2 (B), R72.2, U9.19 (SCL/SPI_CLK)
/Root/GNSS/SDA/SPI_CS: JP1.2 (B), R68.2, TP5.2, U9.18 (SDA/~SPI_CS)
/Root/GNSS/VCC_RF: C183.1, D16.2 (A), U9.9 (VCC_RF)
/Root/GPIO_3: R71.1, U1.15 (IO3), U9.3 (TIMEPULSE)
/Root/GPIO_4: U1.4 (IO4), U12.13 (DIO1)
/Root/GPIO_10: R23.1, R96.2, U1.18 (IO10), U12.19 (NSS)
/Root/GPIO_14: U1.22 (IO14), U12.14 (BUSY)
/Root/GPIO_21: R103.1, U1.23 (IO21)
/Root/GPIO_39: R131.1, U1.32 (IO39), U15.3 (PG/AUXOFF)
/Root/GPIO_40: R19.1, U1.33 (IO40)
/Root/GPIO_41: R18.2, U1.34 (IO41)
/Root/GPIO_42: R91.2, U1.35 (IO42), U11.3 (PG/AUXOFF)
/Root/GPIO_46: U1.16 (IO46), U19.2 (A)
/Root/GPIO_47: D21.1, U1.24 (IO47)
/Root/GPIO_48: U1.25 (IO48), U9.4 (EXTINT)
/Root/LoRa/ANT_DETECT: C112.2, Q14.1 (G), R92.1, R102.2
/Root/LoRa/EN: R18.1, R94.2, R101.1, U12.6 (EN)
/Root/LoRa/LORA_ANT: C115.1, U12.21 (ANT)
/Root/LoRa/RESET: C116.1, R19.2, R97.2, U12.15 (NRST)
/Root/P16: D21.2, R113.2, TP10.1 (1_1), U13.5 (PGOOD), U17.16
/Root/P17: D22.3 (K), R119.2, TP11.1 (1_1), U14.5 (PGOOD), U17.17
/Root/Peripherals/LED_BDO: J15.3, U20.1 (BO)
/Root/Peripherals/LED_DO: J15.2, U20.3 (DO)
/Root/Peripherals/P00: J14.1, U17.1 (P00)
/Root/Peripherals/P01: J14.3, U17.2 (P01)
/Root/Peripherals/P02: J14.5, U17.3 (P02)
/Root/Peripherals/P03: J14.7, U17.4 (P03)
/Root/Peripherals/P04: J14.9, U17.5 (P04)
/Root/Peripherals/P05: J14.11, U17.6 (P05)
/Root/Peripherals/P06: J14.13, U17.7 (P06)
/Root/Peripherals/P07: J14.15, U17.8 (P07)
/Root/Peripherals/P10: J14.2, U17.10
/Root/Peripherals/P11: J14.4, U17.11
/Root/Peripherals/P12: J14.6, U17.12
/Root/Peripherals/P13: J14.8, U17.13
/Root/Peripherals/P14: J14.10, U17.14
/Root/Peripherals/P15: J14.12, U17.15
/Root/Peripherals/RESET_IOEXP: R133.1, TP15.1 (1_1), U17.24 (~RESET)
/Root/RESET_DISPLAY: D2.5 (I/O4), J5.2, R26.1, U1.6 (IO6)
/Root/Rails/5V_RAW: C155.1, C156.2, C157.1, C186.1, C187.2, JP17.1 (A), L5.2, R120.2, R121.2, R124.1, R125.1, TP13.2, U15.5 (IN)
/Root/Rails/SYNC_1: C159.1, Q15.3 (D), R107.2, R108.1, TP6.2, U14.7 (EN/SYNC)
/Root/Rails/SYNC_2: C160.1, JP16.1 (A), TP16.2, U13.7 (EN/SYNC)
/USB Interface/CC1: C36.1, U4.12 (CC1), U5.28 (CC1)
/USB Interface/CC2: C33.1, U4.11 (CC2), U5.29 (CC2)
/USB Interface/C_CC1: J7.A5 (CC1), U4.4 (C_CC1), U4.7 (RPD_G1)
/USB Interface/C_CC2: J7.B5 (CC2), U4.5 (C_CC2), U4.6 (RPD_G2)
/USB Interface/C_SBU1: J7.A8 (SBU1), U4.1 (C_SBU1)
/USB Interface/C_SBU2: J7.B8 (SBU2), U4.2 (C_SBU2)
/USB Interface/FAULT: R27.2, U4.9 (~FLT), U5.19 (GPIO3)
/USB Interface/GPIO2: Q1.1 (G), Q2.1 (G), Q3.1 (G), Q4.1 (G), U5.7 (GPIO2)
/USB Interface/SBU1: R28.2, R29.1, U4.15 (SBU1), U5.26 (GPIO4/USB_P/LD1)
/USB Interface/SBU2: R30.2, R31.1, U4.14 (SBU2), U5.27 (GPIO5/USB_N/LD2)
/USB Interface/WC: JP6.2 (C), U6.7 (WP)
C_USB_B_N: J7.B7 (D-), NT1.3, U4.16 (D4)
C_USB_B_P: J7.B6 (D+), NT2.3, U4.17 (D3)
C_USB_T_N: J7.A7 (D-), NT1.1, U4.19 (D2)
C_USB_T_P: J7.A6 (D+), NT2.1, U4.20 (D1)
GND: BT3.2 (-), C1.2, C2.2, C3.2, C5.1, C6.2, C7.1, C8.2, C10.2, C11.2, C12.2, C13.2, C14.2, C15.1, C16.2, C17.2, C18.1, C19.2, C20.2, C21.2, C22.2, C23.2, C24.2, C25.1, C26.2, C27.2, C28.1, C29.2, C30.2, C31.1, C32.2, C33.2, C34.2, C35.2, C36.2, C37.2, C38.2, C39.2, C40.2, C41.2, C42.2, C43.2, C44.2, C45.2, C46.1, C57.1, C59.1, C60.1, C62.2, C63.1, C64.2, C65.1, C67.2, C68.2, C69.2, C70.2, C71.1, C72.1, C73.1, C74.1, C77.2, C78.2, C79.2, C80.2, C81.2, C82.1, C83.2, C84.2, C85.2, C86.1, C87.1, C88.1, C89.2, C90.1, C91.2, C92.2, C93.2, C94.2, C96.2, C97.2, C99.2, C100.1, C101.2, C102.1, C103.1, C104.2, C105.2, C106.1, C108.2, C109.1, C110.1, C111.2, C112.1, C113.2, C114.2, C116.2, C117.2, C118.2, C119.2, C120.2, C121.1, C122.1, C123.1, C124.2, C125.2, C126.1, C127.1, C128.2, C129.2, C130.1, C132.1, C133.2, C134.1, C135.1, C137.2, C138.1, C139.2, C141.2, C143.2, C144.2, C145.1, C146.2, C147.2, C148.1, C149.1, C150.1, C151.2, C154.2, C155.2, C156.1, C157.2, C161.1, C162.1, C163.2, C164.2, C165.2, C166.2, C167.2, C168.2, C169.2, C172.2, C173.2, C174.2, C175.2, C176.2, C177.2, C178.2, C179.1, C180.2, C181.1, C182.1, C183.2, C184.2, C185.2, C186.2, C187.1, D1.2 (GND), D2.2 (GND), D3.2 (GND), D7.2 (A2), D9.2 (A), D10.1 (A1), D11.1 (K), D12.1 (K), D13.2 (A2), D14.2 (A2), D17.2 (A2), D18.1 (A1), D19.1 (A1), D20.2 (A2), FL1.2, FL1.3, FL1.5, FL2.1 (GND), FL2.3 (GND), FL2.5 (GND), FL2.7 (GND), H1.1 (1_1), H2.1 (1_1), H3.1 (1_1), H4.1 (1_1), J1.2, J2.1, J3.2, J4.2, J5.7, J5.MP (MountPin), J6.1, J7.A1 (GND), J7.A12 (GND), J7.B1 (GND), J7.B12 (GND), J7.SH (SHIELD), J10.2, J11.2 (Ext), J12.2 (Ext), J13.2 (Ext), J14.14, J14.16, J15.4, J15.MP (MountPin), JP11.3 (B), JP15.1 (A), Q2.3 (S), Q4.3 (S), Q13.2 (S), Q15.2 (S), R26.2, R34.2, R41.4, R52.1, R55.2, R56.1, R58.1, R79.2, R80.1, R83.1, R86.2, R87.2, R88.1, R89.1, R101.2, R105.2, R106.2, R108.2, R109.1, R110.1, R116.1, R122.1, R127.2, R128.2, R130.2, RN1.1 (R1.1), RN1.2 (R2.1), RN1.3 (R3.1), RN1.4 (R4.1), SW1.1, SW2.1, SW3.1, SW4.1, SW5.1, TH5.2, TP1.2, TP4.1, TP5.1, TP6.1, TP8.2, TP9.2, TP12.1, TP13.1, TP14.1, TP16.1, U1.1 (GND), U1.40 (GND), U1.41 (GND), U2.A1 (VSS), U3.1 (GND), U3.2 (GND), U3.3 (GND), U3.7 (GND), U4.8 (GND), U4.13 (GND), U4.18 (GND), U4.21 (EP), U5.3 (ADCIN2), U5.5 (GPIO0), U5.11 (GND), U5.12 (GND), U5.13 (GPIO11), U5.14 (GND), U5.31 (GND), U5.36 (GPIO7), U5.37 (GPIO6), U5.39 (GND), U6.4 (GND), U8.27 (GND), U9.7 (VDD_USB), U9.10 (GND), U9.12 (GND), U9.13 (GND), U9.24 (GND), U10.2 (GND), U11.8 (GND), U12.1 (GND), U12.2 (GND), U12.3 (GND), U12.4 (GND), U12.5 (GND), U12.11 (GND), U12.12 (GND), U12.20 (GND), U12.22 (GND), U13.3 (AGND), U13.9 (PGND1), U13.11 (PGND2), U14.3 (AGND), U14.9 (PGND1), U14.11 (PGND2), U15.8 (GND), U16.4 (GND), U17.9 (GND), U17.18 (A0), U17.23 (A1), U17.25 (EP), U18.5 (GND), U18.6 (BI), U19.3 (GND), U20.5 (GND), Y2.2 (GND)
GPS_ANT: R81.2, R83.2, U9.11 (RF_IN)
I2C_HOST_IRQ: R20.1, U1.7 (IO7), U5.6 (GPIO1), U5.10 (~I2Ct_IRQ), U17.22 (~INT)
I2C_HOST_SCL: D2.1 (I/O1), J2.3, J3.3, J4.3, JP2.1 (A), R22.1, U1.17 (IO9), U2.A2 (SCL), U5.9 (I2Ct_SCL), U7.8 (SCL/DOD), U17.19 (SCL)
I2C_HOST_SDA: D2.3 (I/O2), J2.4, J3.4, J4.4, JP1.1 (A), R21.1, U1.12 (IO8), U2.B2 (SDA), U5.8 (I2Ct_SDA), U7.9 (SDA/DQ), U17.20 (SDA)
I2C_PMIC_IRQ: R35.2, U5.18 (~I2Cc_IRQ), U8.21 (~INT)
I2C_PMIC_SCL: R32.1, R36.2, U5.17 (I2Cc_SCL), U6.6 (SCL), U8.14 (SCL)
I2C_PMIC_SDA: R33.1, R37.2, U5.16 (I2Cc_SDA), U6.5 (SDA), U8.15 (SDA)
MISO: D1.4 (I/O3), R3.1, R98.1, U1.21 (IO13)
MOSI: D1.3 (I/O2), J5.6, R2.1, R10.1, U12.17 (MOSI)
unnamed: BT1.1 (+), C47.1, C48.1, D5.1 (A1), F5.1, J9.2, R40.1, R42.1
unnamed: BT1.2 (-), BT2.1 (+), R39.1
unnamed: BT3.1 (+), C102.2, C103.2, R82.2, U9.22 (V_BCKP)
unnamed: C5.2, R6.1, SW2.2
unnamed: C6.1, R8.2, R12.1, Y1.1
unnamed: C7.2, R8.1, R13.1, Y1.2
unnamed: C62.1, R49.2
unnamed: C79.1, R62.2
unnamed: C81.1, R64.2
unnamed: C83.1, R65.2
unnamed: C84.1, C85.1, Q11.1 (S), Q11.2 (S), Q11.3 (S), U8.22 (BAT), U8.23 (BAT)
unnamed: C93.1, C94.1, L2.2, R74.1
unnamed: C95.1, C96.1, R75.1
unnamed: C95.2, L2.1, R69.2, R73.2
unnamed: C97.1, FL1.1, R75.2
unnamed: C133.1, R112.2
unnamed: C139.1, R118.2
unnamed: C153.1, R123.2
unnamed: C158.1, R124.2
unnamed: C182.2, R5.1, SW1.2
unnamed: D4.1 (K), F4.2
unnamed: C49.1, C51.1, D6.3 (K), R40.2, U7.22 (CELL2), U7.23 (CELL3), U7.24 (BATTS)
unnamed: C49.2, C50.1, D6.2 (common), R39.2, U7.21 (CELL1)
unnamed: D8.2 (A), R66.2
unnamed: D8.1 (K), U8.1 (STAT)
unnamed: D10.2 (A2), J11.1 (In), R69.1
unnamed: D11.2 (A), R70.2
unnamed: D12.2 (A), R71.2
unnamed: D13.1 (A1), J12.1 (In), R73.1
unnamed: D15.1 (K), R82.1
unnamed: D16.1 (K), JP12.3 (B)
unnamed: C105.1, C106.2, D17.1 (A1), R84.1, R85.1, U10.5 (OUT), U11.5 (IN)
unnamed: C113.1, D18.2 (A2), J13.1 (In), L3.2, R95.1
unnamed: C117.1, C118.1, C119.1, C120.1, D19.2 (A2), R100.2, U12.9 (VCC), U12.10 (VCC)
unnamed: D21.3, D22.1 (A), R132.2, Y2.1 (~ST)
unnamed: FL1.4, R80.2, R81.1
unnamed: F1.1, J1.1
unnamed: J1.3, R1.2
unnamed: J1.4, R2.2
unnamed: J1.5, R3.2
unnamed: J1.6, R4.2
unnamed: F2.1, J3.1
unnamed: F3.1, J4.1
unnamed: C13.1, C14.1, F4.1, J5.8
unnamed: J6.2, R16.2
unnamed: J6.3, R17.2
unnamed: J8.1, R34.1
unnamed: J8.2, R32.2
unnamed: J8.3, R33.2
unnamed: F6.2, J15.1
unnamed: JP3.1 (A), R20.2
unnamed: JP4.1 (A), R21.2
unnamed: JP5.1 (A), R22.2
unnamed: JP6.1 (A), RN1.8 (R1.2)
unnamed: JP6.3 (B), R38.1
unnamed: JP7.1 (A), U7.5 (ZVC)
unnamed: JP7.2 (B), R47.1
unnamed: JP10.1 (A), R72.1
unnamed: JP10.3 (B), R68.1
unnamed: JP11.1 (A), R67.2
unnamed: FB1.2, JP12.2 (C)
unnamed: C114.1, FL2.4 (IO), JP14.1 (A), R95.2
unnamed: C115.2, FL2.8 (IO), JP14.2 (B)
unnamed: JP15.2 (B), Q14.2 (S)
unnamed: JP16.3 (B), TP7.1 (1_1)
unnamed: JP16.2 (C), R104.2, R105.1
unnamed: L3.1, R92.2
unnamed: Q1.3 (D), R28.1
unnamed: Q2.2 (D), R29.2
unnamed: Q3.3 (D), R30.1
unnamed: Q4.2 (D), R31.2
unnamed: Q5.5 (D), Q5.6 (D), Q5.7 (D), Q5.8 (D), Q6.5 (D), Q6.6 (D), Q6.7 (D), Q6.8 (D)
unnamed: C54.2, Q5.4 (G), R44.2
unnamed: Q6.4 (G), R48.2
unnamed: Q7.2 (G), R53.1
unnamed: Q7.3 (S), Q8.3 (S)
unnamed: C71.2, C72.2, C73.2, C74.2, Q8.1 (D), Q9.3 (D), U8.2 (VBUS), U8.3 (VBUS)
unnamed: Q8.2 (G), R57.1
unnamed: Q9.1 (G), R60.1
unnamed: Q10.1 (G), R61.1
unnamed: Q9.2 (S), Q10.2 (S)
unnamed: Q11.4 (G), U8.24 (SDRV)
unnamed: Q12.3 (D), R74.2
unnamed: Q12.1 (G), Q13.3 (D), R77.2
unnamed: C101.1, FB1.1, Q12.2 (S), R77.1
unnamed: Q13.1 (G), R78.1, R79.1
unnamed: Q14.3 (D), R99.2, U12.7 (T/RCTRL)
unnamed: Q15.1 (G), R103.2, R106.1
unnamed: R59.1, SW3.2
unnamed: R93.2, R94.1
unnamed: RN1.7 (R2.2), U6.1 (A0)
unnamed: RN1.6 (R3.2), U6.2 (A1)
unnamed: RN1.5 (R4.2), U6.3 (A2)
unnamed: R10.2, U1.19 (IO11)
unnamed: R11.2, U1.20 (IO12)
unnamed: R12.2, U1.8 (IO15)
unnamed: R13.2, U1.9 (IO16)
unnamed: R15.1, U1.14 (USB_D+)
unnamed: R14.1, U1.13 (USB_D-)
unnamed: C19.1, U4.3 (VBIAS)
unnamed: U5.15 (DRAIN), U5.30 (DRAIN), U5.40 (DRAIN)
unnamed: C42.1, C43.1, U5.4 (LDO_1V5)
unnamed: R50.1, U7.7 (ALRT)
unnamed: C58.1, R46.1, U7.12 (AOLDO)
unnamed: R44.1, U7.3 (CHG)
unnamed: C53.2, TP2.2, U7.2 (CP)
unnamed: R41.3, U7.14 (CSN)
unnamed: R41.2, U7.15 (CSP)
unnamed: R48.1, U7.4 (DIS)
unnamed: C52.1, C53.1, R42.2, TP2.1, U7.1 (IN)
unnamed: R45.1, U7.6 (PCKP)
unnamed: R43.1, U7.11 (PFALL)
unnamed: C56.1, U7.17 (REG2)
unnamed: C55.1, TP3.1 (1_1), U7.13 (REG3)
unnamed: TH4.1, U7.10 (TH1)
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

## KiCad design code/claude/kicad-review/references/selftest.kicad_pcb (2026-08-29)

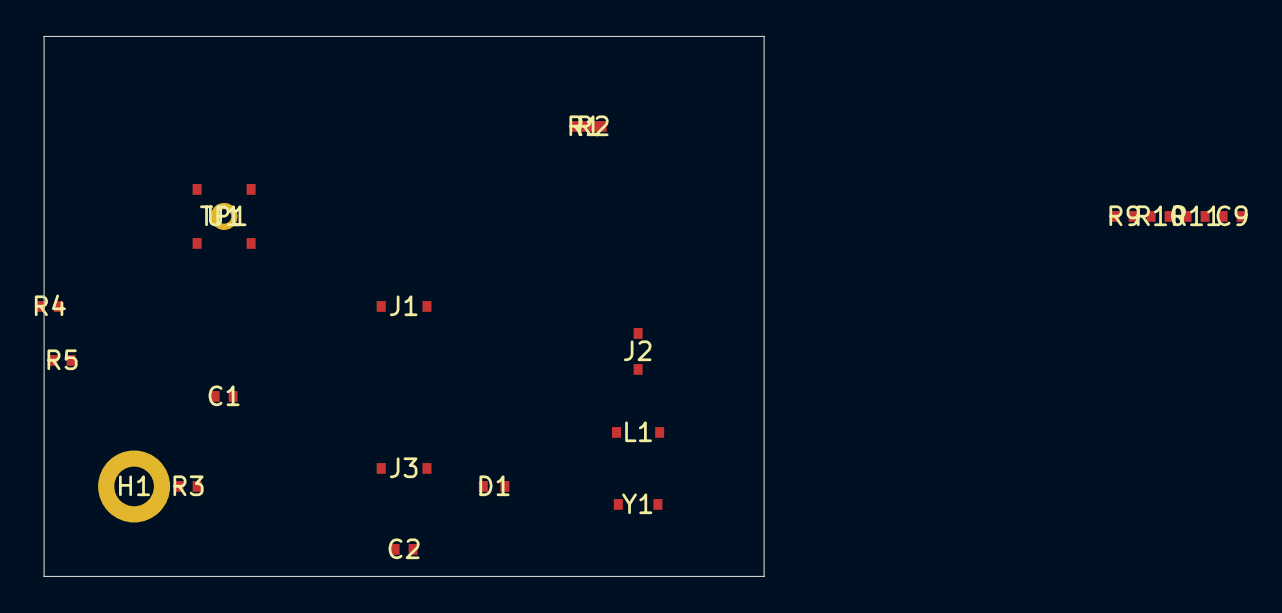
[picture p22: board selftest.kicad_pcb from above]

Board: 2 copper layers, 40.0 x 30.0 mm, 20 parts (1 on the bottom side), 3 nets, no tracks yet.

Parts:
C1: 100nF; FP
C2: 1uF; FP
C9: 10k; FP
D1: LED; FP
H1: MountingHole; MountingHole_2.2mm_M2_DIN965_Pad
J1, J3: HDR; PinHeader_1x02_P2.54mm_Vertical
J2: Conn_Coaxial; U.FL_Hirose_U.FL-R-SMT-1_Vertical
L1: 2.2uH; L_4x4mm
R1, R2, R9, R10, R11: 10k; FP
R3: 1k; FP
R4, R5: 0R; FP
TP1: TP; TestPoint_Pad_D1.5mm
U1: MCU_OK; FP
Y1: 32.768kHz; Crystal_SMD_3215-2Pin_3.2x1.5mm

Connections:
+3V3: C1.1, U1.1 (VDD)
GND: C1.2, C2.2, D1.2, J2.2, TP1.1, U1.2 (GND)
NB: R1.2, R2.1

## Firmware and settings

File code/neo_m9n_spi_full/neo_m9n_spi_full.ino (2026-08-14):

/*
 * NEO-M9N GNSS reader (SPI)  --  parsnip-node / Seeed XIAO ESP32-C6
 *
 * Use once D_SEL is bridged to GND (SPI selected). Shares the SPI bus with the
 * SX1262, so each device has its own chip select; the radio's NSS is held high
 * here so it releases MISO while the GNSS is addressed.
 *
 * Reads the module by clocking 0xFF and streaming the reply into a
 * checksum-validated UBX state machine. 0xFF is the module's idle byte but can
 * also appear inside a payload, so nothing is filtered: the parser only acts on
 * frames whose Fletcher checksum matches, and a drain stops only when 0xFF runs
 * appear at a packet boundary (buffer genuinely empty).
 *
 * Datasheet limits (UBX-19014285): SPI max clock 5.5 MHz, but max DATA rate only
 * 125 kB/s. 1 MHz sits on that ceiling and invites mid-frame 0xFF stuffing, so
 * this runs at 250 kHz. CPOL = 0, CPHA = 0 => SPI_MODE0.
 *
 * Decodes NAV-PVT, MON-VER, MON-RF, MON-SPAN, MON-GNSS, NAV-SAT and CFG-VALGET.
 *
 * ---------------------------------------------------------------------------
 * CURRENT DIAGNOSTIC STATE (2026-07)
 *
 * Front end is confirmed healthy and confirmed fed:
 *
 *                     AGC            MON-SPAN PGA   Noise   magI/magQ
 *   good antenna      1755 (21%)     15 dB          100     172/168
 *   weak antenna      3510 (43%)     30 dB           95     160/155
 *   no antenna        5265 (64%)     45 dB           94     152/144
 *
* antenna on 2106 (26%), antenna off ~5980 (73%), PGA 18 dB, magI/magQ ~37/37.
*
 * Three independent loops agree that the good antenna's LNA is delivering: AGC,
 * PGA, and the swap between the two antennas moving both by the same ratio. The
 * MON-SPAN passband is correctly positioned over L1. And NAV-SAT still reports
 * zero satellites outdoors.
 *
 * Every healthy reading above is a BROADBAND POWER measurement. AGC, PGA,
 * noisePerMS, magI/magQ and MON-SPAN all work correctly regardless of what
 * frequency the internal TCXO is actually running at. Correlation is the only
 * thing that depends on the reference being right, and correlation is the only
 * thing failing. Nothing in the module measures its own reference.
 *
 * At L1, 1 ppm of oscillator error is 1575 Hz of apparent Doppler. Cold-start
 * frequency search windows are order +/-10 kHz, so past roughly 6 ppm satellites
 * start dropping out and past 20 ppm acquisition is impossible. A healthy TCXO
 * is inside +/-2 ppm. This module has been through repeated hot-air rework.
 *
 * So this build adds three things:
 *
 *   1. TP TEST      Route the raw local oscillator to TIMEPULSE so the TCXO
 *                   error can be measured on external gear. See the TP TEST
 *                   block. This is the primary experiment.
 *   2. CFG READBACK Poll the per-signal CFG-SIGNAL-* keys individually.
 *                   MON-GNSS reports major constellation enables only; it does
 *                   NOT report GPS_L1CA_ENA. On an L1-only M9N, GPS_ENA=1 with
 *                   GPS_L1CA_ENA=0 gives exactly the symptom seen here.
 *   3. AIDING       Inject rough UTC time (from NTP over WiFi, then WiFi off
 *                   again before acquisition) with UBX-MGA-INI-TIME_UTC, and
 *                   optionally position with MGA-INI-POS_LLH. This collapses
 *                   the search space. If it acquires WITH aiding and not
 *                   without, that confirms a search-window problem, which is
 *                   the clock hypothesis from the other direction.
 *
 * Also confirmed by measurement and worth not relearning:
 *   - AGC direction: removing input power makes agcCnt RISE.
 *   - AGC at 21% with a good active antenna is NORMAL. Not evidence of jamming.
 *   - magI/magQ sit after the AGC and stay near 150 either way, so they cannot
 *     detect a missing antenna. Only their ratio is meaningful.
 *   - antStatus reports "OK, power ON" with nothing connected. Useless here,
 *     because ANT_DETECT is not wired and LNA_EN (U2 pin 14) only goes to TP1.
 *   - The single-bin spike at the exact MON-SPAN centre persists with the
 *     antenna removed, so it is internal. The integration manual says the same.
 *   - Measured bias-T current: 46 mV across R13 (10R) = 4.6 mA. The manual
 *     gives 5-20 mA typical for an active antenna, so this is just under range.
 *
 * MON-SPAN amplitudes are uint8 with no documented dB-per-LSB, so they are
 * printed as COUNTS, not dB. A "115 count" peak-to-trough is a normal SAW
 * shape of roughly 25-30 dB, not a catastrophe. Do not compare traces across
 * captures with different PGA values.
 * ---------------------------------------------------------------------------
 *
 * Wiring (matches the SPI bring-up net list):
 *   SCK    -> GPIO19      MISO -> GPIO20      MOSI -> GPIO18
 *   CS_GPS -> GPIO2  (through R3)
 *   TIMEPULSE -> JP1 / JP2 (probe here for the TP TEST)
 *
 * RF QUIET: this sketch is a GNSS-only bring-up tool, so it shuts down every
 * other transmitter on the board. ESP32-C6 WiFi and BLE are stopped and the BLE
 * controller's RAM is handed back to the heap, which makes BLE unstartable until
 * the next reset. The E22P is put in its CLOSE state (EN low) and the SX1262 is
 * put in cold-start sleep, optionally then held in reset. The E22P VCC rail
 * itself stays up: U5's EN is strapped to its own VIN.
 *
 * ORDERING MATTERS with aiding enabled. WiFi is a 2.4 GHz transmitter sitting a
 * few mm from the GNSS antenna feed. The sequence is: LoRa pins safe -> WiFi up
 * -> NTP -> WiFi fully down and deinitialised -> everything else. No GNSS
 * measurement in this sketch is ever taken with the WiFi PHY powered.
 *
 *   LoRa EN   -> GPIO17 (R17 10k pull-down)     LoRa NRST -> GPIO16 (R15 10k to +5V)
 *   LoRa NSS  -> GPIO21 (through R4)            LoRa BUSY -> GPIO7
 *   LoRa DIO1 -> GPIO1                          T/R CTRL  -> DIO2 only, no MCU access
 */

#include <SPI.h>
#include <Preferences.h>
#include <WiFi.h>
#include <time.h>
#include "esp_wifi.h"
#if defined(CONFIG_BT_ENABLED)
#include "esp_bt.h"
#endif

// GPIO16/GPIO17 are U0TXD/U0RXD on the C6 and are wired to LoRa NRST and EN on
// this board. If Serial lands on UART0 instead of USB CDC, the console would be
// bit-banging the radio's reset line.
#if !defined(ARDUINO_USB_CDC_ON_BOOT) || ARDUINO_USB_CDC_ON_BOOT == 0
#warning "Serial is on UART0 (GPIO16/17) = LoRa NRST/EN. Enable USB CDC on boot."
#endif

// ================= CREDENTIALS =================
//
// This repository is PUBLIC (github.com/LimesKey/parsnip-node, GPL-3.0). Do not
// commit a real SSID and password. Once this builds, move them into a local
// secrets.h and add that file to .gitignore:
//
//     // secrets.h  (git-ignored)
//     #define WIFI_SSID "your-ssid"
//     #define WIFI_PASS "your-password"
//
// If secrets.h exists it wins; the fallback below is only so this compiles now.
// Also worth knowing: WiFi credentials written by esp_wifi are cached in the
// ESP32's NVS partition, so `esptool.py erase_flash` before handing the board to
// anyone or posting flash dumps.
#if defined(__has_include)
#if __has_include("secrets.h")
#include "secrets.h"
#endif
#endif
#ifndef WIFI_SSID
#define WIFI_SSID "Dragon"
#define WIFI_PASS "strawberry"
#endif

// ---------------- CONFIG ----------------
#define CS_PIN 2  // CS_GPS (GPIO2, through R3)
#define SCK_PIN 19
#define MISO_PIN 20
#define MOSI_PIN 18
#define SPI_HZ 250000   // 250 kHz: under the 125 kB/s data ceiling for contiguous frames
#define PPS_PIN -1      // set if PPS is broken out; -1 to skip
#define DRAIN_MS 250    // how often to drain the module's SPI buffer
#define DRAIN_MAX 4096  // safety cap on bytes clocked per drain
#define IDLE_RUN 4      // consecutive 0xFF at a packet boundary => buffer empty
#define DIAG_MS 10000   // how often to poll MON-RF + MON-SPAN + NAV-SAT
#define SPAN_COLS 64    // ASCII spectrum width
#define SPAN_ROWS 16    // ASCII spectrum height
#define NAV_PVT_RATE 5  // NAV-PVT every Nth epoch; 1 Hz buries the diagnostics

// CFG WRITE PERSISTENCE.
// The previous build wrote every config change to layers RAM|BBR|Flash (0x07) on
// EVERY BOOT. Flash on the M9 has finite write endurance and a flash-layer write
// is slow, so a bring-up loop that reflashes on each reset is burning the part
// for no reason. RAM-only is the right default for experiments: it survives
// until power-down, which is the whole session. Set to 1 only when a setting has
// earned permanence.
#define CFG_PERSIST 0
#if CFG_PERSIST
#define CFG_LAYERS 0x07  // RAM | BBR | Flash
#else
#define CFG_LAYERS 0x01  // RAM only
#endif

// AGC thresholds, measured on THIS board with THIS antenna (see header notes).
// AGC_HOT was 1000, but the good antenna's observed floor is 1053, which would
// have tripped the warning constantly. 800 leaves margin.
#define AGC_NO_ANTENNA 4500  // at or above this, nothing is feeding the front end
#define AGC_HOT 800          // below this, more power than the LNA alone explains

#define ENABLE_ITFM 1    // switch the interference monitor on at boot
#define ITFM_ANT_TYPE 2  // 0 = unknown, 1 = passive, 2 = active
#define GPS_ONLY 1       // disable GLO/BDS/GAL: all four split the correlators
// ----------------------------------------

// ================= TP TEST (TCXO frequency measurement) =================
//
// THE POINT: CFG-TP-SYNC_GNSS_TP1 = 0 makes the time pulse run off the LOCAL
// OSCILLATOR instead of GNSS-derived frequency. That routes the TCXO, divided
// down, straight to a pin. Fractional error at the pin equals fractional error
// of the reference, so 4 MHz reading 4.000120 MHz is 30 ppm and the diagnosis
// is over.
//
// MEASURE IT ON A FREQUENCY COUNTER, NOT THE SCOPE. A scope timebase is
// typically +/-25 to +/-50 ppm, the same order as the fault. The scope can only
// catch a gross failure in the hundreds of ppm. Humber's bench counters are
// reciprocal-interpolating and will resolve sub-ppm in a 1 s gate; the CXA's
// frequency reference also works.
//
// Frequency ceiling: the integration manual says neither the high nor the low
// period may be under 50 ns, which caps 50% duty at 10 MHz. 4 MHz has margin.
// FREQ_TP1 is unlikely to be an exact integer divisor of the internal clock, so
// the output will be dithered cycle to cycle. A counter averages that out; a
// single-shot period measurement will not.
#define TP_TEST 1
#define TP_TEST_FREQ_HZ 4000000UL
#define TP_TEST_DUTY 50.0  // percent, sent as R8 double (NOT an integer)
// ========================================================================

// ================= AIDING (MGA-INI) =================
// Injects rough UTC time, and optionally position, to collapse the acquisition
// search space. Time comes from NTP; WiFi is brought up and then fully torn down
// before any GNSS measurement.
#define ENABLE_AIDING 1
#define WIFI_TIMEOUT_MS 15000
#define NTP_TIMEOUT_MS 10000
#define AID_LEAP_SECS 18  // UTC-GPS offset, 18 since 2017-01-01

// Position aiding. Deliberately OFF by default: this is a public repo and your
// home coordinates would be committed in plaintext. Fill these in locally only,
// or put them in secrets.h alongside the WiFi credentials. +/-5 km is plenty of
// accuracy to be useful, so round them off; you do not need your driveway.
#define AID_POS 0
#ifndef AID_LAT_DEG
#define AID_LAT_DEG 0.0
#define AID_LON_DEG 0.0
#define AID_ALT_M 100
#endif
#define AID_POS_ACC_M 5000
// ====================================================

// ------------- FACTORY RESET -------------
// DO_FACTORY_RESET    compile the reset path in at all
// RESET_TOKEN         latched in NVS; change the string to arm another run
// RESET_KEEP_SPI      re-set CFG-SPI-ENABLED=1 after the wipe. The M9 default for
//                     this key is 0 (false). Whether D_SEL=GND overrides that at
//                     the port level is not documented, and this board has no
//                     UART/I2C fallback, so leaving it at 1 is the safe choice.
//                     This one write DOES go to flash, deliberately: if SPI does
//                     not survive the next power cycle the board is unreachable.
// RESET_ENABLE_NAV_PVT  also re-enable NAV-PVT on SPI (default is 0; NMEA GGA
//                     defaults to 1, which this UBX-only parser will ignore).
#define DO_FACTORY_RESET 0
#define RESET_TOKEN "fr-2026-07-a"
#define RESET_KEEP_SPI 1
#define RESET_ENABLE_NAV_PVT 1
// ----------------------------------------

SPISettings gnssSpi(SPI_HZ, MSBFIRST, SPI_MODE0);  // u-blox: CPOL=0, CPHA=0

static inline void csLow() {
  digitalWrite(CS_PIN, LOW);
}
static inline void csHigh() {
  digitalWrite(CS_PIN, HIGH);
}

// ---- little-endian field readers ----
static inline uint32_t u32(const uint8_t* p) {
  return (uint32_t)p[0] | ((uint32_t)p[1] << 8) | ((uint32_t)p[2] << 16) | ((uint32_t)p[3] << 24);
}
static inline int32_t i32(const uint8_t* p) {
  return (int32_t)u32(p);
}
static inline uint16_t u16(const uint8_t* p) {
  return (uint16_t)p[0] | ((uint16_t)p[1] << 8);
}

bool gotData = false;  // set once any valid UBX frame is decoded

// ---- parser health counters -------------------------------------------------
// The 0xA8 history on this board means a lossy SPI read is a live possibility,
// and a lossy read looks exactly like "no satellites" if a variable-length
// message such as NAV-SAT gets mangled. These make that visible instead of
// silent: a rising ubxBad with a healthy ubxGood means bytes are being dropped
// mid-frame, and nothing downstream of the parser can be trusted.
uint32_t ubxGood = 0, ubxBad = 0, ubxOverflow = 0;

// ACK/NAK latch, consumed by sendWaitAck()
volatile bool ackSeen = false, ackOk = false;
volatile uint8_t ackCls = 0, ackId = 0;

// forward declarations (these are called from setup(), which appears before them
// in this file; the .ino preprocessor usually inserts prototypes but relying on
// that is how you get a build that breaks when someone renames the file)
void drainGNSS();
void sendUBX(uint8_t cls, uint8_t id, const uint8_t* p, uint16_t len);
bool sendWaitAck(uint8_t cls, uint8_t id, const uint8_t* p, uint16_t len, uint32_t timeoutMs);
bool ubxSetGpsOnly();
bool ubxEnableItfm(uint8_t antType);
bool ubxConfigureTimepulse();
void ubxDumpCriticalKeys();
void factoryResetOnce();
bool ntpSync();
void injectAiding();

// ---- decoders ----
const char* fixName(uint8_t t) {
  switch (t) {
    case 0: return "no fix";
    case 1: return "dead reckoning";
    case 2: return "2D";
    case 3: return "3D";
    case 4: return "GNSS + dead reckoning";
    case 5: return "time only";
    default: return "unknown";
  }
}

const char* gnssName(uint8_t id) {
  switch (id) {
    case 0: return "GPS";
    case 1: return "SBAS";
    case 2: return "GAL";
    case 3: return "BDS";
    case 4: return "IMES";
    case 5: return "QZSS";
    case 6: return "GLO";
    default: return "?";
  }
}

// UBX-NAV-PVT (class 0x01 id 0x07, 92-byte payload)
void printNavPvt(const uint8_t* p) {
  uint16_t year = u16(p + 4);
  uint8_t mon = p[6], day = p[7];
  uint8_t hh = p[8], mm = p[9], ss = p[10];
  uint8_t valid = p[11];
  uint8_t fixType = p[20], flags = p[21], numSV = p[23];
  bool fixOK = flags & 0x01;
  int32_t lon = i32(p + 24), lat = i32(p + 28);
  int32_t hEllip = i32(p + 32), hMSL = i32(p + 36);
  uint32_t hAcc = u32(p + 40), vAcc = u32(p + 44);
  int32_t gSpeed = i32(p + 60), headMot = i32(p + 64);
  uint32_t sAcc = u32(p + 68);
  uint16_t pDOP = u16(p + 76);

  bool vDate = valid & 0x01, vTime = valid & 0x02, resolved = valid & 0x04;

  Serial.println();
  Serial.printf("[GNSS] %04u-%02u-%02u %02u:%02u:%02u UTC   (date %s, time %s%s)\r\n",
                year, mon, day, hh, mm, ss,
                vDate ? "valid" : "invalid",
                vTime ? "valid" : "invalid",
                resolved ? ", fully resolved" : "");

  Serial.printf("       Fix: %s%s   satellites: %u   pDOP: %.2f\r\n",
                fixName(fixType), fixOK ? "" : " (not usable)", numSV, pDOP / 100.0);

  if (fixOK) {
    Serial.printf("       Position: %.7f, %.7f\r\n", lat * 1e-7, lon * 1e-7);
    Serial.printf("       Altitude: %.2f m MSL   (%.2f m ellipsoid)\r\n",
                  hMSL / 1000.0, hEllip / 1000.0);
    Serial.printf("       Motion:   %.2f m/s   heading %.1f deg\r\n",
                  gSpeed / 1000.0, headMot * 1e-5);
    Serial.printf("       Accuracy: horiz %.2f m   vert %.2f m   speed %.2f m/s\r\n",
                  hAcc / 1000.0, vAcc / 1000.0, sAcc / 1000.0);
  } else {
    Serial.println("       Position: not available (waiting on satellites / antenna)");
  }

  // With aiding injected, a plausible date here and validTime set is proof the
  // MGA-INI-TIME_UTC landed, without needing MGA-ACK enabled.
#if ENABLE_AIDING
  if (year >= 2026 && vTime)
    Serial.println("       >> time is valid and plausible: aiding was accepted.");
#endif
}

// UBX-MON-VER (class 0x0A id 0x04): 30-byte SW, 10-byte HW, then 30-byte extensions
void printMonVer(const uint8_t* p, uint16_t len) {
  char buf[31];
  Serial.println("\r\n[GNSS] Firmware (UBX-MON-VER):");
  if (len >= 30) {
    memcpy(buf, p, 30);
    buf[30] = 0;
    Serial.printf("       SW: %s\r\n", buf);
  }
  if (len >= 40) {
    memcpy(buf, p + 30, 10);
    buf[10] = 0;
    Serial.printf("       HW: %s\r\n", buf);
  }
  for (uint16_t o = 40; o + 30 <= len; o += 30) {
    memcpy(buf, p + o, 30);
    buf[30] = 0;
    if (buf[0]) Serial.printf("       %s\r\n", buf);
  }
}
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
void loop() {
  if (millis() - lastDrain >= DRAIN_MS) {
    lastDrain = millis();
    drainGNSS();
  }

  if (millis() - lastDiag >= DIAG_MS) {
    lastDiag = millis();
    sendUBX(0x0A, 0x38, nullptr, 0);  // poll MON-RF
    sendUBX(0x0A, 0x31, nullptr, 0);  // poll MON-SPAN
    sendUBX(0x0A, 0x28, nullptr, 0);  // poll MON-GNSS
    sendUBX(0x01, 0x35, nullptr, 0);  // poll NAV-SAT

    // Parser health. A nonzero ubxBad that climbs alongside ubxGood means the
    // SPI read is dropping bytes mid-frame, and no count reported above can be
    // trusted until that is fixed.
    Serial.printf("\r\n[parse] frames ok %lu   checksum fail %lu   oversize %lu   "
                  "uptime %lu s\r\n",
                  (unsigned long)ubxGood, (unsigned long)ubxBad,
                  (unsigned long)ubxOverflow, (millis() - startMs) / 1000);
    if (ubxBad > 0 && ubxBad * 20 > ubxGood)
      Serial.println("[parse] >> over 5% of frames failing checksum. Fix the SPI read "
                     "before trusting any diagnostic in this log.");
  }

  if (!gotData && !warned && millis() - startMs > 6000) {
    warned = true;
    Serial.println("\r\n[!] 6 s and no UBX frame decoded: bus is returning only 0xFF.");
    Serial.println("    Confirm D_SEL = GND (SPI selected) and power-cycle the module,");
    Serial.println("    and that the SX1262 NSS is held high so it isn't driving MISO.");
  }
}

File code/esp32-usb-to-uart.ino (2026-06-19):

#define NEO_RX 20      // ESP32 RX  <- NEO TXD  (your "MISO" net)
#define NEO_TX 18      // ESP32 TX  -> NEO RXD  (your "MOSI" net)
#define NEO_BAUD 9600

void setup() {
  Serial.begin(115200);  // USB CDC; PC-side baud is ignored over USB
  Serial1.begin(NEO_BAUD, SERIAL_8N1, NEO_RX, NEO_TX);
  pinMode(/*LoRa NSS*/ 21, OUTPUT);
  digitalWrite(/*LoRa NSS*/ 21, HIGH); // keep SX1262 off the shared MISO
}
void loop() {
  while (Serial.available())  Serial1.write(Serial.read());
  while (Serial1.available()) Serial.write(Serial1.read());
}

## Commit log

2026-06-01 inital commit
    [GNSS-NEO.kicad_sch, LORA-E22.kicad_sch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]
2026-06-16 commits for assembly
    [LORA-E22.kicad_sch, meshtastic.kicad_sch]
2026-06-18 show to ppl
    [GNSS-NEO.kicad_sch, LORA-E22.kicad_sch]
2026-07-01 Update schematics and rework NEO-M9N reader sketches
    [GNSS-NEO.kicad_sch, meshtastic.kicad_sch]
2026-07-21 pcb updates
    [GNSS-NEO.kicad_sch, LORA-E22.kicad_sch, meshtastic.kicad_sch]
2026-08-04 next revision pcb progress
    [GNSS-NEO.kicad_sch, LORA-E22.kicad_sch, Power.kicad_sch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]
2026-08-04 Apply updated .gitignore and untrack ignored files
    [meshtastic-CuBottom.gbr, meshtastic-CuIn1.gbr, meshtastic-CuIn2.gbr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]
2026-08-08 update schematic with new eFuse and add journal.md
    [GNSS-NEO.kicad_sch, LORA-E22.kicad_sch]
2026-08-08 revise efuse, add bat
    [GNSS-NEO.kicad_sch, LORA-E22.kicad_sch, Power.kicad_sch]
2026-08-11 add BMS and charge controller!
    [GNSS-NEO.kicad_sch, LORA-E22.kicad_sch, Power.kicad_sch]
2026-08-13 small update
    [Power.kicad_sch]
2026-08-13 update bms schematic, minor changes to rest
    [LORA-E22.kicad_sch, Power.kicad_sch]
2026-08-14 wired BQ25798 schematic
    [GNSS-NEO.kicad_sch, LORA-E22.kicad_sch, Power.kicad_sch]
2026-08-14 rename project to parsnip-node
    Repo renamed from limeskey-node to parsnip-node. Updates the README,
    clone URL, sketch headers/banners in code/, and the KiCad symbol library
    (lib/limeskey-node.kicad_sym -> lib/parsnip-node.kicad_sym plus its
    sym-lib-table entry). No schematic referenced that library, so no
    lib_id fixups were needed.
    Author handle (LimesKey) and PCB silkscreen text are unchanged.
    [neo_m9n_spi_full.ino, neo_m9n_spi_reader-testing.ino, neo_m9n_uart_reader-testing.ino]
2026-08-19 rename sheets, add lora antenna detect, seperate charger and regulator schematics, add eFuse to 5v output
    [Power.kicad_sch, battery.kicad_sch, gnss.kicad_sch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]
2026-08-19 Reworking power rails, adding antenna detection, and organization
    [battery.kicad_sch, gnss.kicad_sch, lora.kicad_sch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]
2026-08-20 push to work on laptop
    [battery.kicad_sch, lora.kicad_sch, rails.kicad_sch]
2026-08-22 push to work on laptop2
    [battery.kicad_sch, gnss.kicad_sch, lora.kicad_sch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]
2026-08-24 push for review, minor changes
    [battery.kicad_sch, gnss.kicad_sch, lora.kicad_sch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]
2026-08-24 change designator positions for clarity
    [battery.kicad_sch, lora.kicad_sch, parsnip.kicad_sch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]
2026-08-26 journal update!
    [battery.kicad_sch, gnss.kicad_sch, lora.kicad_sch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]
2026-08-26 plot schematic
2026-08-27 schematic for karl
2026-08-29 pcb layout!
    [battery.kicad_sch, gnss.kicad_sch, lora.kicad_sch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]
2026-08-30 Set firmware submodule to track latest limeskey-node-spi-gnss branch
2026-08-30 organize repo and schematic
    [battery.kicad_sch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]
2026-09-01 done pcb layout
    [battery.kicad_sch, gnss.kicad_sch, lora.kicad_sch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]
2026-09-01 Update plotted schematic pdf
2026-09-02 add 3d models locally
    [gnss.kicad_sch, parsnip.kicad_pcb, usb_interface.kicad_sch]
2026-09-02 slightly better component placement
    [lora.kicad_sch, parsnip.kicad_pcb]
2026-09-05 progress in layout!
    [battery.kicad_sch, gnss.kicad_sch, parsnip.kicad_pcb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]
2026-09-05 supporting datasheets and a footprint for a shunt resistor
